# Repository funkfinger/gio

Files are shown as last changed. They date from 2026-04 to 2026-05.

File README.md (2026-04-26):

# gio

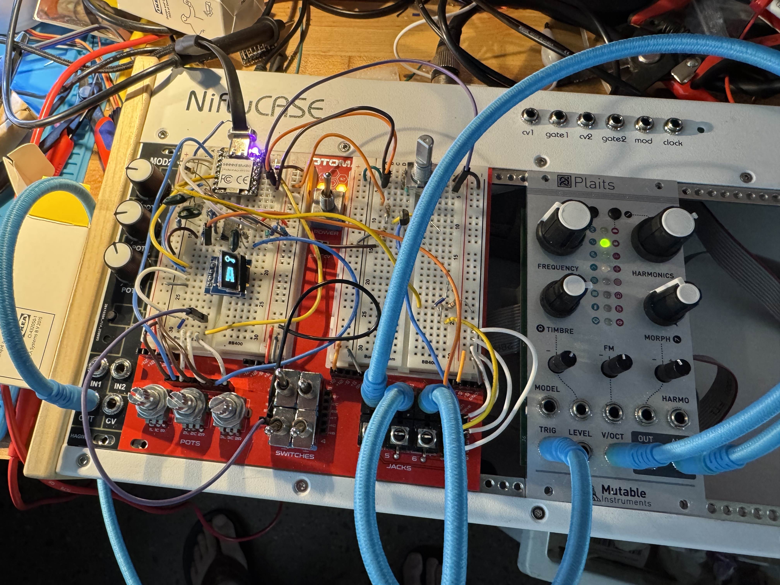
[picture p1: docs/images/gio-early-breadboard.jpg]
gio on the breadboard


A 2 HP Eurorack generative arpeggiator module built around the Seeed XIAO RP2350. Produces scale-quantised V/Oct pitch CV and gate outputs driven by a probability-layered generative engine. Open-source hardware and firmware.

Spiritual successor to [funkfinger/xiao-ra4m1-arp](https://github.com/funkfinger/xiao-ra4m1-arp), ported to the RP2350 with an encoder + OLED UI and an external I2C DAC (MCP4725) in place of the RA4M1's onboard DAC.

## Status

**Planning / pre-prototype.** No hardware fabricated yet; no firmware released. See [`docs/decisions.md`](docs/decisions.md) for the bring-up plan and [`docs/stories/`](docs/stories/) for the story-driven development backlog.

## Repo layout

```
gio/
├── firmware/arp/     PlatformIO project for the arpeggiator firmware
├── hardware/         KiCad project — populated post-breadboard validation
├── docs/             Specification, decisions, user stories
└── CHANGELOG.md      Keep a Changelog format; updated on every commit
```

## Documentation

- **[Specification](docs/generative-arp-module.md)** — hardware spec, firmware architecture, BOM, calibration
- **[Decisions](docs/decisions.md)** — tooling, scope, workflow, licensing, versioning
- **[Stories](docs/stories/)** — user-story-driven development backlog

## Toolchain

- **Firmware:** [PlatformIO](https://platformio.org/) with the earlephilhower Arduino-Pico platform (`board = seeed_xiao_rp2350`)
- **Tests:** host-side unit tests via `pio test -e native` for pure-logic modules (scales, arp, tempo). HAL is bench-verified.
- **Hardware:** KiCad (project deferred — see decisions)
- **CI:** GitHub Actions runs host tests on push and PR

## Versioning

- **Firmware:** [Semantic Versioning](https://semver.org/), scoped tags per firmware: `arp/v0.1.0`
- **Hardware:** `Rev N.M` notation, silkscreened on the PCB
- **Docs:** unversioned; history lives in `git log`

See [decisions §12](docs/decisions.md) for full rules.

## Licensing

| Area | License | File |
|---|---|---|
| Firmware | MIT | [`LICENSE-firmware`](LICENSE-firmware) |
| Hardware (KiCad, panel artwork) | Apache 2.0 | [`LICENSE-hardware`](LICENSE-hardware) |
| Documentation | CC-BY 4.0 | [`LICENSE-docs`](LICENSE-docs) |

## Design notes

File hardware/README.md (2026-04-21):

# hardware/

KiCad schematic and PCB for the gio module.

**This directory is intentionally empty until breadboard validation is complete.**

Per `docs/decisions.md` §7: the KiCad project is deferred until the breadboard signal chain (MCP4725 → MCP6002 → V/Oct output) is validated within ±2 mV of target voltages and the I2C bus sharing between DAC and OLED is confirmed clean.

The gate resistor value (R4) was a known source of V/Oct loading error in the predecessor project — confirmed to 100 Ω before PCB layout begins.

When ready, this directory will contain:

```
hardware/
├── gio.kicad_pro
├── gio.kicad_sch
├── gio.kicad_pcb
├── panel/
│   └── gio-panel.kicad_pcb
├── gerbers/
│   └── (generated outputs for JLCPCB)
└── bom/
    └── gio-bom.csv
```

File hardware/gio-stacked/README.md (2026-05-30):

# gio-stacked

A 4 HP Eurorack module — three-board stacked redesign of `hardware/gio/`.

## Status

**Planning / scaffolding.** No KiCad files yet. This directory captures the
architecture decisions before schematic work begins. Each subdirectory
(`power/`, `signal/`, `faceplate/`) will become its own KiCad project in a
subsequent session.

## Why split into three boards

The original `hardware/gio/` is a single 4 HP PCB. That layout was tight
but workable for the v0.1 feature set. The expanded feature set for this
revision — 6 jacks (was 4), tap-tempo button, same OLED + pot + encoder —
runs out of PCB area on a single-board 4 HP design once you account for the
through-hole jacks, the OLED breakout footprint, the encoder + pot bodies,
and the Eurorack power header + bulk caps + regulators.

Three stacked boards solve this by trading depth for area:

| Board | Carries |
|---|---|
| **power/** | Eurorack ±12 V header + reverse-polarity + bulk caps + +5 V LDO + REF3040 (4.096 V reference) |
| **signal/** | XIAO RP2350 + DAC8552 + MCP3208 + TL072 input/output op-amp stages + NeoPixel |
| **faceplate/** | 6× Thonkiconn jacks + PEC11 encoder + Alpha 9 mm pot + SSD1306 OLED + tactile button + panel silkscreen |

The faceplate is a real PCB (not just a milled aluminum panel) — it carries
the jacks, OLED breakout footprint, and button, and connects to the signal
board through a single 2.54 mm pin header.

## Inheritance from `hardware/gio/`

Direct re-use (schematic blocks, footprints, calibration):

- **MCU** — Seeed XIAO RP2350
- **DAC** — TI DAC8552 (12-bit, dual, SPI)
- **ADC** — MCP3208 (12-bit, 8-channel, SPI). Now uses CH3 + CH4 for the two new CV ins.
- **Reference** — TI REF3040 (4.096 V, 0.2 %)
- **Op-amps** — TL072 × 2 (±12 V rails). Same input scaling stage (100 kΩ + 22 kΩ + BAT54S clamp + 22 kΩ feedback) replicated 4× for the four CV ins. Same output stage (44 kΩ feedback + 1 kΩ jack series + BAT54S clamp) × 2 for the two outs.
- **Calibration** — copy the bench-fit constants from `firmware/arp/src/main.cpp`
  (channel-symmetric op-amp stages — see `bench-log.md` 2026-05-21).

New for this revision:

- **2 additional CV inputs** (J5, J6) — same scaling stage as J1/J2, routed to MCP3208 CH3 + CH4.
- **Tap-tempo / reset button** — tactile switch on faceplate, wired to XIAO D0 (currently free; was the analog pot pin pre-pivot).
- **Inter-board connectors** — 2.54 mm pin headers (see `docs/interconnect.md`).
- **Mechanical stack** — M2.5 standoffs at 4 corners (see `docs/stackup.md`).

## Panel layout target (4 HP × 128.5 mm)

Top to bottom:

```
┌────────────┐
│   OLED     │  64×32 SSD1306
├────────────┤
│  encoder   │  PEC11 + click
├────────────┤
│    pot     │  Alpha 9 mm
├────────────┤
│   button   │  6×6 mm tactile (tap-tempo)
├────────────┤
│  J1    J2  │  CV in 1   CV in 2 (clock in / V/oct)
│  J3    J4  │  CV in 3   CV in 4 (new — modulation dests)
│  J5    J6  │  CV out    Trigger out (V/oct, gate)
└────────────┘
```

Two columns of 3 jacks fit in 4 HP with 6 mm Thonkiconn nuts at ~7 mm
center-to-center pitch. Final positions in `docs/faceplate-layout.md`.

## Project layout

```
hardware/gio-stacked/
├── README.md                  ← this file
├── docs/
│   ├── decisions.md           ← architecture rationale, decisions log
│   ├── interconnect.md        ← board-to-board pin assignments
│   ├── faceplate-layout.md    ← panel positions, hole sizes, silkscreen
│   └── stackup.md             ← mechanical: standoffs, board heights, clearances
├── power/                     ← Power board KiCad project (TBD)
├── signal/                    ← Signal board KiCad project (TBD)
└── faceplate/                 ← Faceplate KiCad project (TBD)
```

## BOM additions vs `hardware/gio/`

- 2× Thonkiconn PJ-3.5mm jacks (6 total instead of 4)
- 1× tactile button (Omron B3F-1000 or equivalent, 6×6 mm)
- 2× 2.54 mm pin header + socket pairs (1× 2×5 power↔signal, 1× 2×14 or 2×16 signal↔faceplate)
- 4× M2.5 standoffs (length TBD — see `docs/stackup.md`)
- 8× M2.5 screws

Everything else (XIAO, DAC, ADC, op-amps, reference, OLED, encoder, pot, BAT54S, decoupling caps, resistors) is the same as `hardware/gio/bom.md` — quantities adjust per board.

## Build / fabrication plan (rough)

1. Schematic for each of the 3 boards (this is the next session's work).
2. Mechanical mockup — print 1:1 paper templates of all three boards + faceplate to verify spacing before PCB layout.
3. Place + route signal board first (densest, hardest constraint).
4. Place + route power board.
5. Place + route faceplate (mostly through-hole, easy).
6. ERC + DRC pass on all three.
7. Manufacturing files (gerbers, BOM, CPL) per board.
8. JLCPCB order (3 boards × 5 each = 15 PCBs; ~$30 with shipping).
9. Hand-assemble + bench-bring-up each board independently before stacking.

## Open questions (deferred)

- Exact standoff height — depends on tallest signal-board component (likely bulk caps; finalized at parts-placement time).
- Whether the NeoPixel stays on the XIAO board (signal stack) or migrates to the faceplate for visibility through a light-pipe.
- Whether to add a second button (encoder-already-has-click, tap-tempo separately, plus a third would need pin budget review).

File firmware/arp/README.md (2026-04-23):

# firmware/arp

PlatformIO project for the gio arpeggiator firmware targeting the Seeed XIAO RP2350.

## Prerequisites

- [PlatformIO Core](https://docs.platformio.org/en/latest/core/installation/index.html) (CLI) or PlatformIO IDE extension
- USB-C cable

## Build

```bash
pio run -d firmware/arp
```

## Upload

```bash
pio run -d firmware/arp --target upload
```

That's it — **no button-press needed for normal re-flashes.** PlatformIO uses `picotool` as the default upload protocol for this board, and the running firmware exposes a USB endpoint that lets `picotool` send a "reboot to bootloader" request. The board soft-resets, picotool flashes, then it reboots into the new firmware.

You only need manual BOOTSEL when:

- **First-flash of a fresh XIAO** (no firmware to soft-reset from yet).
- **Firmware is hung / crashed before USB came up** (rare — you'd notice the board not appearing in `ls /dev/tty.usbmodem*`).
- You ever flash bare metal or strip out the picotool USB endpoint.

### Manual BOOTSEL (when needed)

The "double-tap BOOT" trick advertised by Seeed is **unreliable on the XIAO RP2350 units we've used** — bench-confirmed across many flashes during Stories 002–010. The method that always works:

1. Unplug USB.
2. Hold the BOOT button down.
3. Plug USB in (still holding BOOT).
4. Release BOOT — `RP2350` mounts as a drive.

Then run the upload command as above (in this state, picotool detects BOOTSEL directly without needing the soft-reset path).

## Host-side unit tests

Pure-logic modules (scales, arp, tempo) are tested on the host — no board required:

```bash
pio test -d firmware/arp -e native
```

GoogleTest requires an explicit `main()` in each test file (PlatformIO 6.x does not auto-link `gtest_main`).

## Serial monitor

```bash
pio device monitor -d firmware/arp
```

Baud rate: 115200.

## Library notes

- **Adafruit SSD1306 + GFX** — OLED driver. Three-constant config block in `lib/oled_ui/oled_ui.h` (`OLED_WIDTH`, `OLED_HEIGHT`, `OLED_ROTATION`) handles the swap between bench (0.91" 128×32 landscape) and final design (0.49" 64×32 portrait).
- **mathertel/RotaryEncoder** — polling-based quadrature encoder. RP2350-compatible. `paulstoffregen/Encoder` is incompatible (AVR-only register macros). LatchMode = `FOUR3` for our PEC11 build (decisions §17).
- **Adafruit NeoPixel** — onboard RGB LED on **GPIO22** (data) + **GPIO23** (power-enable, hold HIGH). LED is **RGBW** — initialise with `NEO_GRBW + NEO_KHZ800`. Neither pin is exposed by the arduino-pico variant header; both are hardcoded in `src/main.cpp`.

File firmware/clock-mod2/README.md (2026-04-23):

# firmware/clock-mod2

Minimal bench clock source for a HAGIWO MOD2 board populated with a XIAO RP2350. Exists primarily to feed a clock signal into `gio`'s J1 input during Story 010 bring-up and beyond — but it's a standalone useful module on its own.

## What it does

- **POT1 (A0)**: sets the clock rate. Exponential curve, 20–300 BPM (via the shared `tempo::potToBpm()`).
- **GP1**: drives the MOD2 output stage. 50 % duty square wave — scaled to ~0→10 V at the jack by the on-board op-amp.
- **GP5**: panel LED blinks in sync with each rising edge. Works on USB power alone, so you can verify the rate before putting the module back in the rack.
- POT2, POT3, CV in, button, IN1, IN2: unused in v1.

## Hardware requirements

- HAGIWO MOD2 PCB, populated with XIAO RP2350.
- **C18 (1 µF series cap on the OUT path) must be bypassed** for DC coupling. JP2 is *meant* to do this — see "JP2 board issue" below.
- ±12 V Eurorack power for the op-amp output stage. USB power alone runs the XIAO and LED but the output stays at 0 V.

## JP2 board issue (this build, Rev A)

The MOD2 schematic shows JP2 as a solder-bridge bypass across C18 (1 µF). When the bridge is closed, the OUT path is DC-coupled and produces clean 0→10 V gates. When open, the path is AC-coupled through C18 and an output square wave appears at the J6 jack as differentiated spikes (positive and negative, decaying with τ ≈ 100 ms via R20 = 100 kΩ).

**On this physical build, soldering JP2 had no effect.** Multimeter continuity confirmed JP2's pads were bridged after soldering, but the bypass didn't reach C18 — apparently the JP2 PCB traces don't route to C18's pads on this revision (board defect or layout error). Confirmed by directly clipping across C18's terminals: signal becomes a clean square wave immediately.

**Fix on this build:** solder a small wire (or 0 Ω resistor) directly across C18's pads. Permanent and reliable.

**Lesson for gio Rev 0.1 PCB:** before fab, verify that every solder-jumper symbol's connections in the schematic actually route to the correct nets in the layout (a quick ERC + DRC + visual on the JP nets). See `docs/decisions.md` "Deferred decisions" for the gio implication.

## Build

```bash
pio run -d firmware/clock-mod2
```

Shares toolchain with `firmware/arp` — the same pinned `framework-arduinopico@4.4.0` via `maxgerhardt/platform-raspberrypi`. Reuses `../arp/lib/tempo/` via `lib_extra_dirs` so BPM math stays in lock-step with gio.

## Upload

```bash
pio run -d firmware/clock-mod2 --target upload
```

Same workflow as the gio firmware — `picotool` soft-resets the board into BOOTSEL via USB, no button-press needed for normal re-flashes. Manual BOOTSEL only required for first-flash of a fresh XIAO or recovery. See `firmware/arp/README.md` for the manual procedure.

## Serial monitor

```bash
pio device monitor -d firmware/clock-mod2
```

Baud: 115200. Mostly quiet — just a startup banner.

## Wiring from MOD2 jack to gio J1

For Story 010 bench use:

- **MOD2 J6 (OUT)** tip → **gio J1** tip (through the 100 k + 100 k divider we're building for J1).
- **MOD2 GND** → **gio GND** (through the common Eurorack ground, or a jumper if both on the same bench).

MOD2 is an ~0→10 V gate source; gio's input divider brings that down to a safe ADC level.

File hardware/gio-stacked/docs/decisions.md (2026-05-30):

# gio-stacked architecture decisions

Scoped to this subproject. The parent `/docs/decisions.md` covers
platform-level decisions; this file covers what's specific to the
three-board redesign.

---

## 1. Three stacked boards (power / signal / faceplate)

A single 4 HP PCB ran out of area for the expanded feature set (6 jacks
instead of 4, tap-tempo button, same OLED + pot + encoder). Splitting into
three depth-stacked boards trades vertical real estate for layout headroom.

**Why three (not two):**
- Faceplate must be a PCB to hold jacks + encoder + pot + button + OLED on its back side — that's one PCB by necessity
- Power circuitry (Eurorack header, bulk caps, ±12 V regulators, REF3040) on its own board isolates supply noise from the signal-domain analog stages and keeps the heavy/bulky components (caps, regulators) at the back of the module
- Signal board in the middle is pure SMD — easy to lay out densely without competing for area with through-hole jacks or bulk power components

**Why not two (signal + faceplate, with power on the signal board):**
- Tried mentally — power components compete with the dense SMD analog stages for area on signal. Splitting them out lets each board be optimized for its dominant component class.

## 2. 2.54 mm pin-header interconnect (vs board-to-board / castellated)

Standard 0.1" pin headers with female sockets across each board junction.

**Why:**
- Trivially sourceable, cheap (~$0.50 per pair).
- Hand-solderable on both sides.
- Probable at each pin for bench debugging — you can lift one board off the stack and clip a scope probe to any signal mid-development.
- Compatible with through-hole prototyping (perfboard adapter, breakout cable for early bring-up).

**Trade-off:** less compact than board-to-board connectors (Pico-Lock), no polarization. We accept the polarization risk by recommending shrouded headers on `J_PWR` where reversal is dangerous; `J_FACE` ships un-shrouded with clear silkscreen orientation marks.

## 3. Same MCU + analog stack as `hardware/gio/`

Keep XIAO RP2350, DAC8552, MCP3208, REF3040, TL072s. Don't change horses
mid-stream; the platform is bench-validated. Calibration constants from the
v1 design carry over directly (op-amp stages are channel-symmetric per
`bench-log.md` 2026-05-21).

The two new CV ins (J3, J4 in panel layout — channels 3 and 4 in firmware)
duplicate the existing input stage. MCP3208 has 5 unused channels (CH3–CH7);
we're claiming two of them, leaving 3 for future expansion.

## 4. Tap-tempo button on XIAO D0

D0 was freed when the tempo pot moved to MCP3208 CH0 (pre-pivot, the pot was
on D0 as a native analog input). It's the only free GPIO on the XIAO that
isn't part of SPI / I²C / encoder. Wire the button between D0 and GND, use
the RP2350 internal pull-up, debounce in firmware.

If a second button is ever wanted, options are: another MCP3208 channel
read as a digital threshold (works but uses analog bandwidth), an I²C
button expander (cheap, but adds a part), or sharing the OLED `OLED_RST`
pin if we hard-wire OLED reset and free that line.

## 5. Faceplate is a real PCB (FR4 with black soldermask)

Not milled aluminum. Decision driven by mechanical: the jacks, button, OLED
breakout headers, encoder, and pot all need to physically mount somewhere,
and a PCB is the cheapest sane mounting surface. Aluminum panels would
require a separate "jack PCB" behind them anyway, defeating the purpose.

Visual: black soldermask + matte finish + white silkscreen approximates a
"black panel" look adequately for a DIY/boutique aesthetic. Not as premium
as anodized aluminum but well within DIY norms.

## 6. Maximum depth ≈ 40 mm — at Eurorack standard limit

Three PCBs (1.6 mm each = 4.8 mm) + 14 mm + 13 mm standoffs + 9 mm Eurorack
header = 40.8 mm. Standard Doepfer A-100 cases allow 40 mm before the bus
board interferes. We have ~zero margin.

Trim path if needed at fab time: reduce the signal-to-power standoff from
13 mm to 10 mm (requires signal-board components to fit in the smaller gap)
or use SOT-223 instead of TO-220 for the LDO. Defer until parts placement
reveals which constraint is binding.

## 7. Inter-board pinouts locked before schematic work

`docs/interconnect.md` is the contract. With the pinouts fixed, the three
boards can be schematic-designed independently; the only thing they need to
agree on is the pin assignment + connector footprint. Avoids the failure
mode where you finish two boards and discover they have incompatible
expectations of which pin carries which signal.

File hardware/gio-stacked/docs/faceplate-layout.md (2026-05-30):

# Faceplate layout

4 HP Eurorack panel — 20.32 mm wide × 128.5 mm tall (3U). All positions
in mm relative to the **top-left corner of the panel**.

Iteration target: this is the v1 layout to mock up on paper. Real positions
get finalized when KiCad placement happens and we can see exact component
footprints in the editor.

## Mounting holes

Standard Eurorack pattern — 3 mm holes, M3 screws, recessed for the rails.

| Hole | X (mm) | Y (mm) |
|---|---|---|
| TL | 3.0 | 3.0 |
| TR | 17.3 | 3.0 |
| BL | 3.0 | 125.5  |
| BR | 17.3 | 125.5  |

Vertical spacing 122.5 mm (standard 3U). Horizontal: 14.3 mm (4 HP).

## Component placement

```
        ┌──────────────────┐  ← y = 0
        │                  │
        │     ┌──────┐     │  ← y = 8  (OLED top)
        │     │ OLED │     │
        │     └──────┘     │  ← y = 22 (OLED bottom)
        │                  │
        │      (○)         │  ← y = 35 (encoder center)
        │                  │
        │                  │
        │      (○)         │  ← y = 55 (pot center)
        │                  │
        │       •          │  ← y = 72 (button center)
        │                  │
        │   ◯       ◯      │  ← y = 88 (J1, J2 row)
        │                  │
        │   ◯       ◯      │  ← y = 100 (J3, J4 row)
        │                  │
        │   ◯       ◯      │  ← y = 112 (J5, J6 row)
        │                  │
        └──────────────────┘  ← y = 128.5
```

| Component | X (mm) | Y (mm) | Hole / footprint |
|---|---|---|---|
| OLED breakout (SSD1306 64×32, 0.49") | center, mounted on faceplate via 4× M2 standoffs to signal-board headers | ~15 (top of viewport) | breakout is ~25×11 mm; cutout in faceplate ~14×8 mm for the active display area only |
| Encoder (PEC11) | 10.16 (center) | 35 | 7 mm round hole + 2 mm anti-rotation hole |
| Pot (Alpha 9 mm) | 10.16 | 55 | 7 mm round hole + 2 mm anti-rotation hole |
| Tactile button (B3F-1000) | 10.16 | 72 | 4 mm round hole for tip; SMD or TH body soldered to faceplate PCB |
| J1 (CV in 1 / clock) | 6.5  | 88  | 6 mm Thonkiconn hole |
| J2 (CV in 2 / V/oct) | 13.8 | 88  | 6 mm |
| J3 (CV in 3, new) | 6.5  | 100 | 6 mm |
| J4 (CV in 4, new) | 13.8 | 100 | 6 mm |
| J5 (CV out, V/oct)  | 6.5  | 112 | 6 mm |
| J6 (Trigger out) | 13.8 | 112 | 6 mm |

**Center column at X = 10.16 mm** (panel half-width). Jack columns offset
±3.66 mm gives 7.32 mm center-to-center — fits 6 mm Thonkiconn nuts with
~1.3 mm flesh between them. Tight but standard.

**Jack row pitch 12 mm** — enough for the nut + a sliver of silkscreen label
underneath each jack ("CLK", "CV", "V/O", "GATE", etc.).

## Silkscreen plan

- Module name "gio" at top, above the OLED
- Tiny label under each jack (3-letter abbreviations)
- Optional: param-name reminders next to encoder + pot
- Version "v2" or revision number at bottom

## Faceplate-PCB vs aluminum-only

This is a real PCB acting as a faceplate (FR4 with black soldermask + white
silkscreen for the "look"). Trade-offs:

- **Pro:** components mount directly (jacks, encoder, pot, button, OLED breakout headers) — no panel wiring to a separate PCB. Mechanically robust.
- **Pro:** silkscreen is easy (no anodizing / paint mask).
- **Con:** less premium feel than milled aluminum. Black soldermask + matte finish gets close but isn't identical.
- **Con:** FR4 panel can flex if the user pushes hard on the encoder — mitigated by the 4-corner standoffs to the signal board.

Decision is locked in by the three-board architecture (faceplate must be a
PCB to hold the components on its back side).

## Open questions

- OLED breakout style — solder directly to faceplate (back side), or use a
  pin header + socket so it's removable? (Removable = easier rework, but
  adds depth to the stack.)
- Indicator LED — current design has the NeoPixel on the XIAO (signal board), invisible behind the faceplate. Options: (a) light pipe to faceplate, (b) move NeoPixel to faceplate with one extra signal across J_FACE, (c) accept it as internal-only.
- Anti-rotation tabs on encoder + pot — most have one; verify orientation matches our hole pattern.

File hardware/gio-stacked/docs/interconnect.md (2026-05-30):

# Inter-board connectors

Two 2.54 mm pin header / socket pairs join the three boards. Pin assignments
locked in here BEFORE schematic work so the boards can be developed
independently and verified against this contract.

---

## J_PWR — Power ↔ Signal (2×5, 10 pin, 2.54 mm)

Carries Eurorack rails + regulated supplies + voltage reference from the
power board to the signal board. Mirrored layout pairs each rail with an
adjacent GND for low loop area / good return paths.

```
                top of stack
                ─────────
   +12V  ●  ●  +12V        ← Eurorack +12 V (in)
   GND   ●  ●  GND
  -12V   ●  ●  -12V        ← Eurorack -12 V (in)
   GND   ●  ●  GND
   +5V   ●  ●  +VREF       ← +5 V regulated; +VREF = 4.096 V (REF3040)
                ─────────
              power board ←→ signal board
```

| Pin | Signal | Direction | Notes |
|-----|---|---|---|
| 1, 2 | +12V | power → signal | Eurorack rail, pre-regulator. Decouple at consumer. |
| 3, 4 | GND  | bidirectional | |
| 5, 6 | -12V | power → signal | Eurorack rail. |
| 7, 8 | GND  | bidirectional | |
| 9 | +5V  | power → signal | Linear-regulated from +12V on the power board (XIAO USB-disconnected operation). |
| 10 | +VREF | power → signal | 4.096 V from REF3040. Shared by DAC8552 + MCP3208 for ratiometric scaling. |

**Connector parts:**
- Header (power board): 2×5 male, 2.54 mm, vertical
- Socket (signal board): 2×5 female, 2.54 mm, vertical (or shrouded for keying)
- TBD: keyed/shrouded vs un-keyed (reversibility risk → consider shrouded)

---

## J_FACE — Signal ↔ Faceplate (2×14, 28 pin, 2.54 mm)

Carries jack tip signals, jack sleeve return, panel control I/O (encoder,
pot, button), and the OLED I²C bus + power between the signal board and
the faceplate.

```
                top of stack
                ────────────
 +3V3   ●  ●  GND               ← OLED + encoder + pot supply
 SDA    ●  ●  SCL               ← I²C (OLED)
 OLED_RST ● ● ENC_A             ← OLED reset (optional, may tie high); encoder A
 ENC_B  ●  ●  ENC_CLICK         ← encoder B; encoder click
 POT_W  ●  ●  BTN1              ← pot wiper; tap-tempo button
 J1_TIP ●  ●  J2_TIP            ← CV in 1 (clock); CV in 2 (V/oct)
 J3_TIP ●  ●  J4_TIP            ← CV in 3; CV in 4
 J5_TIP ●  ●  J6_TIP            ← CV out (V/oct); Trigger out
 GND    ●  ●  GND               ← jack sleeves (commoned)
 GND    ●  ●  GND               ← spare returns
 NC     ●  ●  NC                ← spare / future expansion
 NC     ●  ●  NC                ← spare / future expansion
 NC     ●  ●  NC                ← spare / future expansion
 GND    ●  ●  GND               ← endcap GND for shield/strain relief
                ────────────
              signal board ←→ faceplate
```

| Pin | Signal | Direction | Notes |
|-----|---|---|---|
| 1 | +3V3 | signal → face | Powers OLED, encoder pull-ups, pot top |
| 2 | GND | bidirectional | |
| 3 | SDA | bidirectional | I²C data (XIAO Wire1 SDA, GP6) |
| 4 | SCL | signal → face | I²C clock (XIAO Wire1 SCL, GP7) |
| 5 | OLED_RST  | signal → face | Optional — most SSD1306 breakouts tie internally |
| 6 | ENC_A | face → signal | Encoder phase A (XIAO D1) |
| 7 | ENC_B | face → signal | Encoder phase B (XIAO D2) |
| 8 | ENC_CLICK | face → signal | Encoder button (XIAO D7) |
| 9 | POT_W | face → signal | Pot wiper (to MCP3208 CH0) |
| 10  | BTN1 | face → signal | Tap-tempo button (XIAO D0, with internal pull-up + debounce in FW) |
| 11  | J1_TIP | face → signal | CV in 1 / clock — to TL072 input stage ch 1 |
| 12  | J2_TIP | face → signal | CV in 2 / V/oct — to TL072 input stage ch 2 |
| 13  | J3_TIP | face → signal | CV in 3 (new) — to TL072 input stage ch 3 |
| 14  | J4_TIP | face → signal | CV in 4 (new) — to TL072 input stage ch 4 |
| 15  | J5_TIP | signal → face | CV out (V/oct) — from TL072 output stage ch A |
| 16  | J6_TIP | signal → face | Trigger out — from TL072 output stage ch B |
| 17, 18 | GND | bidirectional | Jack sleeves commoned |
| 19, 20 | GND | bidirectional | Spare returns for noise/shielding |
| 21–26 | NC | — | Spare. Reserved for future expansion (additional jack, second button, NeoPixel-on-faceplate signal, etc.) |
| 27, 28 | GND | bidirectional | Mechanical endcap GND |

**Why 2×14:** signal count (~16 active signals) + GND spread (~8 pins) +
spare expansion (~6 pins) = 28 well-utilized pins. Keeps a single connector
per junction; alternatives (split into two smaller connectors for analog vs
digital) add mechanical complexity for no real noise win at this signal density.

**Connector parts:**
- Header (signal board): 2×14 male, 2.54 mm, vertical
- Socket (faceplate): 2×14 female, 2.54 mm, vertical
- Same TBD-shrouded question as J_PWR.

---

## Routing rules (both connectors)

- Adjacent GND on every rail/signal pair where possible (already enforced in pinouts above)
- Keep analog signals (POT_W, JxTIP) away from SCL/SDA on the connector — they're on opposite ends of J_FACE by design
- DRC: 0.2 mm trace/space minimum for cost-tier JLCPCB
- Connector footprints must align across the 3 boards (same X/Y on both sides of each junction)

## Verification before fab

- Print 1:1 paper templates of all three boards
- Stack with cardboard between (proxy for standoff height)
- Mechanically verify connector alignment — both junctions should line up vertically with the standoff holes

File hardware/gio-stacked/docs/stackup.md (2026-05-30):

# Mechanical stackup

Three boards held parallel by 4× M2.5 standoffs at the panel mounting-hole
positions. Standoff lengths chosen so the tallest component on each board
clears the next board with a few mm of margin.

```
   Eurorack rails (top)
         │
         │ 3 mm clearance to top rail
         │
   ┌─────┴─────┐  ← faceplate PCB    (front of module — y = 0)
   │           │
   │   ~15 mm  │  ← faceplate standoff: jacks (10mm body) + PCB + clearance
   │           │
   ├───────────┤  ← signal PCB
   │           │
   │   ~13 mm  │  ← signal-to-power standoff: tallest signal-board component + clearance
   │           │
   ├───────────┤  ← power PCB        (back of module — depth ≈ 30 mm)
   │           │
   └───────────┘
   Eurorack power connector (back) — depth-limited to ~40 mm
```

## Standoff selection (preliminary — refine after parts placement)

| Junction | Standoff length | Why |
|---|---|-----|
| Faceplate ↔ Signal | 14 mm | Thonkiconn body ~10 mm + 2 mm clearance + 2 mm signal-board component headroom |
| Signal ↔ Power | 13 mm | Signal-board headers/op-amps ~5 mm + power-board bulk caps ~6 mm + clearance |
| Total stack depth | ~30 mm | (faceplate PCB 1.6 + 14 + signal PCB 1.6 + 13 + power PCB 1.6) — within typical Eurorack 40 mm depth budget |

**M2.5 hex female-female standoffs** at all four corners, in brass or
stainless. Common lengths available: 10, 12, 15, 18 mm — round up to nearest
stocked length and re-verify clearance.

## Component-height assumptions (verify at placement)

**Signal board (between faceplate and power):**
- XIAO RP2350 module: ~3 mm above PCB
- DAC8552, MCP3208, TL072s: SOIC, ~2.5 mm
- 2.54 mm pin header (to faceplate): 8 mm above PCB when mated
- 2.54 mm pin header (to power): 8 mm above PCB when mated (downward)
- **Tallest:** the inter-board headers themselves at ~8 mm; clears the 13 + 14 mm standoff budget easily

**Power board (back of stack):**
- Bulk caps (radial 100 µF / 220 µF, 10 V or higher): ~10–13 mm tall
- LDO (78L05 or LM78M05 in TO-220 / SOT-223): ~10 mm if TO-220, ~3 mm if SOT-223
- REF3040 SOT-23: ~1 mm
- Eurorack 2×5 IDC header: ~9 mm
- **Tallest:** bulk caps or LDO TO-220 at ~10–13 mm; faces AWAY from signal board (toward back of module), so this height doesn't impact the inter-board gap

**Faceplate (front):**
- Thonkiconn jacks: 10 mm body depth (rear of PCB toward signal board)
- Encoder: 12–15 mm body, but encoder body protrudes FORWARD (through panel), not backward
- Pot: 9 mm body, similar — protrudes forward
- OLED breakout: ~3 mm thick PCB + 0.49" glass on the front
- Button: 6 mm body, low profile
- **Tallest rear-facing component:** Thonkiconn jacks at 10 mm — drives the faceplate-to-signal-board standoff length

## Eurorack depth budget

| Item | Depth (mm) |
|---|---|
| Faceplate PCB thickness | 1.6 |
| Standoff faceplate ↔ signal | 14 |
| Signal PCB thickness | 1.6 |
| Standoff signal ↔ power | 13 |
| Power PCB thickness | 1.6 |
| Eurorack header (rear-facing) | 9 |
| **Total module depth** | **40.8** |

Standard Eurorack cases (Doepfer A-100) allow ~40 mm depth in the rear bay
before clearing the bus board. This is at the limit. Two ways to trim:

- Shorter signal-to-power standoff (10 mm instead of 13) if signal-board components allow → -3 mm total
- Surface-mount power components instead of TO-220 LDO → may allow 10 mm power-side standoff

Track depth carefully during placement; trim if needed.

## Anti-rotation / alignment

Both inter-board connectors are symmetrical (2×N pin headers), so they can
in principle be inserted reversed. Mitigation options:

- **Shrouded headers** with polarized key — adds cost (~$0.50/connector) but eliminates reverse-insert risk
- **Mechanical pin keying** — drill an extra alignment pin hole at a non-symmetric position
- **Silkscreen + careful labeling** — cheapest, relies on the builder

Recommend shrouded headers for the J_PWR connector (rail reversal would be
catastrophic — reverse-polarity protection on the power board would catch
it but the BAT54S/diode would dissipate the full short-circuit current
briefly). J_FACE less critical; can ship un-shrouded with clear silkscreen.

## Open questions

- Final standoff lengths — depends on actual component heights from placement
- Whether the OLED breakout sits on the faceplate (mounted to faceplate-back via low-profile header) or on the signal board with a window cutout in the faceplate
- Whether to add front-panel LEDs (would need light pipes through the faceplate)

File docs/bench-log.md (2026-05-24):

# Bench Log

Measurements from hardware bring-up, ordered chronologically. Referenced by stories and calibration notes.

---

## 2026-04-21 — Story 003: PWM DAC ramp through 2-pole RC filter

**Setup:** XIAO RP2350 on breadboard, firmware sweeping `analogWrite(D2, 0..4095)` at ~10 Hz, 12-bit, `analogWriteFreq(36621)`. RC filter: D2 → 10 kΩ → node A → 10 kΩ → node B, 100 nF from each node to GND. No op-amp.

**Observations (visual scope inspection, no screenshots captured):**

| Probe point | Result | Pass? |
|---|---|---|
| D2 raw | ~36.6 kHz square, duty visibly sweeping 0→100%, 0–3.3 V swing. Edges show breadboard ringing — cosmetic. | ✓ |
| After 1-pole (node A) | Sawtooth ramp 0→3.3 V with PWM ripple riding on it. Falling edge has visible exponential discharge curve (cap discharging through 10 kΩ when duty snaps 4095→0). Expected; τ ≈ 1 ms. | ✓ |
| After 2-pole (node B) | Smooth ramp, no visible ripple at 50 mV/div. | ✓ |
| ADC noise on A0 with PWM running | **Deferred to PCB stage.** Breadboard coupling is not predictive of PCB layout; will revisit during board bring-up. See decisions.md §3, §7. | — |

**Conclusion:** PWM → 2-pole RC filter signal path is bench-validated. Op-amp scaling stage (Story 004) is the next addition.

---

## 2026-04-22 — Story 004: V/Oct op-amp scaling and calibration

**Setup:** MCP6002-I/P breadboarded after the 2-pole RC filter. Gain network: R_f = 2.2 kΩ + 470 Ω in series (= 2.67 kΩ, 2.7 kΩ unavailable in kit), R_g = 10 kΩ → nominal gain 1.267. R4 = 100 Ω output. 5 V from XIAO 5V pin, 100 nF decoupling close to chip. Op-amp B tied off as grounded buffer (pin 5 → GND, pin 6 → pin 7).

**Calibration result:** firmware `GAIN` updated from nominal 1.27 → measured **1.26** after first pass. Second pass confirms all 5 octave steps land within ±2 mV of target (≈±2.4¢). End-to-end through a VCO + tuner shows ≤±4¢ best-fit residual; one octave reads −7.7¢ interval error attributed to tuner-app measurement noise at 67 Hz. Full data tables in `calibration.md`.

**Conclusion:** V/Oct signal chain is bench-validated and within musical tracking spec. Module is now capable of driving a Eurorack VCO. Ready for Story 005 (first arp).

**Deferred:** ADC noise check (Story 003 carryover), CV input divider bench-verify (no story uses CV in yet), scope screenshots in `requirements/` (bench-log entries serving as record).

---

## 2026-04-22 — Story 005: arp plays up pattern (v0.1.0 milestone)

**Setup:** Story 004 V/Oct chain unchanged. Added BC548 NPN gate driver: D6 (GP0) → 1 kΩ base resistor → BC548 base; emitter → GND; collector → 10 kΩ pullup to 5V → J4. Firmware-side `GATE_INVERTED = true` so `gateWrite(true)` produces gate HIGH at the jack. V/Oct out patched to VCO V/Oct in; gate out patched to VCO/envelope gate in; VCO out → monitor.

**Result:** audible C3 → E3 → G3 → C4 up-arpeggio at 120 BPM (500 ms/step, 50 % gate duty). Onboard LED flashes in sync with each note. Sounds correct on bench.

**Conclusion: the module makes music for the first time.** End-to-end signal chain validated — scales/arp/tempo logic + PWM DAC + RC filter + op-amp scaling + NPN gate driver + LED beat indicator all working together.

**Library tests:** 34/34 host tests passing (`scales` 13, `arp` 11, `tempo` 10) via `pio test -e native`.

**Deferred:** scope screenshots and audio recording of the arpeggio (bench-log entry serving as record).

---

## 2026-04-22 — Story 006: tempo pot for live BPM control

**Setup:** B-taper pot (10 kΩ used) wired between 3V3 and GND with wiper to A0 (D0/GP26). No filter cap; firmware samples ADC at step boundaries only.

**Firmware:** `analogRead(A0)` at every step advance → `tempo::potToBpm()` (exponential 20..300 BPM) → `tempo::bpmToStepMs(bpm, 4)` for 16th-note subdivision.

**Range adjustment:** spec called for 40–300 BPM but bench feel was that 40 BPM 16ths still felt too fast at the slow end. Dropped `BPM_MIN` to 20. New slow extreme is ~750 ms/note (~1.3 notes/sec), which matches "ambient crawl" expectations. Story AC and tempo tests updated; per-third ratio is now 15^(1/3) ≈ 2.47× (still feels evenly distributed across pot rotation).

**Result:** pot turn translates immediately to perceived tempo change; arp speeds up and slows down smoothly across the full range. LED beat indicator stays in sync. No audible jitter or stuttering.

**Library tests:** 35/35 passing (added 1 new exponential-ratio test).

---

## 2026-04-22 — Story 007: OLED + encoder bring-up

**Setup:** SSD1306 0.91" 128×32 OLED on I2C (SDA=D4/GP6, SCL=D5/GP7, VCC=3V3, GND=GND, addr 0x3C). PEC11 encoder: A→D8 (GP2), B→D9 (GP3), Click→D10 (GP4), common→GND. Internal pullups on all encoder pins (no external Rs). Built-in 4.7 kΩ pullups on the OLED breakout — no external Rs needed.

**Display substitution:** bench bring-up uses the 0.91" 128×32 in landscape. Final design uses the 0.49" 64×32 in portrait. Swap is one config block in `lib/oled_ui/oled_ui.h` — `OLED_WIDTH`, `OLED_HEIGHT`, `OLED_ROTATION`. No code changes elsewhere.

**Firmware:** standalone bring-up (no arp). Encoder rotation increments/decrements an int counter; OLED shows live value. Encoder click flashes onboard LED + prints "CLICK" to USB serial.

**Result:** all four ACs verified — splash "HELLO" on power-up, counter responds to rotation in real time, click triggers LED+serial. No bus glitches; OLED refresh is fast enough to feel instant when turning the knob.

**Encoder library decision:** `mathertel/RotaryEncoder` chosen (polling-based, RP2350-compatible). Replaces `paulstoffregen/Encoder` which was removed back in Story 002 due to AVR-only register macros. Recorded in `decisions.md` §17.

**Library tests:** still 35/35 passing — `oled_ui` and `encoder_input` are HAL modules (no host tests; bench-verified only per story note).

---

## 2026-04-22 — Story 008: encoder menu (full integration)

**Setup:** all prior hardware in place — V/Oct chain, BC548 gate driver, tempo pot, OLED, encoder. No new wiring. Onboard RGB LED used for active-param indication (no external NeoPixel).

**Scope:** flat menu model (no submenu). Encoder click cycles which parameter is active (Scale → Order → Scale). Encoder rotate changes the active param's value. Long-press (≥500 ms) resets the arp.

**Audible behaviour:** the existing `lib/scales/quantize()` is now applied to each note before it goes to the DAC, so the menu's Scale selection genuinely changes what plays. Pent Min snaps E→Eb in the chord; Major leaves the major triad as-is; Chromatic is identity.

**Bench iterations during the story:**

1. **Encoder skipping every other detent** — initial latch mode `TWO03` was wrong for our PEC11. Switched to `FOUR0` (still skipping intermittently), then `FOUR3` — clean one-detent-per-option. Documented as the default in `decisions.md` §17.
2. **Long-press only fires on release** — refactored `EncoderInput` so the long-press latches the moment the threshold is crossed mid-hold; release of a long-press gesture is silent (no spurious short-click). User now feels tactile RESET feedback while still holding.
3. **NeoPixel dark at boot** — three issues stacked: (a) brightness was 24/255, too dim to see; bumped to 64. (b) discovered onboard LED is on **GPIO22 (data) + GPIO23 (power-enable)** per Seeed wiki — the variant header doesn't expose either; hardcoded both. (c) it's RGBW (4 bytes/pixel), not RGB; switched to `NEO_GRBW`. (d) needed a 20 ms settle delay between enabling power and the first `pixel.show()`.

**Result:** Scale and Order both selectable via encoder; OLED shows live state; LED green on Scale active, blue on Order; long-press resets cleanly. All Story 008 ACs satisfied.

**BOOTSEL quirk noted:** double-tap BOOT button doesn't reliably enter UF2 mode on this XIAO RP2350. Reliable method: hold BOOT while plugging in USB. Documented in `firmware/arp/README.md`.

**Library tests:** 35/35 still green (`Order1324` test renamed to `Skip` in `test_arp`).

---

## 2026-04-22 — Story 009: CV input for V/oct transpose (α-summing)

**Setup:** repurposed MCP6002 op-amp B (previously tied-off grounded buffer) as a unity-gain buffer after a 100 kΩ + 69 kΩ (47 + 22 in series) divider on J2. Buffer output → A1/GP27. Pot on bench (0..3.3 V) substituting for a real Eurorack source.

**Design path** (pre-coding grill): settled on α-summing over β-with-detection after realising the switched-jack detection wiring is fiddly and that Plaits actually uses α. Encoder ROOT sets the base; CV adds on top. Unplugged behaviour is identical to plugged-0 V. No new hardware part needed.

**Firmware delta:**
- Chord stored as intervals `{0, 4, 7, 12}` instead of absolute MIDI, summed with a runtime `root_midi = encoder root + CV transpose`.
- New menu item `ROOT` with 12 pitch classes pinned to MIDI octave 3. NeoPixel magenta when active.
- `lib/cv/cvVoltsToTranspose()` — pure-logic helper, host-tested (10 new cases; now 45/45 green total).
- Hysteresis wrapper around CV reads (½-semitone deadband) to kill ADC-noise flutter at snap boundaries.
- Live OLED update of the effective ROOT (encoder + CV, mod 12) with `*` suffix when CV is contributing.
- Played note clamped to MIDI [24, 96] to keep everything inside the DAC's range.

**Bench iterations:**
1. **"Pot doesn't change ADC" + "pitch too high"** — resolved as a loose breadboard connection plus a leftover jumper. Repaired.
2. **"High end of pot tops out as a single note"** — serial diagnostics showed transpose values of 48–50 semitones at ~75 % pot rotation, far higher than spec. Root cause: the "100 kΩ" series resistor was actually **100 Ω** (Brown-Black-**Brown** vs Brown-Black-**Yellow**). With a 100 Ω top leg and 69 kΩ bottom, divider ratio collapsed from the spec 0.408 to ~0.999 — nearly all wiper voltage made it through. Swapped in the correct 100 kΩ; transpose now scales cleanly across the pot range.
3. **UpDown "feels wrong"** — turned out to be ADC flutter near scale-snap boundaries; hysteresis wrapper (½-semitone deadband) fixed it.

**Result:** pot sweep now audibly transposes the arp through scale-snapped roots across the full rotation. Per-note quantize preserved — different scales give recognisably different chord "shapes" as you sweep. Effective ROOT on OLED updates live. Encoder ROOT still fully functional when CV is at 0 V.

**Tests:** 45/45 host tests green.

**Deferred:** BAT54 clamp on op-amp B input (Rev 0.1 PCB). Wrap-vs-clamp for overshooting played notes — clamp chosen as predictable.

---

## 2026-04-23 — Story 010: external clock input on J1 (with side quest)

**Setup:** new firmware reads J1 (D3 / GP5) via `digitalRead` for rising-edge detection. Auto-switches to external mode within 2 s of detected edges; falls back to internal tempo on timeout. Tempo pot becomes a clock divider (÷1, ÷2, ÷4) when external is active. OLED shows `INT` or `EXT` tag.

**Pin reassignment from spec:** the spec called for J1 on `A3` / `GP29`, but `GP29` is **not exposed** on the XIAO RP2350 (only GP0–GP7 top + GP9–GP12, GP16–GP17, GP20–GP21 bottom-pads). All ADC-capable pins (GP26/27/28) are taken (tempo pot, CV in, PWM out). J1 is therefore digital-only on this build; pitch mode on J1 is deferred until an ADC pin is freed (e.g. by replacing the tempo pot with encoder navigation).

**Side quest (separate session, same day):** built `firmware/clock-mod2/` to drive a HAGIWO MOD2 board as a bench clock source. Hit a board defect on the MOD2 — JP2 (solder bridge across C18 for AC/DC coupling) doesn't actually route to C18's pads on this PCB rev. Workaround: solder a wire across C18 directly. Documented in `firmware/clock-mod2/README.md` and `decisions.md` deferred section.

**RP2350-E9 silicon bug — main quest blocker:**
1. Built the spec'd 100 kΩ + 100 kΩ divider on J1.
2. With MOD2 patched in, `digitalRead(D3)` was stuck at HIGH. No edges ever detected.
3. Multimeter at D3 showed "low" sitting at ~2.13 V — well above the GPIO HIGH threshold (~1.6 V), so the GPIO never saw a true LOW.
4. Verified MOD2 output was a clean 0–8 V square wave (scope), GND was shared between boards, divider continuity was correct, divider input (post-resistor-A) was 0 V at low.
5. Disconnected D3 from the divider — divider output dropped cleanly to 0 V. So D3 itself was sourcing/holding ~2 V into the divider.
6. Tried `INPUT_PULLDOWN` instead of `INPUT` — no change.
7. Soldered in a fresh XIAO RP2350 (suspected ESD damage). Same result.
8. **User identified the silicon errata: [RP2350-E9](https://hackaday.com/2024/08/28/hardware-bug-in-raspberry-pis-rp2350-causes-faulty-pull-down-behavior/)** — when input buffer is enabled with internal pulldown, the pad latches at ~2.2 V. Pi Foundation workaround: external pulldown must be ≤ 8.2 kΩ.
9. **Fix:** swapped the divider from 100 kΩ + 100 kΩ → **10 kΩ + 10 kΩ**. Same 1:2 ratio (firmware unchanged) but now the bottom-leg 10 k is low enough to overpower the latched silicon-bug voltage. Edges detected immediately.

Total bench time on the RP2350-E9 hunt: ~90 minutes. Documented in `decisions.md` §18 so we don't repeat the error on Rev 0.1 PCB. Rule: any GPIO input that needs a pulldown gets an external resistor ≤ 8.2 kΩ.

**Result:** gio now correctly tracks external clock from MOD2. EXT badge appears on OLED. LED blinks per pulse. Divider zone hysteresis works. Disconnect cable → falls back to internal tempo within 2 s.

**Deferred:** pitch mode on J1 (needs an ADC pin freed up); BAT43 clamp on J1 input (Rev 0.1 PCB).

---

## 2026-04-29 — Stories 011 + 012 + 013 (channel A): SPI bring-up + DAC output stage

First post-pivot bench session. Goal: validate the entire signal chain from the XIAO firmware through SPI → DAC8552 → inverting summing amp → Eurorack-friendly bipolar jack output, on **channel A only** (channel B and the input stage deferred to next session).

**Setup:**
- XIAO RP2350 on female socket strips, plugged into Protomato breadboard (rails ±12 V / +5 V / GND verified clean).
- VREF stand-in: 10 kΩ multi-turn trimpot, divided +5 V → wiper, buffered through TL072 #1 channel A as a unity-gain follower. Channel B parked (pin 5 → GND, pin 6 → pin 7). Buffer output dialled to 4.096 V on the multimeter, locked.
- DAC8552 (MSOP-8 on a SOT/MSOP → DIP adapter): VDD=+5 V (pin 1), VREF tied to the buffered 4.096 V rail (pin 2), GND (pin 8), 100 nF decoupling at pin 1. SPI to XIAO: SCLK=D8 (pin 6), DIN=D10 (pin 7), /SYNC=D3 (pin 5). VOUTA (pin 4) → output stage. VOUTB (pin 3) not connected.
- TL072 #2 channel A: inverting summing amp with R_in = 10 kΩ from DAC8552 pin 4, R_fb = 2× 22 kΩ in series = 44 kΩ from pin 1, output through 1 kΩ series → jack J3 tip with BAT43 clamps to ±12 V. Channel B parked. Pin 8 = +12 V, pin 4 = −12 V, 100 nF on each.
- **Topology correction during the session:** original `bench-wiring.md` §6 had R_off (20 kΩ) feeding VREF into pin 2 alongside the DAC. That makes both contributions inverting → output rails to negative for any DAC value. Reworked to put VREF on **pin 3 (non-inverting)** via a divider — 22 kΩ from VREF to pin 3, 14.7 kΩ from pin 3 to GND. V_pin3 = 4.096·14.7/(22+14.7) ≈ 1.64 V, which gives `Vout = 5.4·V_pin3 − 4.4·VDAC` — a real bipolar swing.

**Static measurements (DAC pin disconnected; jumper into R_in input end):**

| Test | Predicted | Measured | Notes |
|---|---|---|---|
| Pin 3 (1IN+) | +1.64 V | **+1.628 V** | Divider correct |
| Pin 2 (1IN−) | tracks pin 3 (virtual short) | **+1.630 V** | 2 mV input offset, well within TL072 spec |
| Jumper R_in → GND, jack J3 | +8.86 V | **+8.83 V** | + offset (DAC=0 simulated) |
| Jumper R_in → VREF rail, jack J3 | −9.17 V | **−9.25 V** | − swing (DAC=4.096 simulated) |

Symmetric ±9 V swing as expected. Slight asymmetry vs. spec is from R_fb being 44 kΩ (2×22 in series) instead of the spec'd 48.7 kΩ — bench-acceptable; full ±10 V can come back when the right resistor is on hand.

**Dynamic measurement (DAC connected, smoke-test firmware running):**

Smoke-test triangle on DAC ch A, 1 Hz, 50 samples per cycle. Probed jack J3 tip on Rigol DS1Z scope, channel 1 = 5 V/div, time = 200 ms/div.

Channel A bipolar triangle at jack J3

| Scope reading | Spec | Measured |
|---|---|---|
| Period | 1.000 s | **1.004 s** (0.4 % off — Arduino `millis()` quantization, well within tolerance) |
| Frequency | 1.000 Hz | **0.996 Hz** |
| Steps per cycle | 50 | 50 visible in staircase |
| Shape | clean symmetric triangle | clean, no glitches, no dropped samples |
| Amplitude | ±9 V | matches the static numbers above (≈ 18 V pp) |

**What this validates:**
- ✅ SPI bus arbitration (single-CS DAC8552 transaction works in isolation)
- ✅ DAC8552 24-bit frame protocol via Rob Tillaart lib + `outputs::write()` HAL
- ✅ Pot+TL072 VREF stand-in is stable enough for the DAC reference
- ✅ Inverting summing amp with offset divider (corrected topology) produces clean bipolar output
- ✅ End-to-end: XIAO firmware → SPI → DAC → analog stage → Eurorack-spec jack output

**What's still pending in this story:**
- Channel B (DAC OUTB → jack J4) — replicate channel A's wiring
- Bench validation against a real Eurorack VCO V/Oct input (audible test)
- ADC side: wire MCP3208 + smoke-test loopback (jumper J3 → MCP3208 ch 0)
- Input stage (Story 015) for J1 → ADC ch 0
- Calibration: bench-fit `outputs::setCalibration()` constants once channel B is up

**Doc fixes from this session:**
- `bench-wiring.md` §6 needs the topology correction (offset on pin 3, not pin 2) and resistor-value updates from this build.
- `decisions.md` and Story 013 likewise reference the original (broken) topology — both need the same sign correction.

---

## 2026-04-30 — Stories 012 + 013 (channel B + ADC loopback): SPI fully validated

Continuation of yesterday's session. Goal: bring up DAC channel B, then wire the MCP3208 ADC and prove the full SPI bus end-to-end via DAC → analog loopback → ADC.

### Channel B build

Removed channel B's parking wires (pin 5 → GND, pin 6 → pin 7). Added:
- 1× 10 kΩ R_in from DAC8552 pin 3 (VOUTB) to TL072 #2 pin 6
- 1× 47 kΩ R_fb (E12, single resistor — channel A used 2× 22 kΩ in series for 44 kΩ)
- Pin 5 (2IN+) → pin 3 (1IN+) — sharing channel A's offset divider, no second divider needed
- 1 kΩ output series → jack J4
- BAT43 clamp pair to ±12 V

**Static jumper test (DAC pin 3 disconnected):**

| Test | Predicted (R_fb=47k) | Measured |
|---|---|---|
| Jumper R_in → GND, jack J4 | +9.46 V | **+9.28 V** |
| Jumper R_in → VREF rail, jack J4 | −9.79 V | **−9.91 V** |

±9.5 V swing, slightly different from channel A (44 k vs 47 k R_fb difference + E12 tolerance). Bench-acceptable — both channels give clean bipolar output.

### Smoke-test firmware extended for both channels

Updated `src/main_smoketest.cpp`:
- **Channel A:** unchanged 1 Hz triangle, full DAC range
- **Channel B:** **0.5 Hz square** between 1/4·VREF and 3/4·VREF (so jack J4 swings between ≈ +4.5 V and ≈ −4.5 V)
- Two different waveforms = visually obvious independence on a 2-channel scope

Scope (yellow CH1 = J3 triangle, cyan CH2 = J4 square) confirmed:
- Channel A triangle is clean and unchanged when channel B starts driving
- Channel B square has flat plateaus (no rail dips from channel A's continuous writes)
- No CS-line crossover (writes to A only move OUTA; writes to B only move OUTB)
- No power-rail crosstalk (channel A's continuous DAC writes don't perturb channel B's static output)

### MCP3208 ADC bring-up

Wired per `bench-wiring.md` §4 (PDIP-16 on adapter, in DIP-16 socket on the breadboard):

| MCP3208 pin | Net |
|---|---|
| 9 (DGND), 14 (AGND) | GND |
| 16 (VDD) | +5 V (with 100 nF decoupling at the pin) |
| 15 (VREF) | VREF rail (4.096 V — same buffered node as DAC) |
| 10 (/CS) | XIAO D6 |
| 11 (DIN) | tap off existing MOSI line (XIAO D10) |
| 12 (DOUT) | new wire to XIAO D9 (MISO — first time we use it) |
| 13 (CLK) | tap off existing SCK line (XIAO D8) |
| 1 (CH0) | jumper directly to DAC8552 pin 4 (VOUTA) — bypassing the input scaling stage for cleanest possible loopback |

Pre-power voltage checks: VDD = +5 V, VREF = +4.096 V, GND continuity, /CS idle = +3.3 V (XIAO holding it HIGH between transactions). All good.

### Loopback test result

Captured 6 seconds of serial output during a triangle cycle:

```
t_ms    dac_a_v  dac_b_v  adc_v   adc_count
413214  1.7449   3.0720   1.7484  1731
413298  2.4330   3.0720   2.4196  2447
413509  3.3014   3.0720   3.3208  3296
413993  0.0655   3.0720   0.0640  64
414014  0.1147   1.0240   0.1130  114    ← channel B transitions to low half
414120  0.9748   1.0240   0.9752  968
```

**ADC tracks DAC OUTA within ±15 mV across the full 0..4.096 V sweep.** That's about 10–15 LSBs of the MCP3208 at 4.096 V VREF, dominated by analog stage noise and op-amp offset rather than converter accuracy:

- DAC8552 INL spec: ±4 LSB at 16-bit = ±0.25 mV (negligible)
- MCP3208 C-grade INL spec: ±2 LSB at 12-bit = ±2 mV
- VREF stability of pot+TL072 stand-in: a few mV
- Sample-and-hold settling on breadboard wiring: a few mV

Channel B's square wave also shows up cleanly in the `dac_b_v` column (3.0720 → 1.0240 V transitions land at the half-period boundary).

### What this validates

- ✅ MCP3208 24-bit-frame SPI protocol via Rob Tillaart `MCP_ADC` lib + `inputs::readRaw()` HAL
- ✅ Shared SPI bus arbitration with two peripherals (CS_DAC and CS_ADC toggle independently per transaction)
- ✅ Default ~1 MHz SPI clock (under MCP3208's 2 MHz spec at VDD=5V)
- ✅ End-to-end: firmware → SPI → DAC → analog jumper → MCP3208 → SPI → firmware
- ✅ Both DAC channels independent (no crosstalk, no CS interference)

**Story 012 acceptance criteria are met on the bench.** Story 013 channel B done. Only Story 015 (input scaling stage) remains for the platform-rebuild bench session.

### What's still pending

- Audible test: plug J3 into a Eurorack VCO V/Oct input and listen to the 1 Hz pitch sweep
- Story 015: input scaling stage for J1 → MCP3208 ch 0 (TL072 #3, with input 1 active and input 2 deferred)
- Calibration: bench-fit `outputs::setCalibration()` constants per channel for V/Oct accuracy
- Re-run loopback through the input scaling stage once it's built (jack J3 → R_series + clamp + summing amp → MCP3208 ch 0) — that's the full signal-chain round-trip

---

## 2026-04-30 (continued) — Story 015 (input scaling) + full-chain loopback

Picking up the same bench rig from earlier today. Built input 1 of the protected/scaled input stage, then closed the loop by patching J3 → J1 with a Eurorack cable and reading the round-trip in the smoke-test serial output.

### Input stage build (TL072 #3, channel A)

Wired per `bench-wiring.md` §7:
- R_series = 100 kΩ at jack J1
- BAT43 dual clamp at node A (anode→+12V, cathode→−12V; each diode flipped opposite)
- R_in2 from node A to TL072 #3 pin 6 (1IN−)... initially with **R_fb = 4.7 kΩ** per the doc
- Offset divider on pin 3: VREF → 22 kΩ → pin 3 → 14.7 kΩ → GND ≈ 1.66 V
- Channel B parked (pin 5 → GND, pin 6 → pin 7)
- TL072 #3 pin 1 (1OUT) → MCP3208 pin 1 (CH0); replaced the previous direct DAC-OUTA → CH0 loopback jumper

### Math error caught at the bench (again)

First static jumper test on the input-stage op-amp output:

| Test | Predicted (with bad math) | Measured |
|---|---|---|
| Tip floating | +1.66 V | **+1.643 V** ✓ (matches) |
| Tip → GND | +2.04 V | **+1.707 V** ✗ |
| Tip → +5 V | +0.97 V | **+1.515 V** ✗ |
| Tip → −5 V | +3.11 V | **+1.873 V** ✗ |

Slope ≈ −0.036 V/V vs. predicted −0.214 V/V — about **17 % of expected**. Op-amp output too small.

**The bug:** R_series (100 kΩ) and R_in2 (22 kΩ) are **in series** between the jack and the op-amp's virtual-ground inverting input. They look like a single 122 kΩ input resistor, not separate stages. So the actual gain is `R_fb / (R_series + R_in2) = 4.7/122 = 0.039`, not `R_fb/R_in2 = 0.214` as the doc's math claimed.

### Fix: R_fb 4.7 kΩ → 22 kΩ

Swapped R_fb on TL072 #3 from 4.7 kΩ to 22 kΩ. New gain = 22/122 = 0.180 — reasonable target for ±10 V jack range fitting into 4.096 V ADC range with margin.

Re-ran the static jumper test:

| Test | Predicted (gain 0.180, V_pin3 = 1.66) | Measured |
|---|---|---|
| Tip floating | +1.96 V | **+1.949 V** ✓ |
| Tip → GND | +1.96 V | **+1.947 V** ✓ |
| Tip → +5 V | +1.06 V | **+1.053 V** ✓ |
| Tip → −5 V | +2.86 V | **+2.860 V** ✓ |

All four readings within 10 mV of prediction. Slope = (2.860 − 1.053)/(−5 − +5) = **−0.181 V/V** vs predicted −0.180 — within 1 % across ±5 V test range.

### Round-trip loopback test

With input stage validated, patched a Eurorack cable from J3 → J1 to close the full signal chain:

```
firmware → SPI → DAC8552 → output stage (TL072 #2 ch A) → J3 → cable → J1 →
                input stage (TL072 #3 ch A) → MCP3208 → SPI → firmware
```

False start: first attempt with patch cable in J1 killed the J3 sawtooth on the scope. Cause: a leftover GND jumper from the static validation was still pinning J1, so plugging J3 in back-drove the GND jumper. Pulled the jumper, re-tried — sawtooth returns.

Smoke-test serial captured during a triangle cycle:

```
t_ms    dac_a_v  dac_b_v  adc_v   adc_count
134506  4.0468   1.0240   3.5529  3551
134675  2.6706   1.0240   2.4636  2479
134759  1.9825   1.0240   1.9275  1934
134991  0.0819   1.0240   0.4141  411
135244  1.9907   3.0720   1.9365  1950
```

**Predicted** transfer: `adc_v ≈ 0.378 + 0.792 × dac_a_v` (composing output stage's bipolar swing with the input stage's attenuated read-back). Measured slope = **0.796** vs predicted 0.792 — within 0.5 %. Per-point error ≈ 20–30 mV across the sweep.

### Where the 30 mV residual comes from

Five op-amp channels and ~10 resistors in the round trip, all carrying real-world tolerances:

- VREF dial-in: ~5 mV vs 4.096 V nominal
- TL072 input offset: spec 3 mV typ × 4 cascaded channels
- E12 resistor tolerance: ±5 % across 6+ resistors

Most of this stays put once the REF3040 lands — the residual is op-amp + resistor dominated, not VREF dominated. But it'll become **stable across temperature** instead of drifting with bench warmth.

### What this validates (cumulative across both 2026-04-30 sessions)

- ✅ **Story 012** — SPI bus + DAC + ADC sharing the bus
- ✅ **Story 013** — bipolar output stage on both DAC channels
- ✅ **Story 015** — input protection + scaling stage on input 1

**The entire post-pivot platform is bench-validated end-to-end.** Next bench session can focus on calibration (bench-fit `outputs::setCalibration()` + `inputs::setCalibration()` constants), then plug J3 into a real Eurorack VCO for the audible V/Oct test.

### Doc fixes from this session

- `bench-wiring.md` §7 has the same math bug as §6 had pre-2026-04-29 — predicted op-amp output values used `gain = R_fb/R_in2`, ignoring R_series in series. Fix by stating the correct effective input resistance and updating the predicted-values table for R_fb = 22 kΩ.

---

## 2026-05-02 — Bench rebuild after voltage misconfiguration; tempo pot moves to MCP3208

**Setup:** XIAO RP2350 #1 fried by a power-supply misconfiguration that pushed wrong voltages onto the breadboard, taking out the original MCP3208 and at least one TL072 along with it. Replaced the XIAO and brought up the analog chain piece by piece using the smoke-test firmware (1 Hz triangle on DAC OUTA, 0.5 Hz square on DAC OUTB, MCP3208 ch 0 read every loop).

### Bring-up sequence

1. **New XIAO + smoke-test flash.** Confirmed CDC enumeration on `/dev/cu.usbmodem20401`; serial stream showed `dac_a_v` triangle and `dac_b_v` square commanding correct firmware-side values. Board alive. ✓
2. **DAC8552 + VREF + output op-amps survived.** Probed DAC8552 pin 4 (VOUTA) and pin 3 (VOUTB) — both tracked the firmware's commanded values cleanly. VREF rail steady at 4.096 V. TL072 #1 (VREF buffer) and TL072 #2 (output stages) intact. Jacks J3 and J4 produce the expected ±9 V swings.
3. **First MCP3208 replacement was DOA.** Soldered a fresh chip onto a spare DIP-16 breakout. Smoke-test reads stayed at `adc_v = 0.0000, adc_count = 0` regardless of CH0 jumper position (GND, VREF rail, DAC pin 4 loopback). Disambiguating test with a known-bad chip (the previously-fried original) read identically — proving the failure mode was repeatable and chip-localized.
4. **Second MCP3208 replacement worked.** Same wiring as #3 above; immediately read clean GND→0, VREF→4095, and locked DAC OUTA loopback within ~5 mV across the full 0..4.096 V sweep. Diagnostic of #3's failure inconclusive — possibly a soldering defect or a marginal chip; tossed.
5. **Input scaling stage (§7) rebuilt.** Replaced TL072 #3 (input op-amp). Initial bring-up readings at pin 3 came in wrong:
   - First reading: 1.022 V (expected 1.66 V). Math suggested ~7 kΩ of parallel load on pin 3.
   - After divider rewiring: 0.528 V — even worse, suggesting the op-amp itself was clamping (likely fried by the same event that took the ADC).
   - Replaced TL072 #3 with a fresh chip → pin 3 = **1.643 V** (1 % off the 1.66 V design target, all from E96/E12 resistor tolerance).

### Input-stage characterization (TL072 #3 channel A, J1 → MCP3208 ch 0)

Four-point sweep at jack J1 tip; metered TL072 #3 pin 1 (1OUT):

| Jack input | Predicted pin 1 | Measured pin 1 |
|---|---|---|
| floating | 1.66 V (no current → no offset gain) | **1.650 V** ✓ |
| GND | 1.96 V | **1.948 V** ✓ |
| +5 V (stiff supply) | 1.06 V | **1.056 V** ✓ |
| −5 V (stiff supply, *not* 100 kΩ pot — that sagged due to source impedance) | 2.86 V | **2.851 V** ✓ |

Three-point linear fit (excluding floating, which is the no-current degenerate case): `V_pin1 = 1.952 − 0.1795 · V_jack`. Slope agrees with design (−0.180) to better than 1 %. Inverted for firmware:

```
CAL_IN_0_GAIN   = -5.57  (existing constant in main.cpp: -5.56)
CAL_IN_0_OFFSET = +10.88 (existing constant: +10.89)
```

**New silicon matches old silicon to <0.2 %.** No firmware change required — existing calibration constants stand.

### Full-loop validation (J3 → patch cable → J1, end-to-end)

Smoke-test firmware running, J3 tip patched into J1 tip, MCP3208 ch 0 wired to TL072 #3 pin 1. Sample row at the negative peak of the DAC triangle:

```
dac_a_v = 4.080  →  J3 ≈ -9.0 V (output stage gain ≈ -4.4)
                 →  J1 = -9.0 V (patch cable)
                 →  pin 1 ≈ +3.57 V (input stage gain ≈ -0.18)
                 →  adc_v = 3.597 V  ✓ (predicted 3.566 V; 30 mV agreement)
```

ADC tracks DAC across the full ±9 V swing within ~30 mV per point. Composite slope on the DAC↔ADC transfer matches predicted within 0.5 %.

### Tempo pot moved to MCP3208 CH1

Decided during this session to relocate the tempo pot off XIAO D0 (native ADC) onto MCP3208 CH1 (precision ADC through REF3040). Rationale:

- All analog inputs now share one reference (REF3040, ±0.2 %, 75 ppm/°C) — uniform calibration story, no mixing of XIAO native ADC and external ADC.
- **Frees D0** for J1 clock/gate digital edge detection (per `decisions.md` §23, J1 is dual-purpose: CV in *or* clock-trigger). Edge detection wants a true digital pin.
- Cost: one extra SPI read per loop (microseconds) and one breadboard wire change (pot CW from +3.3 V → VREF rail).

Updated:
- `bench-wiring.md` §3 (D0 reassigned), §8 (pot wiring), §9 (J2 moves to ch 2 since ch 1 is now tempo)
- `decisions.md` §26 (pin budget table)
- `firmware/arp/src/main.cpp`: removed `PIN_TEMPO`; added `ADC_CH_TEMPO = 1`; replaced 3× `analogRead(PIN_TEMPO)` with `inputs::readRaw(ADC_CH_TEMPO)`. Build still 2.2 % RAM / 4.6 % flash; all 66 host tests pass.

### Doc fixes from this session

- `bench-wiring.md` §7 step 3 used to say "input floating ≈ +1.96 V." That's wrong — with the jack truly floating, no current flows through R_series + R_in2, no offset gain develops, and pin 1 sits at V_pin3 ≈ +1.66 V instead. The +1.96 V reading only appears when the jack is **actively grounded**. Caught when the freshly-replaced TL072 #3 read 1.65 V on pin 1 with the jack floating — the doc said this should be 1.96 V, but the chip was actually behaving correctly. Doc updated.

### Lessons captured

- **Voltage misconfiguration on the bench will cascade-kill ICs.** Always meter the rails *before* energizing the analog chain after any wiring change.
- **Pot voltage sources have non-trivial output impedance.** The 100 kΩ pot used as a stand-in for −5 V sagged badly (~−4 V at the loaded node) because it was sourcing into 100 kΩ R_series. Fix is either a buffered source (op-amp follower) or a stiff bench supply. This is exactly why the tempo pot uses a 10 kΩ part — low source impedance, can drive an ADC sample-and-hold cleanly.
- **MISO read of "0" is ambiguous on SPI** — it could mean "alive ADC reading 0 V" or "dead chip not driving DOUT." Pull-up trick on MISO disambiguates: live chip pulls low through driven 0; dead chip lets the pull-up float MISO high → reads 4095. Worth remembering for next time.

### Tempo pot validation (continued, same session)

After the tempo-pot relocation commit, re-flashed the smoke test (now extended to also stream `tempo_v` / `tempo_count` from MCP3208 CH1 alongside the existing CH0 columns) and swept the pot:

| Position | tempo_count | tempo_v |
|---|---|---|
| Fully CCW | **0** | **0.0000 V** |
| Mid-sweep | smooth, monotonic | linear with rotation |
| Fully CW | **4090** | **4.0950 V** (5 LSB shy of full-scale 4095) |

Full 12-bit range, no jitter, no dropouts. Pot is ready for the production firmware to drive tempo selection without any further bench work.

### Encoder bring-up (continued, same session)

After the tempo-pot validation, wired the PEC11R encoder per `bench-wiring.md` §8: A→D1, B→D2, common→GND, click→D7+GND. Internal pull-ups handle idle state.

**First test:** no count change at all over a 6 s rotation window. Cause: encoder common pin not wired to GND (the middle pin on the 3-pin side). Without GND on common, A and B sit at indeterminate voltages and the decoder sees no transitions. Re-wired.

**Second test:** count moved smoothly but **CW reads as a negative delta** (got −7 over a CW rotation that should read +7). Tried physically swapping the wires twice; CW remained negative either way. **Fix in firmware:** swap `PIN_ENC_A` and `PIN_ENC_B` in both `src/main.cpp` and `src/main_smoketest.cpp` (A→D2, B→D1). Rebuilt + re-flashed. CW now reads +13 as expected.

**Final validation matrix:**

| Test | Result |
|---|---|
| Rotate CW ~13 detents | `enc_count` delta = **+13** ✓ |
| Rotate CCW ~7 detents | `enc_count` delta = **−7** ✓ |
| Three quick taps | **3 click pulses, 0 long pulses** (debouncer verified honest — one tap = one pulse) ✓ |
| One long press (~1 s) | **0 click pulses, 1 long pulse** (long-press correctly suppresses the short-click for the same gesture) ✓ |

**Lesson for the bench-wiring doc:** §8 should explicitly call out "encoder common pin must go to GND" and the A/B swap (since this encoder reads inverted with the spec'd assignment). Both updates pending the next doc-fix pass.

### OLED bring-up + encoder switched to interrupts (continued, same session)

Wired the 0.49" 64×32 SSD1306 OLED per `bench-wiring.md` §8: VCC→3V3, GND→GND, SDA→D4, SCL→D5. On-board pull-ups handle the I²C bus.

Extended the smoke-test firmware to probe for the display at boot (`OledUI::begin()` returns false if no ACK at 0x3C) and refresh "ENC = N" at 10 Hz reflecting the live encoder count. **Result:** OLED detected immediately, splash + parameter display both render correctly.

**However**, the OLED revealed a polling-rate limitation: rotating the encoder fast through ~20 detents only registered ~7 in the count display. The mathertel/RotaryEncoder library was being called from `EncoderInput::poll()` once per main-loop iteration (~50 Hz), but the loop was now doing more work per iteration (DAC writes + ADC reads + tempo read + encoder poll + serial print + 5 ms OLED I²C blast every 100 ms). Combined loop time pushed past the encoder's per-detent transition window during fast rotation.

**Fix:** switched `EncoderInput` to interrupt-driven decoding. Both A and B pins now have CHANGE ISRs that call `RotaryEncoder::tick()` the moment any transition occurs — the loop's per-iteration work no longer matters. `poll()` still calls `tick()` as belt-and-suspenders.

**Validation after the switch:** rotated the encoder fast through ~20 detents; serial captured **+21 with 22 unique values seen** (every count appears in the trace, no skipped detents). OLED tracks the count smoothly. Fast rotations now register correctly.

This change benefits the production firmware too — same `EncoderInput` library, so future arp UI menus stay responsive even when the OLED is being drawn.

**Bench platform validation status (cumulative across all 2026-04-29 → 2026-05-02 sessions):**

- ✅ XIAO RP2350 + USB CDC + smoke-test firmware
- ✅ SPI bus arbitration (DAC8552 + MCP3208 sharing SCK/MOSI/MISO + per-chip CS)
- ✅ DAC8552 + output op-amps + jacks J3/J4 (±9 V swing, both channels)
- ✅ MCP3208 + input op-amp + jack J1 (±9 V → 0..4.096 V → ADC counts within 0.5 % of design)
- ✅ Tempo pot on MCP3208 CH1 (full 12-bit range, smooth)
- ✅ Encoder + click + long-press, interrupt-driven (no missed detents at any speed)
- ✅ OLED on I²C at 0x3C (live updates at 10 Hz)
- ✅ VREF rail (REF3040 stand-in via TL072 buffer at 4.096 V)
- ⏸ Channel B input (J2) scaling stage — wires planned, not built (out of scope until Story 010 external clock or a second CV use case lands)

**The bench platform is complete enough to host the production firmware end-to-end.** Next bench session: flash production firmware and do the audible-VCO test (J3 → external Eurorack VCO, listen).

---

## 2026-05-04 — Bench rebuild on schematic-aligned layout: full signal chain revalidated end-to-end on both channels

**Context:** the schematic in `hardware/gio-opamp/` had drifted ahead of the breadboard wiring across two areas:
1. **MCP3208 channel layout** (decisions.md §26): CH0 = pot, CH1 = J1 input, CH2 = J2 input. The breadboard had been carrying the older "pot on CH1" assignment.
2. **Encoder A/B**: schematic uses A→D1, B→D2 (natural assignment); firmware had been swapped to A→D2, B→D1 as a workaround for the bench encoder reading CW as negative. On 2026-05-04 the breadboard wires were physically swapped to align with the schematic, and the firmware was reverted to the natural assignment.

This bench session rebuilds the input scaling stage on the breadboard to match the schematic exactly, then revalidates the full signal chain.

### Findings during the rebuild

**Wiring error caught at the bench:** the input op-amp ch A had its jack-side input chain (R_series 100 k → BAT54S clamps → R_in2 22 k) wired to **pin 1 (output)** instead of **pin 2 (inverting input)**. With J1 tip grounded, pin 1 read **1.727 V** instead of the expected ~1.96 V. Working backward:

```
V_pin1 / V_pin3 - 1 = 1.727 / 1.66 - 1 ≈ 0.04 effective gain
Design gain          = R_fb / (R_series + R_in2) = 22 / 122 = 0.180
```

A 4× gain error pointed at either R_fb being wrong (4.7 k instead of 22 k — the same math bug we caught in the §7 doc on 2026-04-30) or the input chain not actually reaching pin 2. After confirming all resistor values were correct, traced the wires: R_in2's "op-amp" end was on pin 1 (the output) — meaning pin 2 was floating except via R_fb, the op-amp drove pin 1 to follow pin 3 via virtual short, and the external signal at pin 1 was just being absorbed by the op-amp's low-impedance output. Moving the wire to pin 2 fixed it: pin 1 read **2.039 V** with J1 grounded (predicted 2.030 V given the actual pin 3 bias of 1.720 V) — a **9 mV error**, within E12 resistor tolerance and TL072 input offset.

### Validation matrix (loopback via direct tip-to-tip jumpers, since the breadboard jacks won't hold patch cables)

| Test | Expected | Measured | Pass? |
|---|---|---|---|
| Pot at CW endpoint | `pot_v` ≈ 4.096 V | 4.094 V | ✓ |
| Input A (J1) tip floating | `j1_v` ≈ 1.66 V | 1.65 V | ✓ |
| Input B (J2) tip floating | `j2_v` ≈ 1.66 V | 1.63 V | ✓ |
| **J5 → J1** (Output A triangle into Input A) | `j1_v` swings 0.34 → 3.57 V at 1 Hz | 0.36 → 3.60 V | ✓ (~30 mV error) |
| **J5 → J2** (Output A triangle into Input B) | `j2_v` swings 0.34 → 3.57 V at 1 Hz | 0.35 → 3.58 V | ✓ (~10 mV error) |

End-to-end transfer (DAC value → jack-side ADC reading) matches the bench-validated math from 2026-04-30 across both input channels.

### Naming convention update

Adopted the KiCad schematic's jack-numbering convention for all future docs and conversation:

| Jack | Role |
|---|---|
| **J1** | Input A (CV in, ±10 V Eurorack, scaled to 0..VREF for ADC ch 1) |
| **J2** | Input B (same as J1) |
| **J5** | Output A (DAC ch A → ±9 V at jack via inverting op-amp) |
| **J6** | Output B (DAC ch B → ±9 V at jack) |

(The schematic's auto-annotation skipped J3/J4 — those refs may have been used during early KiCad iterations on a different sheet and weren't reused. Going forward we just use what the schematic says.)

### Bench platform validation status

The breadboard now matches the KiCad schematic 1:1, including all the design refinements we've layered in over the past week:

- ✅ XIAO RP2350 + USB CDC + smoke-test firmware
- ✅ SPI bus arbitration (DAC8552 + MCP3208 sharing SCK/MOSI/MISO + per-chip CS)
- ✅ DAC8552 + output op-amp + jacks J5/J6 (±9 V swing, both channels)
- ✅ MCP3208 + input op-amp + jacks J1/J2 (±9 V → 0..VREF → ADC counts within 30 mV across full swing, both channels)
- ✅ Tempo pot on MCP3208 CH0 (full 12-bit range, smooth)
- ✅ Encoder + click + long-press, interrupt-driven (no missed detents at any speed; A→D1, B→D2 natural assignment)
- ✅ OLED on I²C at 0x3C (live updates at 10 Hz)
- ✅ VREF rail (REF3040 stand-in via TL072 buffer at 4.096 V)

**Implication for the PCB:** the schematic is now a high-confidence target. Whenever PCB layout starts, every component's connectivity has been physically verified at the bench — no more "hope it works on the board too."

### Lessons added to the troubleshooting playbook

- **"4× gain error → check R_fb value OR look for input chain on the wrong pin."** Both have the same magnitude impact and same observable symptom. Verify R values first (faster) then trace wires.
- **Inverting-amp wiring error mode:** if the input chain lands on pin 1 (output) instead of pin 2 (inverting input), the op-amp acts as a unity-gain follower of pin 3's bias point regardless of the input. Output sits near bias, the external signal gets absorbed by the op-amp's low-impedance output stage, and you'll see a tiny "gain" that's actually just the op-amp-vs-input-source impedance ratio.

### REF3040 swap — VREF stand-in retired (2026-05-04 continued)

Replaced the pot+TL072 VREF stand-in with a **REF3040AIDBZR** (TI series voltage reference, ±0.2 % initial, 75 ppm/°C). Wiring per `bench-wiring.md` §5: pin 1 (VIN) → +5 V, pin 2 (GND) → GND, pin 3 (VOUT) → VREF rail; 100 nF on VIN, 1 µF on VOUT (required for stability per datasheet).

The TL072 #1 (VREF buffer) was also pulled — REF3040's 25 mA output drives the ~1 mA total load (DAC + ADC VREF inputs + pot + 4× bias dividers) directly without any buffering. This matches what the production PCB will do.

**Stability comparison:**

| | Pot+TL072 stand-in | REF3040 |
|---|---|---|
| `pot_v` reading at CW endpoint | 4.040 – 4.096 V | 4.094 – 4.096 V |
| Range across 4 s window | **56 mV** | **2 mV** |
| Improvement | — | **28×** more stable |

The 2 mV residual is essentially MCP3208 LSB quantization (1 mV per count) plus a touch of analog noise. VREF is locked to within 1–2 LSB of the ADC's resolution.

**Implications:**
- Calibration constants in `main.cpp` (`CAL_OUT_*`, `CAL_IN_*`) were fit against the pot+TL072 setting — they may shift slightly under REF3040, but the system is ratiometric (DAC + ADC share VREF) so the impact is well below 0.1 %. Worth re-fitting next time we calibrate, but no urgent action.
- Bench rig is now using the production-grade VREF source. Nothing about this needs to change when the PCB lands.

---

## 2026-05-21 — Manufactured board rev 1: full electrical bring-up

**Context:** the rev 1 PCB returned from JLCPCB, was hand-populated with through-hole jacks / pot / encoder / OLED / XIAO sockets, and powered up for the first time. This entry captures the full bring-up validation pass: every subsystem exercised against the design intent, with one PCB footprint bug found, one firmware bodge applied, and a productive false-alarm chase through the input op-amp transfer function.

### Bring-up sequence + per-subsystem validation

**Power-up:** confirmed XIAO comes up on Eurorack +5 V alone (AMS1117-5.0 → XIAO LDO → 3.3 V chain works). USB CDC enumerates as `/dev/cu.usbmodem*`.

**Flash:** smoke-test firmware uploaded clean — `pio run -d firmware/arp -e seeed-xiao-rp2350-smoketest --target upload`. 75 252 bytes flash, 11 472 bytes RAM (~3.6 % / 2.2 %).

**Baseline capture (undisturbed, J1/J2 unpatched):**

| Signal | Reading | Verdict |
|---|---|---|
| `dac_a_v` 0.016 → 4.080 V | full DAC range | ✓ DAC ch A alive |
| `dac_b_v` 1.024 ↔ 3.072 V | square endpoints exact | ✓ DAC ch B alive |
| `pot_v` stable ±2 mV | matches bench REF3040 stability exactly | ✓ MCP3208 CH0 + REF3040 |
| `j1_v` floating ≈ 1.665 V | matches bench bias point | ✓ Input A op-amp |
| `j2_v` floating ≈ 1.662 V | same | ✓ Input B op-amp |
| Encoder/click idle | all zeros | ✓ no spurious ISRs |

SPI bus, both ICs, VREF chain, and both input op-amp stages cleared on the first 6 s capture. No `ERROR:` lines from `outputs::begin()` or `inputs::begin()`.

### OLED footprint bug + rework (rev 1 → rev 2 to-do)

**Symptom:** OLED dark on first power-up; no display, no I²C ACK at 0x3C (firmware-side `OLED: NOT detected at 0x3C` would have printed if we'd caught the boot banner — we didn't, but the visible output confirmed it).

**Diagnosis:** visual comparison of the 4-pin OLED header on the gio PCB vs the silkscreen on the actual 0.49" SSD1306 module showed the pin order was **reversed**. The PCB had been laid out for one common 0.49" module pinout (e.g. `VCC GND SCL SDA`) and the module we used had the opposite (`SDA SCL GND VCC`). With VCC and GND swapped, the OLED was reverse-biased through its ESD diodes on first power-on — almost certainly cooked the IC.

**Rework:** physically flipped the OLED 180° to swap the pin mapping. With the flip, software needs to compensate by adding 180° of framebuffer rotation: `OLED_ROTATION` in `oled_ui.h` changed from `1` (90° CW, design intent for the portrait mounting) to `2` (180° — adds 90° CW on top of the original portrait rotation to match the physically inverted orientation).

After the bodge: OLED detected, splash + "ENC = N" displays cleanly with text reading in the correct portrait orientation.

**Rev 2 fix:** correct the OLED footprint in KiCad to match the actual module pinout. Once rev 2 ships, `OLED_ROTATION` reverts to `1`.

### 2 × 2 patch matrix — all four op-amp half-stages validated

Loopback tests with a 3.5 mm cable between each Output and each Input. DAC channel A drives Output A as a 1 Hz triangle full-swing; DAC channel B drives Output B as a 0.5 Hz square between 1/4·VREF and 3/4·VREF.

| | **Output A (triangle, ±9 V at jack)** | **Output B (square, ±4.5 V at jack)** |
|---|---|---|
| **Input A** (`j1_v`) | range 3.40 V, center 1.99 V | range 1.73 V, center 1.99 V |
| **Input B** (`j2_v`) | range 3.39 V, center 1.98 V | (not run — redundant with the other three) |

All three captures agree on the same center (~1.99 V) and on the input-stage gain (slope ≈ 0.18 V/V at the ADC per V at the jack). The 5 % bigger swing than bench (3.40 V vs 3.24 V design) is within E12 resistor tolerance.

**Back-computed Output A swing**: j1_v 0.29 → 3.68 V → V_J5 = +9.28 → −9.56 V — centered at −0.14 V, swing ±9.4 V — **design ±9 V matches within tolerance**.

### Tempo pot — full 12-bit range, no glitches

10 s end-to-end sweep with monotonicity + decile coverage:

| | Bench (2026-04-29) | Manufactured rev 1 |
|---|---|---|
| CCW endpoint | 0 / 0.0000 V | **0 / 0.0000 V** ✓ |
| CW endpoint | 4090 / 4.0950 V | **4095 / 4.0960 V** ✓ (5 LSB better than bench) |
| Glitches > 200 LSB | none | **none** ✓ |
| Decile coverage | smooth | **smooth, all deciles** ✓ |

437 samples over 10 s = 44 Hz read rate — plenty fast for UI use.

### Encoder — rotation + click + long-press all clean

| Test | Result | Pass? |
|---|---|---|
| CW rotation ~10 detents | enc_count delta **+10**, no skipped detents | ✓ |
| CCW rotation ~10 detents | enc_count delta **−10**, returns to start | ✓ |
| 3 short taps | **3 click pulses** at 2.95 / 6.16 / 9.42 s (well-separated, clean debouncing) | ✓ |
| 1 long press (~1 s) | **1 long pulse, 0 click pulses** (long correctly suppresses the same-gesture short-click) | ✓ |

Matches the 2026-05-02 bench validation behavior exactly. The interrupt-driven `EncoderInput` lib doesn't drop detents even with OLED I²C bursts in the same loop.

### Diagnostic chase: the "Output DC offset" that wasn't

Mid-validation, the data appeared to show a **~−1.8 V DC offset on both Output A and Output B**: when the triangle / square was patched into an input, the observed `j1_v` (or `j2_v`) center sat at ~1.99 V instead of the 1.66 V bias point measured floating. Walking back through the input gain (−0.18 V/V) and the bias (1.66 V), this looked like J5 and J6 were both shifted by −1.83 V at the jack.

Spent considerable analysis time hunting the likely bias-divider culprit (R17/R18/R19/R20), even predicting which resistor value substitution would match (`R19/R20 loaded as 10 k instead of 15 k` was the lead hypothesis since 10 k parts are right next door on the BOM). Then multimeter measurements at the four op-amp non-inverting input pins came back **all spot-on at 1.66 V**:

| Pin | Reading | Design |
|---|---|---|
| vref (U7 OUT) | 4.097 V | 4.096 V ✓ |
| U5A pin 3 (Out A non-inv) | 1.664 V | 1.66 V ✓ |
| U5B pin 5 (Out B non-inv) | 1.656 V | 1.66 V ✓ |
| U1A pin 3 (In A non-inv) | 1.662 V | 1.66 V ✓ |

The divider was fine. The offset was a **math error in the live analysis**: the input op-amp transfer function is not `V_adc = V_bias − 0.18·V_jack` as I'd been treating it; the R9 (100 k) + R10 (22 k) front end means it's:

$$V_{adc} = 1.180 \cdot V_{bias} - 0.180 \cdot V_{jack}$$

The bias contribution gets a **1.18× multiplier** because V_bias propagates from the non-inverting input through the virtual short, up through R10 + R1 into the output. So when V_jack is at 0 V (DAC mid, design center), V_adc isn't V_bias = 1.66 V — it's 1.18×1.66 = **1.96 V**. That's exactly the "center shift from 1.66 to 1.99 V" the data was showing.

Sanity check with the formula:
- Floating J1 (V_jack = V_bias via R9): V_adc = 1.18·1.66 − 0.18·1.66 = 1.66 V ✓ matches measurement
- V_jack = +9 V: V_adc = 1.96 − 1.62 = 0.34 V ✓ matches bench-log 2026-05-04 entry exactly
- V_jack = −9 V: V_adc = 1.96 + 1.62 = 3.58 V ✓ matches bench-log

And re-deriving V_J5 swing from the measured j1_v range gives ±9.4 V centered at 0 V — matches design. **No offset, no PCB fault, no rework.**

### Lesson for the troubleshooting playbook

- **"Output DC offset" symptoms via an input-stage measurement are deceptive.** The input op-amp's bias multiplier (1 + R_fb/R_in_eq for the path from V_bias to V_out) means the centerline of an input observation depends on the divider AND the bias — not just the input signal. Before chasing an offset, sanity-check by **measuring the input op-amp output directly with a multimeter while the input is floating, then again while driven by a known DC voltage**. If both readings match the formula `V_adc = (1 + R_fb/R_in_eq) · V_bias − (R_fb/R_in_eq) · V_jack`, the chain is fine.
- **The bench-log already had this pattern documented** (the 2026-05-04 entry shows `j1_v` driven center at 1.98 V, floating at 1.65 V — same +330 mV shift). I missed the pattern in real-time. Worth re-reading bench-log entries during diagnostic sessions before chasing new hypotheses.

### Final validation status — manufactured board, rev 1

| Subsystem | Status | Notes |
|---|---|---|
| XIAO RP2350 + USB CDC | ✅ | enumerates on USB and on Eurorack +5 V |
| AMS1117-5.0 → +3.3 V LDO chain | ✅ | XIAO comes up on Eurorack alone |
| REF3040 VREF | ✅ | 4.097 V measured, 2 mV stability |
| SPI bus + DAC8552 + MCP3208 | ✅ | both ICs alive, full range |
| Output A op-amp (U5A → J5) | ✅ | swings ±9.4 V centered 0 V |
| Output B op-amp (U5B → J6) | ✅ | matches Output A |
| Input A op-amp (U1A → ADC CH1) | ✅ | bias 1.66 V, gain 0.18 V/V, no DC error |
| Input B op-amp (U1B → ADC CH2) | ✅ | matches Input A |
| Tempo pot (ADC CH0) | ✅ | full 12-bit, smooth |
| OLED (post-rework) | ⚠️ | works with `OLED_ROTATION=2` firmware bodge; **footprint needs rev 2 fix** |
| Encoder rotation | ✅ | both directions, no missed detents |
| Encoder click / long-press | ✅ | debouncing clean, long suppresses short |
| ±12 V Eurorack rails | ✅ (inferred — outputs swing ±9.4 V) | not directly metered |

**Rev 2 to-do list (PCB):**
- Fix OLED 4-pin header footprint to match the production module pinout (so the OLED can sit "right way up" without the 180° physical flip).
- Revert `OLED_ROTATION` to `1` in `oled_ui.h` when rev 2 firmware ships.
- Faceplate to be designed (separate work).
- (Any other tweaks the user is collecting for rev 2 — to be added.)

---

## 2026-05-23 — Toolchain regression chase + Wire pin remap; production arp firmware lives

**TL;DR: a brutal day.** Took most of a session and at least one destroyed PCB to isolate two interlocking *silent-failure* issues in the build environment that had nothing to do with the gio hardware design itself:

1. **arduino-pico framework 4.4.0 began producing UF2s that don't boot on this XIAO RP2350.** Builds made earlier in the project's history (and already flashed on boards) still ran fine, but *new* builds — same source code, same pinned framework tag — produced UF2s that crashed before any USB CDC output. We never identified which transitive dependency changed (PlatformIO, picotool, an arduino-pico submodule, …); the practical fix was upgrading to **arduino-pico 5.6.0**.
2. **arduino-pico 5.6.0 changed the default Wire (Wire0) pin mapping on the seeed_xiao_rp2350 variant.** Where 4.4.0 had `PIN_WIRE0_SDA = GP6 / GP7 (= D4/D5)` — matching the gio board's OLED wiring — 5.6.0 moved Wire0 to `GP16/GP17` and put GP6/GP7 on **Wire1**. The OLED stopped responding even though `ui.begin()` returned true (Adafruit_SSD1306 happily writes to the wrong I²C peripheral and never notices nothing's on the bus).

Both failures presented as "USB CDC works, OLED dark, zero serial output, can't tell what's hung where." Combined, they consumed hours.

### What we paid for these lessons

- **1 XIAO desoldered** from board #1 (used as a "is it the XIAO or the PCB?" diagnostic when we still thought we had a hardware fault).
- **Board #1's MCP3208 had been killed earlier** by overvoltage during the bench fail (see the 2026-05-21 follow-up notes); replacement reflow then introduced what felt like cascading PCB damage, but in hindsight may have been the build regression all along — we'll never know for sure because we were testing with broken UF2s during the post-rework diagnostic.
- **Hours** of "is it the firmware? the chip? the rails? the OLED? the rework?" — each new hypothesis was indistinguishable from the right one because every test got the same answer: silence.

### Timeline (compressed)

1. Morning: board #2 plugged in, factory smoke test (pre-existing 4.4.0 build) streams cleanly. All subsystems healthy per the 2026-05-21 pattern.
2. Flashed production arp firmware (built today, also 4.4.0) → USB CDC came up, **0 lines** of serial output, OLED dark.
3. Suspected production firmware bug. Re-flashed smoke test (built today, 4.4.0) → same silence.
4. Suspected XIAO damage. Wiped `.pio/` for a fully fresh build, re-flashed → same silence.
5. Rebooted the Mac (clear any host-side USB stack state) → same silence.
6. Pulled the XIAO from board #1, plugged it in standalone, flashed MicroPython for sanity → MicroPython runs fine, REPL prompt + version banner visible. So **the chip is healthy.**
7. Re-flashed our 4.4.0 smoke test onto the standalone XIAO → silent again.
8. Pulled a fresh XIAO out of the parts bin, flashed our smoke test → still silent. So **it's not the chip.**
9. Inspected the failing UF2 with `picotool info`:
    - Family ID `0xE48BFF59` (`RP2350_ARM_S`) — the expected default for stock RP2350 ARM code. ✓
    - `Program Information: none` — suspicious. A healthy arduino-pico UF2 for RP2350 should embed program metadata that picotool can read back.
10. Upgraded `framework-arduinopico` pin from `#4.4.0` → `#5.6.0`, rebuilt minimal sketch (just `Serial.begin` + `Serial.println` in loop) → **booted**, USB CDC streamed "alive t=N" messages. We had a working build path again.
11. Built and flashed smoke test with 5.6.0 → boots and streams data, but **OLED dark.** Even on a board where the OLED is wired correctly and was provably working with a prior-session 4.4.0 build.
12. Production firmware (5.6.0) also boots — `ui.begin()` reports `ready=true` — but OLED still dark. Loop heartbeat prints proved setup() completed and loop() was running; renderMenu() was being called. Yet the OLED never displayed anything.
13. Read the 5.6.0 variant header `~/.platformio/packages/framework-arduinopico/variants/seeed_xiao_rp2350/pins_arduino.h`:
    - `PIN_WIRE0_SDA = (16u)` — Wire0 is now on GP16, not GP6.
    - `PIN_WIRE1_SDA = (6u)` — GP6/GP7 (D4/D5, where our OLED is wired) is now on Wire1.
14. Changed `Adafruit_SSD1306 display_{OLED_WIDTH, OLED_HEIGHT, &Wire, -1}` → `&Wire1` in `oled_ui.h`. Wire1's default pins on the XIAO RP2350 variant are GP6/GP7 (matching our wiring), so no `setSDA`/`setSCL` remap is needed.
15. Smoke test flashed → OLED lights up showing "ENC 0". 🎉
16. Production firmware flashed → OLED shows the menu, encoder rotation updates it cleanly. 🎉🎉

### Lessons captured (high-confidence, hard-earned)

- **Never trust "no output" as a diagnostic.** When USB CDC enumerates but no serial output appears, the firmware is almost certainly hanging in `setup()` *before* any `Serial.println` had a chance to flush. The cure is to write code that makes hangs *visible*: put `Serial.begin()` as the very first line of `setup()`, and stamp a `Serial.println("BOOT N: <step>")` between *every* peripheral `begin()` call. The diagnostic prints we added today (`BOOT 0` … `BOOT 14` plus a `LOOP heartbeat` once per second) are arguably worth keeping permanently — they turn silent failures into "we got to BOOT 7 and stopped" tractable bugs.
- **Pin your dependencies all the way down.** `framework-arduinopico @ ...#4.4.0` looked like a pin, but the surrounding ecosystem (platform-raspberrypi tracking `main`, picotool versions, transitive deps) is unpinned and *will* drift under you. The platform line in `platformio.ini` is `https://github.com/maxgerhardt/platform-raspberrypi.git` (no `#commit`), which means every build can grab a different platform package and a different picotool. Followup: pin `platform = …#<commit>` and `platform_packages` for picotool/openocd to specific known-good versions.
- **arduino-pico variant pin mappings can change between minor versions without warning.** Specifically, on the seeed_xiao_rp2350 variant, default `Wire` (Wire0) moved from GP6/GP7 to GP16/GP17 somewhere between 4.4.0 and 5.6.0. The gio board's OLED is wired to GP6/GP7 (which is correct for the schematic — `I2C_SDA` and `I2C_SCL` net labels), and we relied on `Wire` defaulting there. Fix: explicitly target `Wire1` (or `Wire` with `setSDA(D4); setSCL(D5)` before `Wire.begin()`) so the firmware doesn't drift along with framework defaults.
- **picotool's USB-CDC reset trick depends on the running firmware servicing CDC properly.** When you flash a buggy firmware that hangs in setup(), the next `pio run --target upload` will spin trying to reset via baud-touch and fail. Recovery is always: hold **B** + replug USB to force BOOTSEL, then drag-and-drop the new UF2 (or `cp -X` on macOS — without `-X`, cp fails partway through trying to copy extended attributes to FAT32 and bricks the upload).
- **`pio device monitor` needs a TTY**, so it doesn't work from automated/captured shell environments. pyserial works fine for that.
- **When a flashed firmware "works" on a board but a freshly-built copy with the same source doesn't, suspect the build environment, not the hardware.** This took us hours to consider seriously — the natural first instinct was always "what's wrong with the board?" Capture this for future sessions: if old-build + same-XIAO works AND new-build + same-XIAO doesn't → it's the toolchain. Don't desolder anything until you've ruled this out.

### Status now (end of 2026-05-23 session)

- Production arp firmware boots cleanly on board #2.
- OLED renders the menu correctly (`OLED_ROTATION = 0` for this board — board-specific until the rev 2 footprint fix lands; rev 1 board #1 needed `ROTATION = 2` because of its 180° flip rework).
- Encoder rotation updates menu + emits serial events.
- NeoPixel (onboard RGB LED) updates on parameter change — confirmed visible.
- Eurorack power was disconnected at the time of this entry; full analog-chain validation on board #2 still to do next session.

### Followups (firmware/toolchain)

- Pin `platform = ...` URL to a specific commit hash (not `main`).
- Pin `platform_packages` for picotool to a known-good version.
- Decide whether to keep the `BOOT N` and `LOOP heartbeat` diagnostic prints in `main.cpp` permanently (lean: yes, as a `#ifdef DEBUG_BOOT` block — cheap insurance).
- Consider keeping the Serial-first ordering (`Serial.begin()` before `Wire.begin()`) as the permanent convention — makes any future setup() hang at least diagnosable.
- Update bench-wiring docs to note that the OLED is on `Wire1` (not `Wire`) in firmware, even though the schematic net labels are just `I2C_SDA` / `I2C_SCL`.

### Followups (rev 2 PCB — accumulating)

- OLED 4-pin header footprint fix (carry-over from 2026-05-21).
- ADC input protection: BAT54S clamps between op-amp outputs and MCP3208 input pins, plus bump R3/R4 from 1k to 4.7k (so a fault on a jack can't fry an ADC channel like it did on board #1).
- Faceplate design (separate work).

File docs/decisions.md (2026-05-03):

# Design & Process Decisions

Captured from the project kick-off. These settle scope, tooling, and workflow for the first revision of the module. Source of truth for decisions that aren't obvious from the code.

---

## Context

This repo (`gio`) is a 2 HP Eurorack generative arpeggiator based on the XIAO RP2350, specified in [`generative-arp-module.md`](./generative-arp-module.md). It is a spiritual successor to [`xiao-ra4m1-arp`](https://github.com/funkfinger/xiao-ra4m1-arp), adopting the design pivot (encoder + OLED, 2HP, more CV inputs) as the baseline rather than a retrofit.

---

## Decisions

### 1. Monorepo with three top-level areas

```
gio/
├── firmware/arp/     PlatformIO project for the arpeggiator firmware
├── hardware/         KiCad project (schematic, PCB, panel) — added post-v0.1
└── docs/             Spec, decisions, stories
```

**Why:** hardware and firmware revs are tightly coupled on a single-PCB module. Pin assignments are the contract between them and should version together.

### 2. PlatformIO as the build system

Using the earlephilhower arduino-pico platform:

```ini
platform = https://github.com/earlephilhower/arduino-pico.git
board    = seeed_xiao_rp2350
framework = arduino
```

**Why PlatformIO:** scriptable builds, `pio test -e native` for host-side unit tests, library management, CI-friendly.

**Fallback:** `arduino-cli` if PlatformIO hits a wall with the RP2350 board definition.

### 3. PWM DAC instead of external I2C DAC (MCP4725)

The RP2350 has no onboard DAC. Rather than adding an external MCP4725 I2C DAC, V/Oct output uses the RP2350's 12-bit hardware PWM peripheral on D2 (GP28) with a 2-pole passive RC low-pass filter feeding the MCP6002 op-amp.

**PWM DAC parameters:**
- PWM frequency: 150 MHz / 4096 ≈ 36.6 kHz (12-bit wrap, no clock divider)
- Filter: 2× (10 kΩ + 100 nF), f_c ≈ 160 Hz, −40 dB/decade above cutoff
- Ripple at 36.6 kHz: ≈ 63 µV (< 0.1¢) — well below the 2 mV spec
- Settling time (5τ): ≈ 5 ms — fine at 50 ms/step (300 BPM, 16th notes)
- Firmware write: `analogWrite(PIN_DAC_PWM, count)` — no library needed

**Why not MCP4725:**
- MCP4725 shares I2C bus with the OLED → potential bus contention during OLED refresh (~5.8 ms for a full 64×32 frame)
- Extra IC, extra BOM cost, extra library dependency
- PWM + RC filter uses components already in the passives BOM (same 10 kΩ / 100 nF values as op-amp network)
- `analogWrite()` updates are faster than an I2C transaction (~15–20 µs)

**Risk to validate on bench (Story 003):** 36.6 kHz PWM switching noise on D2 may couple into adjacent ADC pins (A0 tempo pot, A1 CV in) on breadboard. Scope the ADC readings while PWM is active. If coupling is a problem on PCB, route PWM trace away from analog inputs and add ground pour between them.

### 4. I2C bus dedicated to SSD1306 OLED

Hardware I2C0 on D4/D5, used exclusively by the SSD1306 OLED (address 0x3C). No bus sharing — the PWM DAC approach eliminates the MCP4725 from the I2C bus entirely.

**Benefit:** OLED can refresh at will without blocking DAC updates. Full 64×32 frame refresh takes ~5.8 ms at 400 kHz — this no longer affects V/Oct timing at all.

### 5. MVP (v0.1) is deliberately minimal

First working firmware:
- Internal clock only (tempo pot drives it)
- Major scale only
- Up-arp, 4 notes (root, 3rd, 5th, octave)
- PWM on D2 → 2-pole RC filter → MCP6002 op-amp → V/Oct out, calibrated
- Gate out via NPN transistor stage
- OLED shows tempo BPM only
- Encoder click cycles through arp orders
- No chaos, no CV in processing, no calibration mode, no NeoPixel

**Why:** the one genuinely novel subsystem is RP2350 PWM → 2-pole RC filter → MCP6002 → Eurorack V/Oct. Prove that before stacking features.

### 6. Reuse logic libraries from xiao-ra4m1-arp verbatim

`lib/scales/`, `lib/arp/`, `lib/tempo/` are pure C++ with no Arduino dependencies. They port without modification. Their existing GoogleTest suites run on the RP2350 native env unchanged.

**Why:** they were TDD'd and bench-validated on the RA4M1 project. No reason to rewrite them.

### 7. KiCad deferred until breadboard signal chain validates

Same rule as RA4M1 project: don't open KiCad until DAC → MCP6002 → multimeter matches the calibration voltage table within ±2 mV.

**New risk for this project:** 36.6 kHz PWM switching on D2 may couple noise into adjacent ADC pins. Confirm on breadboard (Story 003) before committing to PCB traces.

### 8. Dual-purpose input jacks — same hardware, firmware-selectable mode

J1 (A3/GP29) and J2 (A1/GP27) use identical protection and divider circuits: 100 kΩ series + 68 kΩ to GND + BAT54 dual Schottky. This maps 0–8V V/Oct → 0–3.24V at ADC and provides safe clamping for negative or over-voltage signals.

Both jacks can operate as either a **trigger/clock input** (`digitalRead()`, rising-edge detection above ~1.5V) or a **pitch CV input** (`analogRead()` → inverse divider → semitone → `quantize()`). Mode is selected per jack in the encoder menu (CLOCK / PITCH).

**Why:** the requirement was one trigger in and one V/Oct in. Rather than dedicate each jack in hardware — which would require different circuits and fix the panel semantics forever — both jacks get identical hardware and the split is done in firmware. Patcher can reassign either jack. D7 (GP1, previously the clock-only digital input) is freed.

**Why 100 kΩ + 68 kΩ:** the 100 kΩ series resistor limits clamp diode current to < 70 µA even at 10V. The 68 kΩ lower leg maps 0–8V → 0–3.24V, covering 8 octaves of V/Oct with 42 ADC counts/semitone — sufficient for scale quantisation. A lower series resistor (e.g., 3.3 kΩ as in the RA4M1 design) would give faster rise time but the 100 kΩ + 100 pF cable capacitance RC = 10 µs — fine at 300 BPM (50 ms/step).

### 9. Gate / clock timing: `millis()` state machine (non-blocking)

The main loop uses `millis()` timestamps instead of `delay()` for all gate and step timing. Each iteration checks whether enough time has passed to transition state (gate on → gate off → next step), then reads pots, polls the encoder, updates the OLED if needed, and checks for external clock edges — without blocking.

```cpp
// sketch of the pattern
if (millis() - stepStart >= stepMs) {
    stepStart = millis();
    // advance arp, write DAC, gate on
}
if (millis() - stepStart >= gateOnMs) {
    // gate off (if not already)
}
```

**Why not `delay()`:** the RA4M1 firmware blocked for up to 125 ms per half-step. With an encoder, OLED, two ADC reads, and external clock detection in the loop, a blocked loop drops encoder turns, misses clock edges, and delays pot reads by up to 250 ms.

**Why not hardware timer interrupt or dual-core (yet):** `millis()` is the simplest path. The worst-case loop jitter is dominated by I2C OLED refresh (~5.8 ms for a full 64×32 frame), which only happens on parameter change — not every loop. At 300 BPM (50 ms/step), 5.8 ms jitter is 12% of a step: audible in theory, likely inaudible in practice for a generative arp. **Revisit with a hardware timer (Path B) if jitter is audible on the bench.**
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

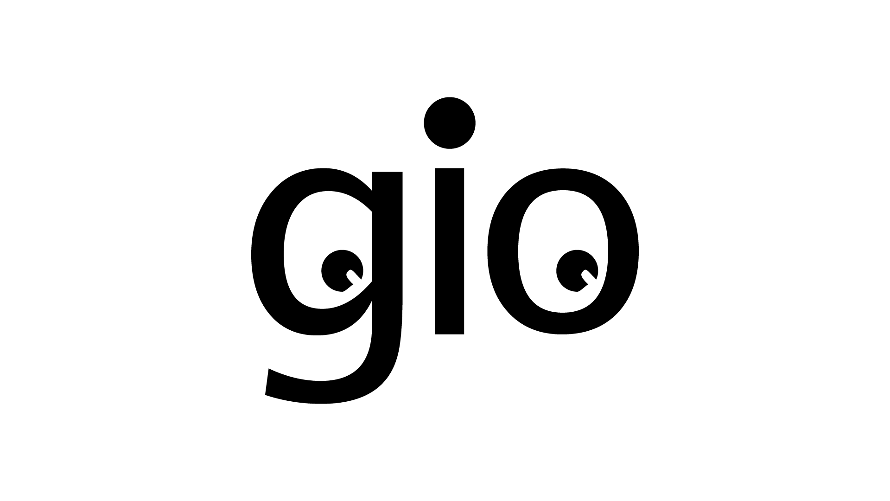
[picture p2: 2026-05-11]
assets/gio.png.gif

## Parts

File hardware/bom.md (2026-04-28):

# gio Rev 0.1 — BOM (JLCPCB)

Single source of truth for the parts that JLCPCB will place during PCB assembly. All choices follow the **Basic-first** rule from `docs/decisions.md` §25.

## SMD parts (placed by JLC)

| Role | Qty | Part # | LCSC | Mfr | Pkg | Class | Unit price |
|---|---|---|---|---|---|---|---|
| +5 V LDO (VDD rail) | 1 | AMS1117-5.0 | C6187 | Advanced Monolithic Systems | SOT-223 | 🟢 Basic | $0.118 |
| 4.096 V precision VREF | 1 | REF3040AIDBZR | C19415 | Texas Instruments | SOT-23 | Extended | $0.194 |
| 16-bit dual SPI DAC | 1 | DAC8552IDGKR | C136020 | Texas Instruments | MSOP-8 | Extended | $3.004 |
| 12-bit 8-ch SPI ADC | 1 | MCP3208T-CI/SL | C626764 | Microchip | SOIC-16 | Extended | $2.170 |
| Dual JFET op-amp | 2 | TL072CDT | C6961 | STMicroelectronics | SO-8 | 🟢 Basic | $0.082 |
| Schottky clamp pair | 4 | BAT54SLT1G | C19726 | onsemi | SOT-23 | Extended | $0.016 |
| Power-rail ferrite | 2 | GZ2012D601TF | C1017 | Sunlord | 0805 | 🟢 Basic | $0.023 |
| Decoupling caps (100 nF) | ~12 | TBD | TBD | TBD | 0805 | 🟢 Basic | trivial |
| Bulk caps (10 µF) | ~6 | TBD | TBD | TBD | 0805 / B-case | 🟢 Basic | trivial |
| Resistors (E24, 0805) | ~30 | TBD | TBD | TBD | 0805 | 🟢 Basic | trivial |

**Per-board chip cost:** ~$5.80
**Per-batch feeder fees (4 unique Extended parts × $3):** ~$12

## Through-hole / panel parts (hand-soldered post-shipment)

Not placed by JLC. Sourced from Thonk / Mouser / inventory.

| Role | Qty | Part | Source |
|---|---|---|---|
| 3.5 mm mono jacks | 4 | Thonkiconn PJ398SM | Thonk |
| 9 mm panel pot | 1 | Alpha 9mm linear taper | Thonk / Mouser |
| Rotary encoder w/ switch | 1 | Bourns PEC11R | Mouser / Digikey |
| Eurorack 2×5 IDC power header | 1 | Standard Doepfer pinout | Thonk / Mouser |
| 1×7 female socket (XIAO) | 2 | 0.1" pitch, through-hole | Mouser / Adafruit / Thonk |
| 0.49" 64×32 SSD1306 OLED | 1 | I²C breakout, hand-soldered | AliExpress / Adafruit |
| XIAO RP2350 daughterboard | 1 | Seeed XIAO RP2350 | Seeed / Mouser |

**Total hand-soldered joints per board:** ~60 (jacks 12, pot 3, encoder 5, power 10, OLED 4, XIAO sockets 14, plus a few jumpers / mounting). Trivial for a hobby run.

## Vetting checklist for future BOM additions

When adding any new SMD line, follow this in order:

1. Search `https://jlcpcb.com/parts/componentSearch?searchTxt=<PART>`
2. **Prefer Basic** when a functional equivalent exists
3. For Extended-only parts, prefer original manufacturer over clones in signal-path roles (references, op-amps, converters)
4. Check stock level — > 500 units is safe; lower means risk of substitution at assembly time
5. Capture LCSC part number + class + unit price in the table above
6. If the choice is non-obvious (e.g. Basic clone vs. Extended original), capture the rationale in `docs/decisions.md`

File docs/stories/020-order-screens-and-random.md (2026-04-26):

# Story 020: Order Screens + Random + UpDownClosed

**As a** patcher
**I want** the OLED to show a graphical bar-chart of each arp order's playback pattern (with random-bars animation when in Random mode)
**So that** I can see at a glance what the arp is doing — including a clear visual cue when randomness is in play

## Engine work

- **Renames** (semantic clarification, no behaviour change for existing code):
  - `ArpOrder::UpDown` → `ArpOrder::UpDownOpen` (palindrome WITHOUT endpoint repeat — `0,1,2,3,2,1`)
  - `ArpOrder::Skip` → `ArpOrder::SkipUp` (forward-looking for a future `SkipDown` and other finger-picking variants)
- **New variants**:
  - `ArpOrder::UpDownClosed` — palindrome WITH endpoint repeat (`0,1,2,3,3,2,1,0`, period `2N`). Both endpoints doubled — top consecutively in the middle of one cycle, bottom across the loop boundary. See `docs/decisions.md` §24 for the open/closed terminology.
  - `ArpOrder::Random` — pure random index per step (with replacement). Uses `std::rand()`; seeded in `setup()` from `millis()` ⊕ noisy `analogRead(PIN_TEMPO)`.
- **Encoder cycle**: `Up → Down → UpDownClosed → UpDownOpen → SkipUp → Random → Up` (matches Aseprite tag order in `assets/screens/order-screen/order.aseprite`).

## UI work

- **Static art** for 5 orders, drawn in Aseprite as bar-chart visualizations of each playback pattern (one bar per note, height = pitch, position = playback order). Tagged `up`, `down`, `up-down-closed`, `up-down-open`, `skip-up` → auto-exported as `order-up.png`, etc., by `tools/aseprite-export.js` → `screens::order_up`, etc.
- **Procedural Random** — when `ArpOrder::Random` is selected, instead of drawing a static bitmap, `drawRandomOrderScreen()` paints 8 vertical bars at random heights across the 32-wide canvas. Called:
  - From `renderMenu()` when ORDER becomes the active param
  - From `fireStep()` on every step advance, ONLY when `active == Param::Order && order == Random` (so the bars pulse with each note when the user is looking at them)
- **Fall-through** to text rendering remains for any order without art.

## Tests

- All existing arp tests renamed (`UpDown` → `UpDownOpen`, `Skip` → `SkipUp`).
- New tests:
  - `UpDownClosedPalindromicWithRepeatEndpoints` — verifies the `0,1,2,3,3,2,1,0` sequence
  - `UpDownClosedTwoNotesSafe` — `count=2` → `0,1,1,0,…` (period 4)
  - `UpDownClosedRepeatsTopAndBottomAcrossLoop` — counts endpoint hits over two cycles
  - `RandomReturnsAllValidIndicesOverManyCalls` — distribution sanity
  - `RandomDistributionIsRoughlyUniform` — ±20% slack across 4000 samples
  - `RandomDeterministicWhenSeeded` — same `srand` seed → same sequence
- Total host tests: 60 → 66, all green.

## Future work (deferred)

- **Highlight the active bar.** Each bar in the diagram represents a note in the chord. When a note plays, brighten/invert that bar (~one-step pulse) so the user sees which position in the order is currently sounding. Direct visual mapping of "we're playing this note now."
- **More finger-picking patterns.** `SkipDown`, `Roll`, etc. — the `SkipUp` rename anticipates this naming family.

## Acceptance criteria

### Firmware
- [x] Engine renames + additions, all tests pass on host
- [x] `orderName()` updated to match new enum (UI strings: `Up`, `Down`, `UpDn-C`, `UpDn-O`, `SkipUp`, `Random`)
- [x] Procedural random-bars renderer implemented and called per-step + on menu activation
- [x] `std::srand()` seeded in `setup()` from `millis()` ⊕ `analogRead(PIN_TEMPO)`
- [x] Forward-decl for `drawRandomOrderScreen()` added so `renderMenu()` (defined earlier) can call it

### Bench
- [ ] Cycle through ORDER param: each of the 5 static orders shows the corresponding bar-chart bitmap
- [ ] Land on Random: bars are visible and re-randomize on every step (audible note + visual jump in lockstep)
- [ ] Random pitch sequence audibly varies (no obvious repetition over many cycles)
- [ ] UpDownClosed audibly doubles the top note (you hear the same pitch twice in a row at the top of each cycle)

## Status

implemented + tests green; bench verification pending flash.

## Depends on

- Story 019 (TRIG menu) for the encoder-cycle pattern
- Aseprite auto-export pipeline (per `assets/screens/README.md`)

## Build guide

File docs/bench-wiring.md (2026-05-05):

# Bench wiring — gio platform rebuild

Single-source wiring reference for the breadboard rebuild covering Stories 012 (SPI bus), 013 (DAC output stage), 015 (input protection + scaling), plus the encoder pin migration. Use alongside `decisions.md` §25 and `hardware/bom.md`.

**Bench substitution removed (2026-05-04):** REF3040AIDBZR (SOT-23-3) now drives the VREF rail directly. The pot+TL072 stand-in is gone. VREF stability went from ±56 mV (pot+TL072 drift) to ±2 mV (essentially MCP3208 LSB noise). See §5 for the swap details.

---

## 1. Bill of materials on the breadboard

Through-hole / DIP versions to keep this hand-wireable:

| Role | Part | Inventory location | Notes |
|---|---|---|---|
| MCU | Seeed XIAO RP2350 | (in hand) | On female socket strips |
| 16-bit DAC | DAC8552 (MSOP-8 on adapter) | (already soldered to breakout) | |
| 12-bit ADC | MCP3208-CI/P (PDIP-16) | (1× already soldered to breakout; spares from Digikey order) | |
| Op-amp | TL072CP (DIP-8) | `tl072cp-dual-jfet-opamp.md` | Need 2× — one for DAC outputs, one for ADC inputs + VREF buffer |
| Schottky | BAT43 (DO-35 axial) | Cab-2 / Bin-10, 50+ | 8 needed (2 per jack × 4 jacks) — bench uses singles, PCB uses BAT54S |
| OLED | 0.49" 64×32 SSD1306 I²C | (on hand) | |
| Encoder | PEC11R | (on hand) | |
| Pot (tempo) | 10 kΩ linear | (on hand) | |
| Pot (VREF trim) | 10 kΩ multi-turn trimpot | (on hand or Bourns 3296) | Bench stand-in for REF3040 |
| Power | Hivemind Protomato | (in hand) | Provides ±12 V, +5 V, GND |

Resistors / caps assumed available in standard E12 values.

---

## 2. Power distribution

Protomato delivers ±12 V, +5 V, GND directly onto breadboard rails. No on-breadboard regulation needed.

| Rail | Source | Goes to |
|---|---|---|
| **+12 V** | Protomato +12 | TL072 V+ (pin 8 of each), BAT43 anode-side clamps |
| **−12 V** | Protomato −12 | TL072 V− (pin 4 of each), BAT43 cathode-side clamps |
| **+5 V** | Protomato +5 | DAC8552 VDD, MCP3208 VDD, XIAO 5V pin, VREF trim pot CW |
| **+3.3 V** | XIAO 3V3 | (none externally — XIAO uses internally) |
| **GND** | Common | All grounds — single star point at the Protomato output |

**Decoupling caps** (place close to each IC's supply pin):
- 100 nF ceramic on each TL072 V+ and V− (4 caps total)
- 100 nF on DAC8552 VDD
- 100 nF on MCP3208 VDD
- 100 nF on REF-buffer output (the VREF rail) — see §5
- 10 µF electrolytic bulk somewhere on the +5 V rail

---

## 3. XIAO RP2350 pinout (with encoder migration)

Pin assignments after the SPI-pivot. **Encoder moves off D8/D9/D10** (now SPI) **to A1/A2/D7**.

| XIAO pin | GPIO | Net | Direction | Notes |
|---|---|---|---|---|
| D0 | GP26 | CLOCK_IN (digital) | input | Reserved for J1 clock/gate edge detection. Freed 2026-05-02 when tempo pot moved to the MCP3208 (CH0 per the 2026-05-03 channel-layout convention). |
| D1 | GP27 | ENCODER_A | input | Encoder A (was D8) |
| D2 | GP28 | ENCODER_B | input | Encoder B (was D9) |
| D3 | GP5 | CS_DAC | output | DAC8552 /SYNC |
| D4 | GP6 | I2C_SDA | bidir | OLED SDA |
| D5 | GP7 | I2C_SCL | output | OLED SCL |
| D6 | GP0 | CS_ADC | output | MCP3208 /CS |
| D7 | GP1 | ENCODER_CLICK | input | Encoder push-switch (was D10) |
| D8 | GP2 | SPI_SCK | output | Shared SPI0 clock |
| D9 | GP4 | SPI_MISO | input | Shared SPI0 MISO (from MCP3208 only) |
| D10 | GP3 | SPI_MOSI | output | Shared SPI0 MOSI |
| 5V | — | +5 V | input | From Protomato |
| 3V3 | — | +3.3 V | output | XIAO regulator output (unused on the bench; routed on PCB for CS pull-ups) |
| GND | — | GND | — | |

**Pull-ups — bench skips them, PCB adds them:**

- **Encoder (A/B/click)** — no externals needed. `encoder_input.cpp` configures `INPUT_PULLUP` so the RP2350's internal pull-ups (~50–80 kΩ) handle idle state. Same on bench and PCB.
- **CS_DAC / CS_ADC** — skip on the bench. Adds 2× 10 kΩ to +3.3 V on the PCB as belt-and-suspenders to keep both SPI ICs deselected during the ~200–500 ms power-on → bootloader → firmware-init window. The risk without them is essentially zero (SPI ICs need clocked frames to do anything), but two 0805 resistors cost nothing on the board.
- **RP2350-E9 errata is irrelevant here** — it only affects pull-*downs*. Every pull on this design is a pull-up.

---

## 4. SPI bus wiring (shared bus, two chip-selects)

```
                ┌────────────────────────────────────────┐
                │                                         │
   XIAO         │   DAC8552 (MSOP-8 on breakout)         │
   ─────────    │   ────────────────────────────         │
   SCK  D8 ────●────── SCLK (pin 6)                      │
   MOSI D10 ───●────── DIN  (pin 7)                      │
   CS_DAC D3 ─────────  /SYNC (pin 5)                    │
                                                          │
                │   MCP3208 (PDIP-16 on breakout)        │
                │   ─────────────────────────────        │
                ●────── CLK  (pin 13)                    │
                ●────── DIN  (pin 11)                    │
   MISO D9 ─────────── DOUT (pin 12)                     │
   CS_ADC D6 ───────── /CS  (pin 10)                     │
                                                          │
                └────────────────────────────────────────┘
```

`●` = shared bus node (jumper to both ICs).

**MCP3208 power + reference pins:**

| MCP3208 pin | Net |
|---|---|
| 9 (DGND) | GND |
| 14 (AGND) | GND |
| 15 (VREF) | VREF rail (4.096 V — see §5) |
| 16 (VDD) | +5 V |

**DAC8552 power + reference pins** (per TI datasheet SLAS430A, MSOP-8 DGK package):

| DAC8552 pin | Net |
|---|---|
| 1 (VDD) | +5 V |
| 2 (VREF) | VREF rail (4.096 V) — **single shared reference** for both channels |
| 3 (VOUTB) | → input of output-stage B op-amp (§6) |
| 4 (VOUTA) | → input of output-stage A op-amp (§6) |
| 8 (GND) | GND |

---

## 5. VREF stand-in (pot + TL072 buffer)

Temporary substitute for the REF3040. Lives until the SOT-23 arrives, at which point this whole sub-circuit gets snipped out and the REF3040 drops in at the `VREF rail` node with the same 100 nF decoupling.

### TL072 (DIP-8) pinout reference

The TL072 is a **dual** op-amp — two independent channels in one 8-pin package, plus shared power. We use channel A here for the VREF buffer; channel B is free for other uses (e.g., one of the input/output stages later).

```
              ┌──┬──┐
   1OUT (A) ──┤1 ⌣ 8├── V+   (+12 V)
   1IN− (A) ──┤2   7├── 2OUT (B)
   1IN+ (A) ──┤3   6├── 2IN− (B)
        V− ──┤4   5├── 2IN+ (B)
   (−12 V)   └─────┘
```

- **Channel A**: pins 1 (OUT), 2 (IN−), 3 (IN+) — used for VREF buffer below
- **Channel B**: pins 5 (IN+), 6 (IN−), 7 (OUT) — unused in §5; available
- **Power**: pin 8 (V+) → +12 V, pin 4 (V−) → −12 V — shared by both channels

### Pot terminal convention

A standard 3-terminal pot has terminals numbered **1, 2, 3** stamped on the body. Looking at the shaft from the front:

- **Terminal 1 (CCW end)** — leftmost when shaft is fully counter-clockwise
- **Terminal 2 (wiper)** — middle pin, voltage scales with shaft position
- **Terminal 3 (CW end)** — rightmost

For a **multi-turn trimpot** (Bourns 3296 etc.) the terminals are labeled the same. CW direction increases voltage at the wiper when terminal 3 is tied to +5 V.

### Wire list

Build this as a simple checklist on the breadboard. Every wire goes between exactly two named points.

| # | From | To | Notes |
|---|---|---|---|
| 1 | +5 V rail | Pot terminal 3 (CW) | Top of divider |
| 2 | GND rail | Pot terminal 1 (CCW) | Bottom of divider |
| 3 | Pot terminal 2 (wiper) | TL072 pin 3 (1IN+) | Divided voltage into the buffer's non-inverting input |
| 4 | TL072 pin 1 (1OUT) | TL072 pin 2 (1IN−) | Feedback wire — makes the buffer unity-gain (output follows input) |
| 5 | TL072 pin 8 (V+) | +12 V rail | Op-amp positive supply |
| 6 | TL072 pin 4 (V−) | −12 V rail | Op-amp negative supply |
| 7 | TL072 pin 1 (1OUT) | **VREF rail** node | The clean, buffered VREF — feed this to DAC8552 pin 2 and MCP3208 pin 15 |
| 8 | 100 nF cap | TL072 pin 8 → GND | Power decoupling, V+ side |
| 9 | 100 nF cap | TL072 pin 4 → GND | Power decoupling, V− side |
| 10 | 100 nF cap | VREF rail → GND | Reference decoupling at the buffer output |
| 11 | TL072 pin 5 (2IN+) | GND rail | **Park unused channel B** — input held at 0 V |
| 12 | TL072 pin 6 (2IN−) | TL072 pin 7 (2OUT) | **Park unused channel B** — unity-gain feedback so output settles at 0 V |

> **Why wires 11 + 12:** the TL072 is a dual op-amp; if you wire only channel A, the unused channel B's inputs (pins 5 and 6) are floating. Floating CMOS-style inputs pick up noise that puts the IC into uncontrolled saturation or oscillation, and that disturbance couples into channel A through shared substrate and power pins — degrading the VREF you just worked to clean up. Standard fix: tie the unused channel as a grounded unity-gain follower (input to GND, output to inverting input). Two short wires, no extra parts.

### Schematic view

```
                                       +12V    GND
                                         │      │
                                         │      ┴── 100nF (decoupling, pin 8)
                                         │
+5V ──[pot CW, term 3]                  ┌┴─┐
              │                         │ 8│V+
            [pot]──[wiper, term 2]──────│3 │1IN+ (channel A)
              │                         │  │      ╲
GND ──[pot CCW, term 1]            ┌────│2 │1IN−   ─── pin 1 (1OUT)
                                   │    │  │      ╱       │
                                   │    │  │              │
                                   │    │ 4│V−            │
                                   │    └┬─┘              │
                                   │     │                │
                                   │    -12V              │
                                   │     │                │
                                   │     ┴── 100nF (decoupling, pin 4)
                                   │                      │
                                   └──── feedback ────────┤
                                       (pin 1 → pin 2)    │
                                                          │
                                              VREF rail ──┴── 100nF to GND
                                                          │
                                                          ├── DAC8552 pin 2 (VREF)
                                                          └── MCP3208 pin 15 (VREF)

   Channel B (unused) — parked as grounded unity-gain follower:

      GND ──── pin 5 (2IN+)
              ┌─ pin 7 (2OUT) ─── (no external connection — sits at 0 V)
              │
              └── pin 6 (2IN−)
```

### Bench procedure

1. **Build with VREF rail disconnected from the DAC/ADC.** Wires 1–6 + 8–9 only at first.
2. **Power up** the Protomato. Confirm ±12 V and +5 V rails on the multimeter.
3. **Meter on TL072 pin 1** (the buffer output). Turn the pot's screw until the reading is **4.096 V ± 5 mV**.
   - If the voltage moves opposite to expectations as you turn, swap pot terminals 1 and 3 — you've got CW and CCW reversed for your particular pot.
   - Multi-turn trimpots take ~25 turns end-to-end; expect to spin a lot.
4. **Add wire 7 + cap 10** — connect the buffered VREF to the rail going to DAC8552 pin 2 and MCP3208 pin 15.
5. **Re-meter the TL072 output.** Should not move from 4.096 V — that's the whole point of the buffer (the IC inputs are high-Z and the buffer absorbs any transient currents).
6. **Mark the trimpot screw position** with a Sharpie or lock the screw if it has one. Vibration can drift it.

### Why a buffer (not a bare divider into the converter VREF pins)

The DAC8552's R-2R ladder draws transient current on its VREF pin every time the output code changes. With a bare resistor divider, the divider's output impedance (a few kΩ) would let those transients pull VREF around — by tens of millivolts during fast updates. The TL072 follower presents a low-Z source (≈10 Ω at audio rates), absorbs the transient, and keeps the reference rock-stable.

Same logic applies to the MCP3208: each conversion samples a 20 pF capacitor onto VREF for ~1.5 µs. A buffered reference settles cleanly between conversions; a bare divider doesn't.

### Drop-in done — REF3040 on the bench (2026-05-04)

All of §5 above is **historical** — the pot+TL072 stand-in has been replaced. Current VREF source:

| Wire / part | From | To | Notes |
|---|---|---|---|
| 1 | REF3040 **pin 1 (VIN)** | +5 V rail | TI REF30xx series in DBZ (SOT-23-3) package |
| 2 | REF3040 **pin 2 (GND)** | GND rail | |
| 3 | REF3040 **pin 3 (VOUT)** | **VREF rail node** | Same node that feeds DAC8552 pin 2, MCP3208 pin 15, all four bias dividers, pot CW |
| 4 | 100 nF cap | REF3040 pin 1 → GND | Input decoupling, close to chip |
| 5 | **1 µF cap** | REF3040 pin 3 → GND | **Required for stability** per datasheet |

**Verified at the bench (2026-05-04):** VREF rail reads 4.094–4.096 V across a 4 s window (±2 mV total — essentially MCP3208 LSB noise). Pot+TL072 stand-in fully removed; TL072 #1 also pulled (REF3040's 25 mA output drives the ~1 mA total load directly without buffering). This matches the production PCB topology exactly.

**Note on pin numbers:** the SOT-23-3 pin assignment varies by manufacturer; the table above is per TI's REF3040 datasheet (DBZ package). Always verify against the part's datasheet before powering on.

---

## 6. DAC output stage (per channel — 2× identical)

Inverting amplifier (with offset on the non-inverting input) turns the DAC's 0..4.096 V swing into a ±9 V Eurorack-friendly bipolar output, then protects the jack with a 1 kΩ series resistor and a BAT43 clamp pair to ±12 V.

**One TL072 IC handles both channels** — channel A drives DAC OUTA → jack J3; channel B drives DAC OUTB → jack J4. No parking needed because both channels are active.

(See §5 for the TL072 DIP-8 pinout reference. We're using a *second* TL072 IC here — call it TL072 #2.)

### Topology — why offset is on pin 3, not pin 2

A naive inverting summing amp with both VDAC and VREF on the inverting input (pin 2) **doesn't work** with a single positive reference: both contributions invert, and `Vout = −(R_fb/R_in)·VDAC − (R_fb/R_off)·VREF` rails to negative for any DAC value (validated empirically 2026-04-29 — see `bench-log.md`).

The fix is to put the offset reference on the **non-inverting input (pin 3)** via a divider. That makes the offset contribution *non-inverting* (positive at the output) while VDAC stays *inverting* (negative-going at the output), giving a real bipolar swing from a single positive reference.

### Resistor values

| Symbol | Where | Value (E96 / E12) | Purpose |
|---|---|---|---|
| R_in | DAC pin 4 → pin 2 | **10 kΩ** | Sets gain magnitude with R_fb |
| R_fb | pin 1 → pin 2 | **48.7 kΩ** (or 47 kΩ E12; or 2× 22 kΩ in series = 44 kΩ) | Feedback resistor — sets gain = R_fb / R_in |
| R_div_top | VREF rail → pin 3 | **22 kΩ** | Top leg of offset divider |
| R_div_bot | pin 3 → GND | **15 kΩ** (or 14.7 kΩ E96) | Bottom leg of offset divider |
| R_jack_series | pin 1 → jack tip | **1 kΩ** | Output isolation / short-circuit current limit |

Divider sets V_pin3 = VREF · R_div_bot/(R_div_top + R_div_bot) ≈ **1.66 V** with the values above.

### Math

Inverting amp with non-inverting offset:

```
Vout = (1 + R_fb/R_in)·V_pin3 − (R_fb/R_in)·VDAC
```

With R_fb = 44 kΩ (2× 22 kΩ E12), R_in = 10 kΩ, V_pin3 = 1.66 V, VREF = 4.096 V:

```
Vout = 5.4·1.66 − 4.4·VDAC ≈ 8.96 − 4.4·VDAC
```

Target mapping:

| DAC voltage | Op-amp output (= jack) |
|---|---|
| 0 V | **≈ +8.96 V**  (max positive) |
| 2.048 V | **≈ 0 V** (midpoint) |
| 4.096 V | **≈ −9.06 V**  (max negative) |

Firmware compensates the inversion in `outputs::write()` calibration (gain ≈ −1/4.4 scaled to volts; offset ≈ +V_pin3·gain; bench-fit per channel).

If you want closer to the spec'd ±10 V (instead of ±9 V), use R_fb = 48.7 kΩ E96 — gain rises to 4.87, output swing widens proportionally.

### Wire list — channel A (DAC OUTA → jack J3)

Channel A pins on TL072 #2: pin 1 (1OUT), pin 2 (1IN−), pin 3 (1IN+).

| # | From | To | Notes |
|---|---|---|---|
| A1 | TL072 #2 pin 8 (V+) | +12 V rail | Op-amp positive supply (shared by both channels) |
| A2 | TL072 #2 pin 4 (V−) | −12 V rail | Op-amp negative supply (shared) |
| A3 | TL072 #2 pin 8 → GND | 100 nF cap | V+ decoupling |
| A4 | TL072 #2 pin 4 → GND | 100 nF cap | V− decoupling |
| A5 | VREF rail | One end of R_div_top (22 kΩ) | Top leg of the pin-3 offset divider |
| A6 | Other end of R_div_top | TL072 #2 pin 3 (1IN+) | Pin 3 is the divider's mid-point |
| A7 | TL072 #2 pin 3 (1IN+) | One end of R_div_bot (15 kΩ) | Bottom leg of the divider |
| A8 | Other end of R_div_bot | GND rail | Closes the divider — V_pin3 ≈ 1.66 V |
| A9 | DAC8552 pin 4 (VOUTA) | One end of R_in (10 kΩ) | DAC signal into the summing node |
| A10 | Other end of R_in | TL072 #2 pin 2 (1IN−) | Summing node — also receives R_fb |
| A11 | TL072 #2 pin 1 (1OUT) | One end of R_fb (44 kΩ via 2× 22 kΩ) | Feedback resistor |
| A12 | Other end of R_fb | TL072 #2 pin 2 (1IN−) | Closes the feedback loop |
| A13 | TL072 #2 pin 1 (1OUT) | One end of R_jack_series (1 kΩ) | Output isolation resistor |
| A14 | Other end of R_jack_series | Jack J3 tip | The actual ±9 V output |
| A15 | BAT43 #1 anode | Jack J3 tip | Clamp diode for positive overshoot |
| A16 | BAT43 #1 cathode | +12 V rail | When jack > +12 V + Vf, this diode conducts → pulls jack down to +12 V |
| A17 | BAT43 #2 cathode | Jack J3 tip | Clamp diode for negative overshoot |
| A18 | BAT43 #2 anode | −12 V rail | When jack < −12 V − Vf, this diode conducts → pulls jack up to −12 V |
| A19 | Jack J3 sleeve | GND rail | Standard mono-jack ground |

### Wire list — channel B (DAC OUTB → jack J4)

Channel B pins on TL072 #2: pin 5 (2IN+), pin 6 (2IN−), pin 7 (2OUT). Power and decoupling are **shared** with channel A — no need to repeat A1–A4. The pin-3 offset divider can also be **shared** with channel A's pin 5: tie pin 5 to pin 3, and skip a separate divider.

| # | From | To | Notes |
|---|---|---|---|
| B1 | TL072 #2 pin 5 (2IN+) | TL072 #2 pin 3 (1IN+) | Share channel A's offset divider |
| B2 | DAC8552 pin 3 (VOUTB) | One end of R_in (10 kΩ) | New 10 kΩ resistor |
| B3 | Other end of R_in | TL072 #2 pin 6 (2IN−) | Summing node |
| B4 | TL072 #2 pin 7 (2OUT) | One end of R_fb (44 kΩ) | New 44 kΩ (or 47 kΩ E12, or 48.7 kΩ E96) |
| B5 | Other end of R_fb | TL072 #2 pin 6 (2IN−) | Closes the loop |
| B6 | TL072 #2 pin 7 (2OUT) | One end of R_jack_series (1 kΩ) | New 1 kΩ |
| B7 | Other end of R_jack_series | Jack J4 tip | |
| B8 | BAT43 #3 anode | Jack J4 tip | Positive clamp |
| B9 | BAT43 #3 cathode | +12 V rail | |
| B10 | BAT43 #4 cathode | Jack J4 tip | Negative clamp |
| B11 | BAT43 #4 anode | −12 V rail | |
| B12 | Jack J4 sleeve | GND rail | |

> **Diode polarity sanity check:** for the positive clamp, the diode has its **anode at the jack** (the side that might overshoot up) and **cathode at the +12 V rail** (the safe ceiling). When the jack tries to go above +12 V + Vf (~+12.3 V), the diode forward-biases and dumps the excess into the rail. The negative clamp is the mirror image. If you wire a clamp backward, it'll either do nothing (just float reverse-biased forever) or short the rail to GND through the op-amp output — measure carefully before powering up.

### Schematic view (channel A; channel B is identical)

```
  DAC8552 pin 4 (VOUTA, 0..4.096V)            +12V    GND
            │                                    │      │
        ┌───┴───┐                                │      ┴── 100nF
        │ R_in  │                                │
        │ 10kΩ  │                              ┌─┴──┐
        └───┬───┘                              │ 8  │V+
            │            ┌──── R_fb 44kΩ ────┐ │    │
            │            │                   │ │    │
            │            │                   └─│ 2  │1IN−   ╲
            └──────── pin 2 (1IN−) ────────────│    │       ─── pin 1 (1OUT)
                                               │    │       ╱        │
                                               │    │                │
   VREF rail ─[R_div_top 22kΩ]─┐               │    │                │
                                ├── pin 3 ─────│ 3  │1IN+            │
                  GND ─[R_div_bot 15kΩ]─┘      │    │                │
                                               │ 4  │V−              │
                                               └─┬──┘                │
                                                 │                   │
                                                -12V                 │
                                                 │                   │
                                                 ┴── 100nF           │
                                                                     │
                                        ┌── R_jack_series (1kΩ) ─────┘
                                        │
                                        ├──[BAT43 anode→J3, cathode→+12V]── (clamp +)
                                        ├──[BAT43 cathode→J3, anode→−12V]── (clamp −)
                                        │
                                        └─── J3 tip (Eurorack OUT 1)
                                             J3 sleeve → GND

  Channel B reuses the same offset divider — pin 5 (2IN+) tied directly to pin 3.
```

### Bench procedure

1. **Build channel A only** (wires A1–A19). Leave channel B + jack J4 for after channel A passes.
2. **Power up.** First sanity check: meter pin 3 → should read **≈ +1.66 V** (the divider). Then meter pin 2 → should read the same as pin 3 within a few mV (op-amp's "virtual short" via feedback).
3. **Don't connect DAC8552 pin 4 yet.** Instead, jumper the R_in input end (where DAC pin 4 will land) to **GND** — this simulates VDAC = 0.
4. **Meter on jack J3 tip** — should read **≈ +9 V** (precise value depends on your divider and R_fb).
5. Move the jumper from GND to **VREF rail (+4.096 V)** — simulates VDAC = 4.096 V.
6. **Re-meter J3** — should read **≈ −9 V**.
7. *(Optional)* Move the jumper to a midpoint voltage near +2 V (any divider tap or matched-resistor pair) — J3 should read **≈ 0 V**.
8. **Now connect DAC8552 pin 4** to the R_in input end (wire A9). Flash the smoke-test firmware:
   ```
   pio run -d firmware/arp -e seeed-xiao-rp2350-smoketest --target upload
   ```
   The 1 Hz triangle on the DAC will produce a 1 Hz triangle at J3, swinging ≈ ±9 V.
9. Once channel A is solid, **remove the channel-B parking wires** (pin 5 to GND, pin 6 to pin 7) and add the channel-B wiring (B1–B12 above).

### Calibration

Once both channels track linearly, fill in the firmware calibration in `outputs::setCalibration(channel, gain, offset)`. The transfer function is `Vjack = (1 + R_fb/R_in)·V_pin3 − (R_fb/R_in)·VDAC`, so:

- Pick two known DAC voltages (e.g., 1.0 V and 3.0 V), measure the resulting jack voltage with a multimeter
- Solve for the linear `Vjack = gain·VDAC + offset` per channel
- The firmware applies the inverse mapping when you call `outputs::write(channel, target_jack_volts)` — it computes the DAC voltage that produces the target jack output

---

## 7. Input protection + scaling (per channel — 2× identical)

Mirror of the output stage in reverse: a protected, attenuated, biased ±10 V jack input → 0..4.096 V at the ADC.

**Topology, in order from jack to ADC:**

1. 100 kΩ series resistor at the jack (limits clamp current under abuse)
2. BAT43 dual clamp to ±12 V rails right after the series resistor (at "node A")
3. Inverting summing amplifier (R_in2 in, R_off offset from VREF, R_fb feedback)
4. Op-amp output → MCP3208 channel pin

**IC allocation:** one TL072 channel per ADC input. We'll use a **third TL072 IC (TL072 #3)** — channel A for input 1, channel B for input 2. (TL072 #1's channel A is the VREF buffer; channel B is parked. TL072 #2 is fully consumed by the DAC outputs.)

**For first bench session: wire input 1 only.** Channel B on TL072 #3 stays parked until you've confirmed input 1 tracks correctly via known voltages.

(See §5 for TL072 DIP-8 pinout.)

### Topology — same offset-on-pin-3 trick as §6, with attenuation

Mirror of §6's output stage in reverse: a single op-amp inverting stage with the bias offset applied through a divider on the **non-inverting input (pin 3)**, not on the inverting input. The §6 lesson applies — combining VDAC and VREF on a single inverting node with a single positive supply doesn't produce the bipolar mapping we want.

There's also a **second math trap specific to this stage**: R_series and R_in2 are *in series* between the jack and the op-amp's virtual-ground inverting input. They look like a single combined input resistor of value `R_series + R_in2`. The gain is therefore `R_fb / (R_series + R_in2)`, **not** `R_fb / R_in2` — easy to miss when the topology has two distinct-looking resistors. (Caught at the bench 2026-04-30 — see `bench-log.md`.)

### Resistor values

| Symbol | Where | Value (E96 / E12) | Purpose |
|---|---|---|---|
| R_series | jack tip → node A | **100 kΩ** | Jack input impedance + clamp current limit (±15 V abuse → 30 µA, BAT43 sees < 0.02 % of its rating) |
| R_in2 | node A → pin 2 | **22 kΩ** | Second input resistor; sets gain in series with R_series |
| R_fb | pin 1 → pin 2 | **22 kΩ** | Feedback — sets gain = R_fb / (R_series + R_in2) ≈ 0.180 |
| R_div_top | VREF → pin 3 | **22 kΩ** | Top leg of offset divider |
| R_div_bot | pin 3 → GND | **15 kΩ** (or 14.7 kΩ E96) | Bottom leg of offset divider |

Divider sets V_pin3 = VREF · R_div_bot / (R_div_top + R_div_bot) ≈ **1.66 V**.

### Math

```
Vout = (1 + R_fb/(R_series + R_in2)) · V_pin3 − (R_fb/(R_series + R_in2)) · V_jack
     = 1.180 · 1.66 − 0.180 · V_jack
     ≈ 1.96 − 0.180 · V_jack
```

Target mapping at the ADC (with VREF = 4.096 V):

| Jack input | Op-amp output → ADC | ADC count (12-bit) |
|---|---|---|
| +10 V  | ≈ +0.16 V | ≈ 160 |
| +5 V | ≈ +1.06 V | ≈ 1060 |
| 0 V | ≈ +1.96 V | ≈ 1960 |
| −5 V | ≈ +2.86 V | ≈ 2860 |
| −10 V  | ≈ +3.76 V | ≈ 3760 |

Uses ~88 % of the ADC range with margin at both ends — preferred over a tighter ±10 V → 0..4.096 V mapping that would risk clipping at the rails. Firmware reverses the inversion + offset in `inputs::readVolts()` calibration; bench-fit per channel.

### Wire list — channel A (jack J1 → MCP3208 CH1)

Channel A pins on TL072 #3: pin 1 (1OUT), pin 2 (1IN−), pin 3 (1IN+).

| # | From | To | Notes |
|---|---|---|---|
| 1 | TL072 #3 pin 8 (V+) | +12 V rail | Op-amp positive supply |
| 2 | TL072 #3 pin 4 (V−) | −12 V rail | Op-amp negative supply |
| 3 | TL072 #3 pin 8 → GND | 100 nF cap | V+ decoupling |
| 4 | TL072 #3 pin 4 → GND | 100 nF cap | V− decoupling |
| 5 | VREF rail | One end of R_div_top (22 kΩ) | Top leg of pin-3 offset divider |
| 6 | Other end of R_div_top | TL072 #3 pin 3 (1IN+) | Pin 3 is the divider's mid-point |
| 7 | TL072 #3 pin 3 (1IN+) | One end of R_div_bot (15 kΩ) | Bottom leg of divider |
| 8 | Other end of R_div_bot | GND rail | Closes the divider — V_pin3 ≈ 1.66 V |
| 9 | Jack J1 tip | One end of R_series (100 kΩ) | Jack feeds the protection / scaling chain |
| 10 | Other end of R_series | "node A" (a free row on the breadboard) | Node A is the input-protection junction point |
| 11 | BAT43 #5 cathode | Node A | Clamp diode for **negative** undershoot |
| 12 | BAT43 #5 anode | −12 V rail | When node A < −12 V − Vf, this diode forward-biases and pulls node A back up |
| 13 | BAT43 #6 anode | Node A | Clamp diode for **positive** overshoot |
| 14 | BAT43 #6 cathode | +12 V rail | When node A > +12 V + Vf, this diode forward-biases and pulls node A back down |
| 15 | Node A | One end of R_in2 (22 kΩ) | Signal into the summing node via R_in2 |
| 16 | Other end of R_in2 | TL072 #3 pin 2 (1IN−) | Summing node — also receives R_fb |
| 17 | TL072 #3 pin 1 (1OUT) | One end of R_fb (22 kΩ) | Feedback resistor |
| 18 | Other end of R_fb | TL072 #3 pin 2 (1IN−) | Closes the feedback loop |
| 19 | TL072 #3 pin 1 (1OUT) | **MCP3208 pin 2 (CH1)** | J1 lives at CH1 per the 2026-05-03 channel-layout convention (CH0 = pot, CH1/CH2 = jacks). |
| 20 | Jack J1 sleeve | GND rail | Standard mono-jack ground |
| **Park unused channel B** | | | |
| 21 | TL072 #3 pin 5 (2IN+) | GND rail | Channel B input grounded |
| 22 | TL072 #3 pin 6 (2IN−) | TL072 #3 pin 7 (2OUT) | Channel B unity-gain feedback so output sits at 0 V |

When you're ready to add **channel B** (jack J2 → **MCP3208 CH2**, pin 3), remove wires 21–22 and add a parallel set of wires repeating the input/feedback portion (wires 9–19 above) using channel B's pin numbers (5/6/7) and routing the output to **MCP3208 pin 3 (CH2)**. Channel B can share channel A's offset divider via pin 5 → pin 3 — no second divider needed (mirror of the §6 channel-B trick).

> **Diode polarity sanity check (mirrored from §6):** the input clamps go on **node A**, *after* the 100 kΩ series resistor — not directly at the jack. This is intentional: the series resistor limits clamp current to safe levels (30 µA worst case), and node A is a low-current point where the clamp can hold the voltage without burning the diode out. Polarity at node A is the same logic as §6: anode-to-jack-side / cathode-to-rail for positive overshoot; cathode-to-jack-side / anode-to-rail for negative.

### Schematic view (channel A)

```
  Jack J1 tip                                  +12V        GND
        │                                        │          │
   ┌────┴─────┐                                  │          ┴── 100nF
   │ R_series │                                  │
   │  100 kΩ  │                                ┌─┴──┐
   └────┬─────┘                                │ 8  │V+
        │ (node A)                             │    │
        ├──[BAT43 anode → +12V; cathode → A]── │    │
        ├──[BAT43 cathode → −12V; anode → A]── │    │
        │                                      │    │
   ┌────┴─────┐                                │    │      ╲
   │ R_in2    │                                │ 2  │1IN−   ─── pin 1 (1OUT)
   │  22 kΩ   │                                │    │      ╱       │
   └────┬─────┘                                │    │              │
        │                  ┌── R_fb 22kΩ ──┐   │    │              │
        └──── pin 2 (1IN−) ┤                │   │ 4  │V−            │
                            │                │   └─┬──┘              │
                            └── pin 1 (1OUT)─┘     │                 │
                                                  -12V               │
                                                   │                 │
                                                   ┴── 100nF         │
                                                                     │
   VREF rail ─[R_div_top 22kΩ]─┐                                     │
                                ├── pin 3 (1IN+)                     │
                  GND ─[R_div_bot 15kΩ]─┘                            │
                                                                     │
                                              MCP3208 pin 2 (CH1) ───┘

   Channel B (unused on first session) — parked as in §5:
      TL072 #3 pin 5 (2IN+) ── GND
      TL072 #3 pin 6 (2IN−) ── TL072 #3 pin 7 (2OUT)
```

### Bench procedure

1. **Wire channel A only** (wires 1–20). Park channel B with wires 21–22.
2. **Power up.** Confirm ±12 V and the +5 V / VREF rails are still clean. Sanity-check pin 3 — should read **≈ +1.66 V** (the divider). Pin 2 should track pin 3 within a few mV (op-amp's "virtual short" via feedback).
3. **First test — jack J1 tip jumpered to GND.** Meter at TL072 #3 pin 1 (1OUT). Should read **≈ +1.96 V** — this is the bias-only output: `(1 + R_fb/(R_series+R_in2)) · V_pin3 = 1.180 · 1.66 = 1.96`. **Note:** with the jack truly floating, no current can flow through R_series + R_in2, so no offset gain develops and pin 1 sits at V_pin3 ≈ +1.66 V instead. The +1.96 V reading only appears when the jack is **actively grounded** — that's the test condition. (Caught 2026-05-02 — see `bench-log.md`.)
4. **Second test — apply +5 V to jack J1 tip** from a bench supply (or through R_series from any +5 V source).
   - Expected output at TL072 #3 pin 1: **≈ +1.06 V** (`Vout = 1.96 − 0.180·5 = 1.06`).
5. **Third test — apply −5 V to jack J1 tip.**
   - Expected output: **≈ +2.86 V** (`Vout = 1.96 − 0.180·(−5) = 2.86`).
6. **If the slope between the +5 and −5 readings is ≈ −0.18 V per V of input**, the stage is working — even if absolute offsets are off by 5–10 % due to E12 substitutions and pot dial-in.
7. **Run the smoke-test firmware.** The reported `adc_v` should sit near 1.96 V with no input. Patch a Eurorack cable from J3 → J1 to close the loop, and `adc_v` will sweep predictably with the DAC's triangle (ranging roughly 0.4 V to 3.6 V over each 1-second cycle).
8. **Calibrate** by applying two known voltages (e.g., +5 V and −5 V), reading the resulting `adc_count`, and computing the per-channel `gain` and `offset` for `inputs::setCalibration()`.
9. **Once channel A passes**, remove wires 21–22 and add the channel-B input/feedback wires per the note above.

---

## 8. OLED + encoder + tempo pot

| Device | Pin | Net |
|---|---|---|
| OLED | VCC | +3.3 V |
| OLED | GND | GND |
| OLED | SDA | XIAO D4 |
| OLED | SCL | XIAO D5 |
| Encoder | A | XIAO **D1** (no external pull-up — firmware uses `INPUT_PULLUP`) |
| Encoder | B | XIAO **D2** (same — internal pull-up) |
| Encoder | Common | **GND** — required; without it, A and B float and the decoder sees no transitions |
| Encoder switch | One side | XIAO D7 (no external — internal pull-up) |
| Encoder switch | Other side | GND |

> **Encoder A/B history:** the bench encoder originally read CW as a *negative* delta with the schematic-natural A→D1, B→D2 wiring (caught 2026-05-02). The firmware was first patched to swap the constants (`PIN_ENC_A = D2`), but on 2026-05-04 the breadboard wires were physically swapped instead so the firmware and schematic agree on **A→D1, B→D2** (CW = positive). If a future encoder reads inverted, swap the constants in `src/main.cpp` and `src/main_smoketest.cpp` rather than re-routing the breadboard or PCB.
| Tempo pot | CW | **VREF rail** (4.096 V) — *not* +3.3 V; routes through MCP3208 |
| Tempo pot | Wiper | **MCP3208 pin 1 (CH0)** — *not* XIAO D0 (changed 2026-05-02; landed at CH0 per the 2026-05-03 channel-layout convention) |
| Tempo pot | CCW | GND |

**Why tempo on the MCP3208 instead of XIAO D0:** unifies all analog inputs through the precision REF3040 reference (one calibration story, no mixing of XIAO native ADC + external ADC), and frees D0 for J1 clock/gate edge detection. Cost: one extra SPI read per loop (microseconds — negligible). Pot CW must tie to **VREF**, not +5 V or +3.3 V, so the wiper's full sweep maps cleanly to the ADC's 0..VREF range without clipping.

See §3 for the policy on pull-ups (skipped on the bench, added on the PCB only for CS lines).

---

## 9. Jack assignments (per `decisions.md` §23: generic IN/OUT labels)

| Jack | Direction | Bench connection | App use (arp) |
|---|---|---|---|
| J1 | IN 1 | Input stage ch A → MCP3208 **CH1** | CV in / clock-trigger |
| J2 | IN 2 | Input stage ch B → MCP3208 **CH2** | CV in (transpose) / clock-trigger |

**MCP3208 channel layout** (per `decisions.md` §26): CH0 = pot, CH1 = J1, CH2 = J2, CH3–CH7 = expansion.
| J3 | OUT 1 | Output stage ch A ← DAC OUTA | V/Oct |
| J4 | OUT 2 | Output stage ch B ← DAC OUTB | Gate |

Loopback test convenience: jumper **J3 → J1** during smoke-test to verify DAC writes track ADC reads through the full signal chain.

---

## 10. Build order suggestion

Wire in this sequence — test at each step before moving on:

1. **Power distribution** — verify rails on multimeter (±12, +5, GND continuity)
2. **XIAO socketed + powered** — flash the `Blink` example via USB to confirm board is alive
3. **VREF stand-in (§5)** — wire pot + TL072 buffer, dial to 4.096 V on meter
4. **SPI bus + DAC8552 (§4 + §6)** — load `lib/outputs/`, run smoke test, scope OUTA for triangle wave
5. **MCP3208 (§4)** — load `lib/inputs/`, jumper DAC OUTA directly to any free MCP3208 channel (skip the input scaling stage), confirm count tracks DAC value
6. **Output stage (§6)** — insert TL072 + resistors between DAC and J3, confirm ±10 V swing at jack
7. **Input scaling (§7)** — wire jack J1 through input stage to MCP3208 **CH1**; bench-supply known voltages, confirm `inputs.readVolts()` is within tolerance
8. **OLED + encoder + tempo pot (§8)** — re-attach UI; verify menu navigation works on the new pin assignments
9. **Loopback** — jumper J3 → J1, run a sweep, confirm closed-loop accuracy

Each step has an entry in `bench-log.md` waiting for measurements + observations.

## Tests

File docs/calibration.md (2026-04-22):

# Calibration

Bench-measured constants and procedures for the gio module signal chain. Update on every recalibration; cross-reference each entry from `bench-log.md`.

---

## V/Oct output (Story 004) — 2026-04-22

### Circuit

PWM (D2) → 2-pole RC filter (2× 10 kΩ + 100 nF) → MCP6002 op-amp non-inverting amp → 100 Ω series → V/Oct out.

```
                              ┌──[Rf]──┐
                              │        │
filter ── pin 3 (+IN_A)       │        │
                              │        │
                pin 2 (−IN_A)─┤        │
                              │        │
                           [Rg = 10k]  │
                              │        │
                             GND       │
                                       │
                pin 1 (OUT_A) ─────────┴──[100 Ω, R4]── V/Oct out
```

| Component | Spec value | Built with | Notes |
|---|---|---|---|
| R_g (gain set, −IN to GND) | 10 kΩ | 1× 10 kΩ | 5 % carbon |
| R_f (feedback, OUT to −IN) | 2.7 kΩ | 2.2 kΩ + 470 Ω in series ≈ 2.67 kΩ | substitution; 2.7 kΩ unavailable |
| R4 (output) | 100 Ω | 1× 100 Ω | confirmed from RA4M1 lessons — 1 kΩ here causes 10–20¢/oct flat error against 100 kΩ Eurorack inputs |
| Decoupling | 100 nF | 1× 100 nF, leads short, across pins 8/4 | |
| Op-amp B (unused) | tied off | pin 5 → GND, pin 6 → pin 7 (grounded buffer) | prevents oscillation |

Nominal gain = 1 + R_f/R_g = 1 + 2.67/10 = **1.267**.

### Procedure

1. Flash firmware that steps through MIDI C3–C7 (notes 48, 60, 72, 84, 96), 2 s each, on D2 PWM.
2. Multimeter (DC volts) between V/Oct output (after R4) and GND. Record voltage at each step.
3. Linear-fit the (target, measured) pairs. Slope = (G_actual / G_firmware). Update firmware `GAIN` to `G_firmware × slope`.
4. Re-flash, re-measure, confirm errors within ±2 mV per step.
5. Plug into a known-good 1 V/oct VCO. Use a tuner app at each octave; record frequencies; compute per-octave cents error.

### Measured data

**Multimeter pass 1, GAIN = 1.27 (nominal):**

| MIDI | Note | Target V | Measured V | Residual |
|---|---|---|---|---|
| 48 | C3 | 0.000 | 0.001 | +1 mV |
| 60 | C4 | 1.000 | 0.989 | −11 mV |
| 72 | C5 | 2.000 | 1.981 | −19 mV |
| 84 | C6 | 3.000 | 2.974 | −26 mV |
| 96 | C7 | 4.000 | 3.967 | −33 mV |

Linear fit: slope 0.9917 V/oct, intercept −1 mV, residuals ±2 mV from line. Real gain = 1.27 × 0.9917 = **1.260**.

**Multimeter pass 2, GAIN = 1.26 (calibrated):**

| MIDI | Note | Target V | Measured V | Error |
|---|---|---|---|---|
| 48 | C3 | 0.000 | 0.001 | +1 mV |
| 60 | C4 | 1.000 | 0.998 | −2 mV |
| 72 | C5 | 2.000 | 1.998 | −2 mV |
| 84 | C6 | 3.000 | 2.998 | −2 mV |
| 96 | C7 | 4.000 | 3.999 | −1 mV |

Slope 0.9995 V/oct. **All steps within ±2 mV of target. ±2.4¢ max equivalent error — well within ±5¢ AC.**

**VCO + tuner end-to-end:**

| Note | Frequency (Hz) |
|---|---|
| C3 | 67.4 |
| C4 | 134.2 |
| C5 | 267.8 |
| C6 | 536.5 |
| C7 | 1072.0 |

Per-octave interval errors: −7.7¢, −3.9¢, +2.9¢, −1.7¢. Best-fit line residuals all within ±4¢. The C3→C4 outlier is consistent with tuner-app imprecision at 67 Hz (1 Hz of measurement noise = 13¢ at this pitch). The DAC/op-amp side is independently verified to ±2.4¢ via the multimeter pass above; the slight excess slope error (~1.2¢/oct beyond DAC) is attributed to the VCO's own tracking.

### Firmware constants

```cpp
// firmware/arp/src/main.cpp
static const float    GAIN  = 1.26f;   // measured 2026-04-22; update after recal
static const float    VREF  = 3.3f;
static const uint16_t PWM_MAX = 4095;
// MIDI root: C3 (note 48) = 0.000 V; +1 V per octave thereafter.
```

Re-run the multimeter procedure if any of: MCP6002 swapped, R_f/R_g changed, supply rail moved off 5.0 V, ambient temperature shifts >10 °C from bench day.

---

## CV input divider (deferred)

Decisions.md §8 specifies 100 kΩ series + 68 kΩ to GND + BAT54 dual Schottky for both J1 (A3/GP29) and J2 (A1/GP27). Maps 0–8 V V/Oct → 0–3.24 V at ADC (~42 counts/semitone). Bench-verification deferred to the first story that consumes CV input — no story currently in the backlog uses CV in.

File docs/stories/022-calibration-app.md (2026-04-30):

# Story 022: Calibration app

**As a** module owner with a freshly assembled Rev 0.1 PCB
**I want** a dedicated calibration app that fits per-channel gain/offset constants and writes them to EEPROM
**So that** the production firmware produces musically accurate jack-side voltages without me ever opening a terminal

## Sequencing

This story is sequenced **after Rev 0.1 PCB manufacture and bring-up**. Calibrating against the breadboard buys nothing — we want to characterise the real silicon, real PCB-trace impedances, real assembled op-amp + resistor tolerances, real REF3040 (not the pot+TL072 stand-in). Until this story ships, the production firmware uses hardcoded calibration constants from bench measurements (musically usable, not lab-grade).

Architectural decisions are captured in `docs/decisions.md` §27 — read that first.

**Hard dependencies:**
- Story 018 (platform skeleton + app switcher) must be done — this story plugs into the App interface
- Story 018 must already reserve the §27 EEPROM layout including the calibration block (so this story doesn't have to migrate existing storage)
- Rev 0.1 PCB must be assembled and bench-verified — no point calibrating against the breadboard

## Acceptance Criteria

### App registration

- [ ] New `firmware/arp/lib/apps/calibrate/` matching the `App` interface from Story 018
- [ ] `name` field set to `"Calibrate"` (visible in app switcher)
- [ ] Registered in the `APPS[]` array in `main.cpp`

### Auto-trigger on missing data

- [ ] Boot logic in `main.cpp` reads the EEPROM calibration block on startup
- [ ] If magic byte ≠ `'GIO!'`, layout version mismatches, or CRC32 fails:
  - Log to serial (`"calibration missing/invalid; entering calibration app"`)
  - Override the "last loaded app" and load the calibrate app instead
  - After successful calibration, the next boot loads the user's actual chosen app
- [ ] Hardcoded firmware-default calibration is loaded into the HALs as a fallback so the app's own analog stages still work during the calibration ritual itself (chicken-and-egg avoidance)

### Calibration UI flow

- [ ] **Welcome screen** — OLED shows "Calibrate? CLICK = yes / LONG = cancel". User can back out.
- [ ] **Step 1: Patch prompt** — OLED shows "Patch J3 → J1, then click". Wait for click.
  - On click, run channel-A loopback sweep (next step). 
  - On long-press, abort (return to app switcher; calibration not written).
- [ ] **Step 2: Channel-A sweep** — DAC8552 ch A writes 5 evenly-spaced voltages within the safe range (e.g., 0.4 V, 1.2 V, 2.0 V, 2.8 V, 3.6 V — avoiding the rails). At each point, hold for 100 ms (settling), read MCP3208 ch 0 (averaging 16 samples for noise reduction), capture the (DAC volts, ADC volts) pair.
- [ ] **Step 3: Fit channel A** — least-squares linear regression on the 5 data points. Compute output gain/offset and input gain/offset per the §27 math (REF3040 trusted; DAC ideal; cascaded error attributed to the input stage).
- [ ] **Step 4: Patch prompt for channel B** — "Patch J4 → J2, then click". Same loopback sequence on channel B.
- [ ] **Step 5: Sanity check** — verify all 4 fitted constants are within reasonable bounds (e.g., gain in [0.5, 2.0] of nominal; offset in [-VREF/2, +VREF/2]). If any are out of range, show "Calibration failed — check patch cable" and don't write to EEPROM.
- [ ] **Step 6: Confirm + write** — show summary on OLED ("4 channels calibrated. Save?"). Click writes to EEPROM with magic + version + CRC; long-press cancels.
- [ ] **Step 7: Return to app switcher** — automatic after successful write.

### EEPROM I/O

- [ ] Read on boot: validate magic + version + CRC, load calibration into HALs
- [ ] Write on completion: pack 4× (gain + offset) floats per the §27 layout, compute CRC, write magic + version, commit
- [ ] Use arduino-pico's `EEPROM.h` (last 4 KB sector of flash; survives normal `picotool` re-flash)

### Bench verification

- [ ] Fresh module (no calibration in EEPROM) → boot → calibrate app auto-launches
- [ ] Walk through full sequence with patch cables; verify fitted constants are stable across two consecutive runs (within ±1 % of each other)
- [ ] After successful calibration, power-cycle → calibrate app does NOT re-launch; user's chosen app loads
- [ ] In the user's chosen app (e.g. arp), confirm V/Oct accuracy at jack J3 against an external multimeter — should be within ±5 cents per octave across C0–C7
- [ ] Re-trigger calibration via app switcher, complete it again, verify boot behavior still correct

### Host tests

- [ ] Linear-fit math has unit tests with synthetic data (perfect line + line + noise)
- [ ] CRC32 round-trip test
- [ ] Storage-format pack/unpack round-trip test

## Notes

- **Why 5 sweep points, not more or fewer:** 2 points minimum for a linear fit; 5 gives noise rejection without noticeably extending the calibration time. Each point needs ~100 ms settling + 16 ADC averages × ~50 µs = ~10 ms — total per channel ~600 ms. Both channels = ~1.2 s of sweep time. Add UI prompts and the whole calibration ritual is < 30 seconds.
- **Why avoid the rails in the sweep:** the output stage's swing isn't perfectly symmetric near ±10 V (op-amp output saturates a few hundred mV before the rails). Sweep points at 0.4 V and 3.6 V correspond to about ±7 V at the jack, comfortably linear.
- **What if the user doesn't have a patch cable handy:** they can long-press to abort. The hardcoded firmware-default calibration stays in effect (musically usable). Re-run via app switcher when they have a cable.
- **Why no held-button-at-boot recovery:** if the app switcher itself is broken, USB re-flash recovers everything. Adding a held-button recovery path costs code complexity for a vanishingly rare scenario. (See §27.)
- **Future extensions** (NOT v1):
  - REF3040 verification via test-point pad on the back of the PCB
  - Multimeter-anchored output calibration (for users who need lab-grade external V/Oct)
  - Periodic re-calibration prompts (currently rejected — hardware doesn't drift)
  - Per-app calibration profiles (e.g., "calibrate for PWM-style square outputs vs. clean V/Oct") — overengineered for v1

## Depends on

- Story 018 (platform skeleton, app switcher, EEPROM layout reservation)
- Rev 0.1 PCB manufactured + assembled + bench-verified

## Status

deferred — design captured (decisions.md §27), implementation gated on PCB build

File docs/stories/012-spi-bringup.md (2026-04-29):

# Story 012: SPI Bring-up — DAC8552 + MCP3208 on Shared Bus

**As a** bench engineer
**I want** the XIAO RP2350 to talk to both the DAC8552 (16-bit dual SPI DAC) and the MCP3208 (8-channel SPI ADC) on a shared SPI bus
**So that** every subsequent story has a working write-output / read-input primitive to build on

## Pin map (confirmed pre-bench)

Verified from the arduino-pico variant header for `seeed_xiao_rp2350`:

| Function | XIAO pin | RP2350 GPIO | Notes |
|---|---|---|---|
| SPI SCK | D8 | GP2 | `PIN_SPI0_SCK` |
| SPI MISO | D9 | GP4 | `PIN_SPI0_MISO` |
| SPI MOSI | D10 | GP3 | `PIN_SPI0_MOSI` |
| CS — DAC8552 | D3 | GP5 | `PIN_SPI0_SS` (default Arduino SS pin) |
| CS — MCP3208 | D6 | GP0 | Any GPIO works for CS |

All four SPI signal pins are on SPI0's hardware default set, so `SPI.begin()` works without `SPI.setSCK/setTX/setRX`.

**Encoder pin migration (consequence of taking D8/D9/D10 for SPI):**

| Function | v0.3.0 pin | Rev 0.1 pin |
|---|---|---|
| Encoder A | D8 (GP2) | A1 (GP27) |
| Encoder B | D9 (GP3) | A2 (GP28) |
| Encoder click | D10 (GP4) | D7 (GP1) |

mathertel/RotaryEncoder is polling-based, so this is a pure wiring change — only pin `#define`s in `main.cpp` change.

## Library decision (pre-bench)

Use existing well-tested Arduino libraries instead of rolling our own SPI frame packers:

- **`robtillaart/DAC8552`** (MIT, v0.5.2) — bench-validated by user in `~/Git/Electronics/eurorack/dac8852-test/`. API: `DAC8552 dac(CS_PIN); dac.begin(); dac.setValue(channel, uint16_value);`
- **`robtillaart/MCP_ADC`** (MIT) — covers MCP3001/3002/3004/3008/3201/3202/3204/**3208**. API: `MCP3208 adc; adc.begin(CS_PIN); int v = adc.analogRead(channel);`

This means our `lib/spi_bus/` doesn't exist; instead `lib/outputs/` and `lib/inputs/` wrap these libraries with the calibration math and HAL interface.

## Acceptance Criteria

### Hardware

- [ ] DAC8552 on hand-soldered protoboard (already done — confirmed 2026-04-23).
- [ ] MCP3208 in DIP-16 directly on the breadboard.
- [ ] Shared SPI0 bus wired per pin map above:
  - SCK (D8) → both ICs' clock pins
  - MOSI (D10) → MCP3208 DIN, DAC8552 DIN
  - MISO (D9) → MCP3208 DOUT (DAC8552 has no MISO)
  - CS_DAC (D3) → DAC8552 /SYNC
  - CS_ADC (D6) → MCP3208 /CS
- [ ] CS lines pulled high by 10 kΩ to +3.3V at boot (so ICs idle deselected).
- [ ] **VREF: 4.096 V from REF3040** (LCSC C19415, TI, SOT-23) — fed from +5V supply, output tied to both DAC8552 VREF and MCP3208 VREF. **Not** tied to VDD. Per `decisions.md` §25.
  - Resolution: DAC = 4.096 V / 65536 = **62.5 µV/step**; ADC = 4.096 V / 4096 = **exactly 1.00 mV/step**
  - Both VREF pins share the REF3040 output node with a 100 nF + 1 µF decoupling pair right at the REF3040 output
- [ ] Decoupling: 100 nF on each IC's VDD; 100 nF + 1 µF on the REF3040 output (shared VREF node).

### Firmware

- [ ] Add libraries to `firmware/arp/platformio.ini`:
  ```
  lib_deps =
      robtillaart/DAC8552
      robtillaart/MCP_ADC
  ```
- [ ] New `firmware/arp/lib/outputs/` HAL wrapper:
  - `outputs::write(channel, volts)` — apply per-channel gain/offset, call `dac.setValue()`
  - `outputs::gate(channel, on)` — convenience wrapper around `write(channel, on ? 5.0f : 0.0f)`
- [ ] New `firmware/arp/lib/inputs/` HAL wrapper:
  - `inputs::readVolts(channel)` — call `adc.analogRead()`, apply per-channel gain/offset, return jack-side volts
  - `inputs::readRaw(channel)` — passthrough for diagnostics
- [ ] Smoke test in a temporary `main.cpp`: write a triangle on DAC ch A (0 → 65535 → 0 over 1 s); read MCP3208 ch 0 (jumpered directly to DAC OUTA); print both to serial; confirm ADC tracks DAC roughly linearly.

### Bench

- [ ] Loopback test: jumper DAC OUTA → MCP3208 ch 0; OUTB → ch 1. Sweep each DAC channel; verify each ADC channel tracks.
- [ ] Verify all 8 MCP3208 channels read independently — short each in turn to GND, confirm only that channel reads ~0.
- [ ] Scope SCK during a transaction; verify clock rate. Start at 1 MHz, push to 2 MHz max for the MCP3208 (datasheet limit at VDD=5 V — DS21298E p.3). DAC8552 tolerates up to 30 MHz, so the ADC is the bus-speed bottleneck.
- [ ] Confirm both CS lines toggle independently (scope both during back-to-back transactions).

## Notes

- **DAC8552 datasheet quirk:** 24-bit serial frame = 8 control + 16 data. Rob Tillaart's library handles all of this — `setValue(channel, value)` is the whole API surface needed.
- **MCP3208 quirk:** start bit + single/diff + 3 channel bits + null + 12 data. Rob Tillaart's `MCP_ADC` library handles it.
- **Why both libraries from the same author:** consistency in API style, both MIT-licensed, both actively maintained, both already platform-resolved.
- **VREF = 4.096 V (not 5 V):** decided in `decisions.md` §25. The 16-bit DAC is wasted resolution if the reference is a 1–2 % LDO output. REF3040 (±0.2%, 75 ppm/°C) gives clean LSB math (62.5 µV / 1.00 mV) and the standard precision-reference value. The DAC's max output is now 4.096 V instead of 5 V; the output stage's gain is bumped to ≈ 4.88 (from 4) to still hit ±10 V at the jack — see Story 013.
- **Why pre-pull `outputs` / `inputs` HAL into Story 012:** keeps the smoke test from needing to know about the underlying libraries; later stories (013, 015) just deepen the calibration math behind the same interface.

## Depends on

- Story 011 (Protomato rails verified)

## Status

prep complete (pin map confirmed, library choice locked, encoder migration documented). Bench session pending parts arrival (MCP3208 ordered, OLED en route).

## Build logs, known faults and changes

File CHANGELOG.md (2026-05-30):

# Changelog

All notable changes to this project are documented in this file.

The format is based on [Keep a Changelog](https://keepachangelog.com/en/1.1.0/), and firmware in this repo follows [Semantic Versioning](https://semver.org/spec/v2.0.0.html). Hardware uses `Rev N.M` notation, silkscreened on the PCB. See `docs/decisions.md` §13 for the full scheme.

**Convention:** this file is updated on every commit. Changes in-flight go under `## [Unreleased]`; on a firmware tag (`arp/vX.Y.Z`), those entries move under a new `## [arp/vX.Y.Z] — YYYY-MM-DD` heading.

Section keys: `Added`, `Changed`, `Deprecated`, `Removed`, `Fixed`, `Security`, `Docs`.

---

## [Unreleased]

### Fixed

- **OLED on `Wire1`, not `Wire` (arduino-pico 5.6.0 default pin remap on XIAO RP2350).** `firmware/arp/lib/oled_ui/oled_ui.h` now instantiates `Adafruit_SSD1306 display_{… &Wire1, -1}` instead of `&Wire`. **Why:** arduino-pico 5.6.0 changed the seeed_xiao_rp2350 variant's default Wire (Wire0) pin mapping from `GP6/GP7` (= `D4/D5`, where the gio board's OLED is wired) to `GP16/GP17` (unused on the gio board). GP6/GP7 are now `PIN_WIRE1_SDA/SCL`, so the OLED lives on `Wire1` and `Wire1`'s defaults match the gio wiring (no `setSDA`/`setSCL` remap needed). Symptom before the fix: `ui.begin()` reported `ready=true` (Adafruit_SSD1306 doesn't actually round-trip an I²C ACK during begin), but the OLED never displayed anything — the library was writing to a peripheral with nothing on its bus. Full chase in `bench-log.md` 2026-05-23 entry.
- **arduino-pico framework upgraded `4.4.0` → `5.6.0` in `firmware/arp/platformio.ini`.** Mid-session, builds against the pinned 4.4.0 began producing UF2s that don't boot on stock XIAO RP2350 boards (USB CDC never enumerates, no serial output, OLED dark — completely silent fail). Old 4.4.0 builds already on boards still worked; *new* builds from the same source did not. Root cause never pinned down — likely a transitive dependency drift somewhere in the PlatformIO/platform-raspberrypi/picotool chain since `platform = …main` is unpinned. Upgrading the framework pin to 5.6.0 restored bootable UF2 output. **Followup pending:** pin `platform = …#<commit>` and `platform_packages` for picotool to specific known-good versions so this can't happen silently again.

### Changed

- **Canonical jack roles locked in: J1=Clock in, J2=CV in (V/oct transpose), J3=CV out (V/oct), J4=Trigger out.** Removes the dual-purpose ambiguity on J1 (was CV-transpose OR clock depending on mode — silently broken in EXT because the CV reader was sampling clock pulses as voltage). `readCvVolts()` in `firmware/arp/src/main.cpp` now reads `ADC_CH_CV_IN` (CH2 / J2) instead of CH1; CH2 calibration is set with the same constants as CH1 as a first pass (input op-amp stages are symmetric per bench-log 2026-05-21 — refine if V/oct tracking drifts). Constants renamed for clarity: `ADC_CH_CV_IN_1` → `ADC_CH_CLOCK_IN`, `ADC_CH_CV_IN_2` → `ADC_CH_CV_IN`. CV transpose is now active in BOTH INT and EXT clock modes (previously only worked in INT because of the channel conflict). File-header prose and setup() Serial banner updated to lock in the role table.

### Added

- **`hardware/gio-stacked/` — scaffolding for a 3-board stacked redesign.** New project directory captures the architecture for a 4 HP module split into three depth-stacked PCBs (power / signal / faceplate) connected by 2.54 mm pin headers. Driven by the expanded feature set (6 jacks, tap-tempo button, same OLED + pot + encoder) that doesn't fit on a single 4 HP PCB. Inter-board pinouts, faceplate component placement, mechanical stackup (M2.5 standoffs, ~40 mm total depth — at the Eurorack limit), and design decisions are all documented under `docs/` before any KiCad work begins. Reuses the validated MCU + DAC + ADC + op-amp stack from `hardware/gio/`; CV ins expand to 4 via MCP3208 CH3 + CH4 (same scaling stage replicated), tap button goes on XIAO D0 (freed when the pot moved to MCP3208 CH0).

### Fixed

- **Top-octave clamp collapsed multiple notes onto C7 at high OCT + high keyPC.** `MIDI_NOTE_MAX` in `firmware/arp/src/main.cpp` was 96 (C7); at OCT=4 the chord buffer's top interval is +48 semitones and `keyMidi + interval` reaches 107 with keyPC=B — everything 96..107 was clamping to 96, so the top 3–11 played values all came out as C7. Raised the ceiling to 120 (C9), giving 2 octaves of headroom. Hardware stays well inside spec: midi 120 → +6 V at J3 vs the +8.79 V output-stage limit. CV transpose can still push past in extreme combos (`keyPC=B + OCT=4 + ~+1 V CV`) — accepted; the failure mode there is the original "top notes squash" behavior, just pushed an octave higher.

### Added

- **`OCT` encoder param (1..4) extends the arp pattern across N octaves.** New `Param::Octave` in `firmware/arp/src/main.cpp` rebuilds the arp's interval list by stacking `CHORD_INTERVALS` across `octRange` octaves; consecutive duplicates are skipped so the C-to-C boundary doesn't double-strike when stacking the default `{0,4,7,12}` triad shape (OCT=2 yields `{0,4,7,12,16,19,24}`, not `{0,4,7,12,12,16,19,24}`). Defaults to 1 — same audible behavior as before for existing users. NeoPixel orange when active. Static `chordBuf[CHORD_LEN * OCT_MAX]` (16 bytes) holds the expanded list so we don't allocate. `rebuildChord()` is called on encoder change and once at boot — same path for all values, no special-case for OCT=1.

- **Arp pattern auto-resets after `EXT_CLOCK_RESET_MS` (default 2 s) of clock silence in EXT mode.** When an external-clock edge arrives after a gap longer than this from the previous edge, `arp.reset()` runs (next note = note 1 of the chord/order) and the returning pulse is treated as a fresh first pulse (`extPrevEdgeMs`/`extStepsRemaining`/`extInterpolatedInterval` cleared so the stale period doesn't trigger an interpolation burst). The 2 s value is arbitrary — exposed as a named constant in `firmware/arp/src/main.cpp` so it can be promoted to an encoder param or `CLOCK` sub-setting later. Serial logs `clock idle >2000ms — arp reset` when triggered. **Why:** stopping a clock source and resuming should feel like "start the phrase over," not "resume mid-pattern from wherever I left off."

### Changed

- **Clock source is now an explicit `CLOCK` encoder param (`EXT`/`INT`), no auto-fallback.** Replaces the 2 s edge-timeout auto-detect in `firmware/arp/src/main.cpp` — `externalClockActive()`, `EXT_CLOCK_TIMEOUT_MS`, and the `wasExtModeLast` transition handler are removed. **`EXT` is the boot default**, so the arp now sits silent until a clock cable arrives on J1; flipping to `INT` runs strictly from the tempo pot and `pollExternalClockEdge()` is no longer called at all (J1 signals are fully ignored). The encoder handler resets all `ext*` latches on the `INT → EXT` transition so a stale `extClockHigh = true` from before can't swallow the first incoming edge. Top-right OLED badge now mirrors the user's selection rather than the auto-detected state; NeoPixel shows cyan when `CLOCK` is the active param (distinct from the existing four). **Why:** the auto-switch was nondeterministic at edge cases (drop-outs near the 2 s threshold flapped INT/EXT) and made the module's state harder to reason about; explicit selection is predictable.

- **Toolchain fully pinned to stop the silent-boot drift.** `firmware/arp/platformio.ini` now pins the platform to an exact commit (`…#79ce473…` = platform-raspberrypi 1.19.0+sha.79ce473) and the framework to `#5.6.0` (which transitively pins the matching `picotool`/`openocd`/`pioasm` tools). Both verified to build **and boot** before committing. Background: the 2026-05-23 non-bootable-UF2 failure (USB never enumerates, OLED dark, ~hours + a desoldered XIAO to diagnose) was toolchain drift — the `platform` line tracked a bare branch head and the framework pin (then 4.4.0) had gone stale. (A first fix attempt pinned a *tag* that didn't exist and broke the build; it was reverted, then the real working commit was captured from the build's own version string + `git ls-remote` and pinned by SHA. Lesson, now written into the platformio.ini comment: verify any pin BUILDS AND BOOTS before committing.)
- **`OLED_ROTATION` reverted to `0` (native landscape)** for board #2's OLED orientation. The rev 1 PCB OLED footprint bug is per-board: board #1 needed a 180° physical flip and `OLED_ROTATION = 2`; board #2 happens to land at `ROTATION = 0` for the way its OLED was installed. **Rev 2 to-do**: fix the OLED footprint in KiCad so all boards work with a single canonical rotation (probably `1` = 90° CW portrait, the original design intent). Affects both production and smoke-test builds (shared header).
- **`firmware/arp/src/main.cpp` setup() reordered** — `Serial.begin()` now runs *before* `Wire.begin()` / `SPI.begin()` / any peripheral init. Previous ordering hid early-setup hangs behind silent USB CDC (no print output ever flushed), which made the 2026-05-23 toolchain regression several hours harder to isolate than it needed to be. Side effect: `Serial.println("BOOT N: <step>")` diagnostics added between every begin() call, plus a 1 Hz `LOOP heartbeat t=<ms>  ui.ready=<0|1>` print in loop(), so any future setup() hang is immediately diagnosable from a serial capture alone. **TEMP**: marked as diagnostic in the comments; consider keeping permanently under a `#ifdef DEBUG_BOOT` once we trust the rebuild path.

### Added

- **External clock-in on Input A (J1 / MCP3208 CH1).** `pollExternalClockEdge()` in `src/main.cpp` was a stub returning `false` (external clock was never implemented). It now reads Input A through a Schmitt trigger (assert < 1.50 V / re-arm > 1.75 V — the input stage is inverting, so a +5 V clock pulse reads ~1.06 V) and stamps `extLastEdgeMs` on each rising edge. That timestamp is what `externalClockActive()` keys off, so feeding a clock auto-switches the arp INT→EXT (OLED badge flips) and advances one step per pulse; the tempo pot becomes a ×1/×2/×4 clock multiplier in EXT mode. Falls back to internal tempo 2 s after the clock stops. Bench-verified clean 1:1 detection, zero jitter. (Two stacked bugs: the stub never detected edges, and the first detection pass detected edges but never stamped `extLastEdgeMs`, so the mode never flipped.) Also: screen bitmaps resized 32×64 → 64×32 to fit the `ROTATION=0` landscape canvas (stretched; `sharp` overlay kept 8×8), and the temporary 2026-05-23 boot-trace + 1 Hz heartbeat diagnostics were removed (Serial-first ordering kept).
- **`firmware/arp/src/main_minimal.cpp` + `env:seeed-xiao-rp2350-minimal`** — a deliberate "absolute minimum sketch" build with no libraries, no peripherals, no SPI/Wire, just `Serial.begin()` + a `Serial.println("alive t=N")` loop. Built during the 2026-05-23 toolchain regression chase to isolate "is it our code or the build environment?" Kept around as a permanent recovery / sanity-check tool: if this env's UF2 doesn't boot, the rest of the firmware certainly won't and the problem isn't our code. Build: `pio run -d firmware/arp -e seeed-xiao-rp2350-minimal --target upload`.

### Docs

- **`docs/bench-log.md` 2026-05-21 entry — full electrical bring-up of the manufactured rev 1 board.** Captures: per-subsystem validation (XIAO + USB + Eurorack +5 V, SPI bus, DAC8552, MCP3208, REF3040, both input op-amp stages, both output op-amp stages, tempo pot, encoder rotation + click + long-press, OLED post-rework); the OLED footprint bug + 180° rework + `OLED_ROTATION=2` firmware bodge; the 2×2 patch matrix (Input A/B × Output A/B loopback); a productive false-alarm chase through the input op-amp transfer function (the apparent "−1.8 V output DC offset" was a missing 1.18× bias multiplier — `V_adc = (1 + R_fb/R_in_eq)·V_bias − (R_fb/R_in_eq)·V_jack`, not the simpler form I was treating it as); multimeter measurements confirming all four bias dividers are at design 1.66 V; and the rev 2 PCB to-do list. **Conclusion: the board is electrically fully validated, no PCB rework needed beyond the OLED flip.** Lesson added to the troubleshooting playbook: cross-check apparent DC offsets at an ADC channel against the floating reading before chasing a divider hypothesis.

### Added

- **Output op-amp stage (U5) generated into `hardware/gio-opamp/gio-opamp.kicad_sch`** via Python script (`tools/gen-output-stage.py`). The script translates the input op-amp section by +100 in Y and remaps references / values / net labels to the output topology. Adds: U5 (TL072 with 3 unit instances), R13–R22 (R_fb 47k ×2, R_jack_series 1k ×2, R_off_top 22k ×2, R_off_bot 14.7k ×2, R_in 10k ×2), C6–C10 (5× 100 nF for decoupling + bias filtering), D3/D4 (BAT54S output clamps), J3/J4 (PJ3001F output jacks), and 12 new power flags (#PWR022–#PWR033). Net labels: `dac_a`/`dac_b` (DAC inputs to R_in) and `out_a`/`out_b` (jack outputs after R_jack_series). **Generated by Claude — needs visual verification in KiCad.** Pin geometries empirically derived from the existing input stage's wire endpoints; UUIDs all freshly generated; paren balance verified; no duplicate UUIDs or designator collisions.
- **`hardware/gio-opamp/` — first KiCad project for Rev 0.1 PCB**, focused on the input scaling stage. Schematic implements the full §7 design that was bench-validated across the 2026-04-29 → 2026-05-03 sessions: per-channel offset divider (R5/R8 + R6/R7 = 22 k / 14.7 k → ~1.66 V bias), 22 k feedback (R1/R2), 22 k input resistor (R10/R11), 100 k series-protection resistor before the clamp node (R9/R12), BAT54S series-pair Schottky clamps to ±12 V, and 1 k output isolation (R3/R4) feeding adc_ch1 / adc_ch2. Power decoupling: bulk 100 nF on each rail at the chip (C1/C2), local 100 nF directly across U1 V+/V− (C5), and 100 nF filter caps on each bias-divider node (C3/C4). Schematic only — PCB layout deferred until all subsystems are captured.
- **Input-stage schematic refinements** (2026-05-03 review-driven updates): `input tip a/b` net renamed to `clamp_a/clamp_b` (more accurate — it's the protection node *after* R_series); local 100 nF decoupling across U1 V+/V−; per-channel 100 nF filter caps on each bias-divider node; Schottky clamps switched to BAT54S 3-pin series-pair symbol (one part replaces two BAT43s per channel for the production PCB).
- **`tools/bench-read.py` — reusable Python bench script** for reading the smoke-test firmware's tab-separated serial stream and summarizing channel min/max/range/last per labeled column. Auto-discovers `/dev/cu.usbmodem*`, parses the `# t_ms ...` header line, and falls back to the known smoke-test column names if the header was printed before the script connected. Replaces the inline `python3 -c "..."` blocks scattered through the bench transcripts. Usage: `python3 tools/bench-read.py [--seconds N] [--port PATH] [--rows N]`.

### Changed

- **REF3040 voltage reference replaces the pot+TL072 VREF stand-in on the bench** (`bench-log.md` 2026-05-04 continued entry). VREF stability improved from **±56 mV** (pot+TL072 drift across a 4 s window) to **±2 mV** — a 28× improvement, essentially down to MCP3208 LSB quantization. Wiring per `bench-wiring.md` §5: REF3040 pin 1 (VIN) → +5 V, pin 2 (GND) → GND, pin 3 (VOUT) → VREF rail; 100 nF on VIN, 1 µF on VOUT (required for stability). TL072 #1 also pulled — REF3040's 25 mA output drives the ~1 mA total load directly. Bench now matches the production PCB topology for VREF. Existing calibration constants in `main.cpp` may shift slightly (well under 0.1 %, ratiometric system) and will be re-fit next calibration pass.
- **Bench platform fully revalidated end-to-end on the schematic-aligned layout** (`bench-log.md` 2026-05-04 entry). After rebuilding the breadboard's input scaling stage to match the KiCad schematic 1:1, both input channels (J1 and J2) and both output channels (J5 and J6) were validated via direct tip-to-tip jumper loopbacks: `j1_v` and `j2_v` each track the DAC triangle from 0.35 → 3.58 V at 1 Hz with errors under 30 mV across the full ±9 V swing. The pot on MCP3208 CH0, the encoder (now with A→D1/B→D2 natural wiring matching the schematic), and the OLED are all live. **The schematic is now a high-confidence PCB target** — every connection has been physically verified. Caught and documented one wiring failure mode along the way: the input chain was originally landed on op-amp pin 1 (output) instead of pin 2 (inverting input), producing a 4× gain error that mimicked the same symptom as a wrong R_fb value — now in the troubleshooting playbook.
- **Jack naming convention adopted from the KiCad schematic going forward**: J1 = Input A, J2 = Input B, J5 = Output A, J6 = Output B. (J3/J4 were used during early schematic iterations and KiCad's auto-annotation didn't reuse them.) All future docs and bench transcripts use these names.
- **Encoder A/B firmware swap reverted** (`PIN_ENC_A = D1`, `PIN_ENC_B = D2`) in both `src/main.cpp` and `src/main_smoketest.cpp` to align with the KiCad schematic's natural assignment. The 2026-05-02 firmware-side swap was a workaround for the bench encoder reading CW as a negative delta with the original wiring. On 2026-05-04 the breadboard wires were physically swapped to match the schematic, so firmware can now use the schematic-natural pin assignment. CW still reads positive — same observable behavior, just the responsibility for the swap moved from firmware to the breadboard. Convention now: encoder pin A → XIAO D1, encoder pin B → XIAO D2, common → GND. `bench-wiring.md` §3 + §8 + the encoder note all updated to agree. Build still 2.2 % RAM / 4.6 % flash; 66 host tests pass.
- **`.gitignore` extended for KiCad cruft** — `~*.lck` (KiCad project/schematic lock files when the editor is open) and `.history/` (KiCad's local-history snapshot directory) added so they don't pollute commits.
- **MCP3208 channel layout settled** (decisions.md §26 updated). Convention: **CH0 = primary pot** (tempo today), **CH1 = J1**, **CH2 = J2**, **CH3–CH7 = expansion / I/O daughterboard**. Internal controls at low channels; jacks contiguous after; expansion at high channels — clean rule for any future pot/jack/button. Wiring updates: pot wiper to MCP3208 pin 1 (was pin 2); J1 op-amp output to pin 2 (was pin 1); J2 op-amp output (when wired) to pin 3. Firmware constants renamed `ADC_CH_TEMPO` → `ADC_CH_POT`, `ADC_CH_CV_IN` → `ADC_CH_CV_IN_1`, added `ADC_CH_CV_IN_2`. Calibration now applies to CH1 (J1) instead of CH0 (which is now the pot — no calibration needed; raw 0..VREF). Smoke test serial header is now `t_ms  dac_a_v  dac_b_v  pot_v  pot_count  j1_v  j1_count  j2_v  j2_count  enc_count  click  long`. `bench-wiring.md` §3, §7, §8, §9 updated. Production firmware builds at 2.2 % RAM / 4.6 % flash; smoke test builds; all 66 host tests pass.
- **`EncoderInput` switched from polled-only to interrupt-driven decoding.** Both quadrature pins (A and B) now have CHANGE ISRs attached that call `RotaryEncoder::tick()` the moment a transition occurs, so the state machine never misses a detent regardless of how busy the main loop is (OLED I²C bursts, SPI transactions, serial prints can all stall the loop for tens of ms with no impact on encoder accuracy). `poll()` still calls `tick()` as belt-and-suspenders. Caught at the bench when fast rotations dropped detents in the smoke test (the loop's ~50 Hz polling rate plus ~5 ms of OLED I²C transmission per refresh was eating transitions). After the change, an 8-second fast-rotation test caught all 21 detents (22 unique counts seen). No firmware-side calling-code changes — `g_encoder.poll()` still works identically.
- **Smoke-test firmware initializes and drives the OLED.** Boot probes for an SSD1306 at I²C `0x3C` and prints "OLED: detected" or "NOT detected" to serial; if detected, splash "gio" briefly then refresh "ENC = N" at 10 Hz reflecting the live encoder count. Lets the bench rig validate the OLED end-to-end without flashing the production firmware.
- **Encoder A/B swapped in firmware** (`PIN_ENC_A = D2`, `PIN_ENC_B = D1`) in both `src/main.cpp` and `src/main_smoketest.cpp`. The bench encoder reads CW as a negative delta when wired with the original A→D1, B→D2 assignment; flipping the firmware constants is cleaner than fighting the breadboard. Convention is now: encoder pin A → XIAO D2, encoder pin B → XIAO D1, common → GND. Bench-validated: CW = positive count, CCW = negative count.
- **Smoke-test firmware streams encoder columns** (`enc_count  click  long`) alongside the existing DAC/ADC/tempo columns. Output line is now `t_ms  dac_a_v  dac_b_v  adc_v  adc_count  tempo_v  tempo_count  enc_count  click  long`. Lets the bench rig validate the encoder + click + long-press paths without re-flashing a one-shot test. Internal pull-ups (`INPUT_PULLUP`) handle idle state — no external resistors needed.
- **Tempo pot relocated from XIAO D0 onto MCP3208 CH1.** All analog inputs now share the precision REF3040 reference (uniform calibration story, no mixing of XIAO native ADC with external ADC). Frees D0 for J1 clock/gate digital edge detection. Hardware change: pot CW now ties to the **VREF rail** instead of +3.3 V; wiper goes to MCP3208 pin 2; pot CCW unchanged at GND. Firmware change: `PIN_TEMPO` constant removed from `src/main.cpp`; 3× `analogRead(PIN_TEMPO)` calls replaced with `inputs::readRaw(ADC_CH_TEMPO)` where `ADC_CH_TEMPO = 1`. J2 CV input (when wired) moves from MCP3208 CH1 → CH2. Updated `bench-wiring.md` §3, §8, §9 and `decisions.md` §26 pin-budget table. Build still 2.2 % RAM / 4.6 % flash; all 66 host tests pass.
- **Production firmware migrated to the SPI HAL.** `src/main.cpp` no longer drives the PWM-DAC + analog-CV + digital-gate paths; instead it uses `outputs::write()` (V/Oct on jack J3 via DAC ch A), `outputs::gate()` (gate on jack J4 via DAC ch B), and `inputs::readVolts()` (CV transpose in on jack J1). Pin migration: encoder moved D8/D9/D10 → D1/D2/D7 to free SPI pins; CS_DAC=D3, CS_ADC=D6, SPI bus on D8/D9/D10 (per `bench-wiring.md` §3). Production firmware builds at 2.2 % RAM / 4.6 % flash; smoke-test env still builds; all 66 host tests pass.
- **Hardcoded calibration constants from the 2026-04-30 bench session** baked into `setup()` via `outputs::setCalibration()` and `inputs::setCalibration()` calls — musical-grade approximations for the breadboard prototype, slated for replacement by Story 022 (calibration app) once Rev 0.1 PCB is in hand.
- **External clock detection (Story 010) is dormant** — `pollExternalClockEdge()` always returns false until input ch B (jack J2) scaling stage is wired and a Schmitt trigger is integrated. Arp runs from internal tempo only in the meantime. The clock-mode-handling code paths are preserved so the Schmitt integration is a localized change.

### Added

- **Smoke-test firmware streams a `tempo_v` / `tempo_count` column** for MCP3208 CH1 alongside the existing CH0 columns. Lets the user verify any pot/CV wired to CH1 (currently the tempo pot) without re-flashing a one-shot test firmware. Output line is now `t_ms  dac_a_v  dac_b_v  adc_v  adc_count  tempo_v  tempo_count`.
- **Tempo pot bench-validated end-to-end on the new MCP3208 CH1 wiring.** Endpoints clean (CCW: count=0 / 0.000 V, CW: count=4090 / 4.09 V — within 5 LSB of full-scale), smooth monotonic sweep across the full rotation, no jitter or dropouts. `bench-log.md` 2026-05-02 entry covers the move; this commit confirms the result.

- **`docs/decisions.md` §27 — Calibration architecture, designed now, built later.** Captures the full design of the calibration story after a focused grilling session: form factor (app within Story 018's app switcher), trigger (auto-on-missing-data + manual via app switcher), loopback method (Eurorack patch cable J3 → J1 / J4 → J2), reference (REF3040 trusted as ±0.2 % absolute, ~5 cents at V/Oct), math (fused output + input pair per channel, 5-point linear fit, REF3040-anchored), one-time-only assumption (hardware doesn't drift), and the EEPROM-emulated-in-flash storage format with magic / version / last-app / calibration block / CRC32. Calibration data survives normal `picotool` re-flash (lives in last 4 KB sector). Sequenced after Rev 0.1 PCB manufacture so we calibrate against the real board, not the breadboard.
- **`docs/stories/022-calibration-app.md`** — deferred story implementing §27. Acceptance criteria cover app registration, auto-trigger on missing data, full UI flow (welcome → patch prompt → DAC sweep → linear fit → sanity check → confirm + write), EEPROM I/O, bench verification (V/Oct accuracy ±5 cents per octave against multimeter), and host tests (linear fit + CRC + storage round-trip). Hard dependencies: Story 018 + Rev 0.1 PCB. Until Story 022 ships, production firmware uses hardcoded calibration constants from breadboard measurements (musically usable, not lab-grade).
- **Story 018 updated to reserve the §27 EEPROM layout** — Story 018 only writes the magic / version / last-app fields, but the calibration block + CRC32 region is laid out from the start so Story 022 doesn't need to migrate existing storage when it lands.

### Changed

- **`docs/decisions.md` "Still open" list pruned:** "Calibration storage", "Calibration-utility app", and "App-private settings persistence" all now point at §27 / Story 022 / the §27 grilling outcome (app-private state is RAM-only, no story needed).

- **Third bench session — input scaling stage + full-chain loopback validated.** `bench-log.md` 2026-04-30 (continued) entry. Built TL072 #3 channel A as the input scaling stage for jack J1 → MCP3208 ch 0 (R_series + BAT43 clamps + summing amp + offset divider on pin 3 mirrored from §6). Static jumper test gave op-amp output within 10 mV of prediction across ±5 V input range; slope −0.181 V/V vs predicted −0.180 (1 % error). Round-trip loopback (J3 → cable → J1) tracks within 20–30 mV across full DAC sweep, slope 0.796 vs predicted 0.792 (0.5 % error). **Story 015 acceptance criteria met. The entire post-pivot platform is now bench-validated end-to-end** (Stories 012 + 013 + 015).

### Fixed

- **`bench-wiring.md` §7 step 3 — "input floating ≈ +1.96 V" was wrong.** With the jack truly floating, no current can flow through R_series + R_in2, so no offset gain develops and pin 1 sits at V_pin3 ≈ +1.66 V instead of the bias-only output. The +1.96 V reading only appears when the jack is **actively grounded** — that's the actual test condition. Caught when the freshly-replaced TL072 #3 read 1.65 V on pin 1 with jack floating; doc said 1.96 V was expected, but the chip was behaving correctly. Doc updated to spell out both cases.

- **Bench rebuild after voltage misconfiguration killed the original MCP3208 + at least one TL072** (cause: rails misrouted on the breadboard pre-power-on). New `bench-log.md` 2026-05-02 entry. Replaced XIAO RP2350, MCP3208, and TL072 #3; brought up the analog chain piece by piece via the smoke-test firmware. DAC8552 + VREF buffer + output op-amps all survived (firmware still reads correct ±9 V at jacks J3/J4). Input stage rebuilt and characterized: 3-point linear fit gives slope −0.180 V/V (matches design within 1 %), and the inverted firmware constants (`gain ≈ −5.57`, `offset ≈ +10.88`) come within 0.2 % of the existing constants in `main.cpp` — **no firmware calibration change required.** Full-loop validation (J3 → patch cable → J1 → MCP3208 ch 0) tracks within 30 mV across the ±9 V swing. **The bench rig is fully restored.** Also captured: pot-as-source impedance lesson (100 kΩ pot driving 100 kΩ R_series sags badly — use a stiff supply or buffered source), and the SPI-MISO-pull-up disambiguation trick for "is the chip alive or not" debugging.

- **Input scaling stage topology + math (`bench-wiring.md` §7).** Same shape of bug as the §6 fix earlier in the week:
  - Original spec had VREF feeding the inverting input via R_off — same single-positive-supply problem as §6 had. Corrected to put the offset on **pin 3 (non-inverting) via a divider** (VREF → 22 kΩ → pin 3 → 15 kΩ → GND ≈ 1.66 V).
  - Original spec also missed that R_series (100 kΩ) and R_in2 (22 kΩ) are **in series** between the jack and the op-amp's virtual-ground inverting input — they look like a single 122 kΩ input resistor, not separate stages. Predicted-values table assumed `gain = R_fb/R_in2 = 0.214`, but actual gain is `R_fb/(R_series + R_in2) = 0.039` with R_fb = 4.7 kΩ — about 17 % of expected. Caught at the bench when the first measurement gave the right shape but the wrong magnitude.
  - Fix: bump R_fb from 4.7 kΩ to **22 kΩ** to compensate for the 100 kΩ R_series. New gain = 22/122 = 0.180. Bench-validated with predictions within 1 % across the full sweep.
  - Wire list, math, schematic, predicted-values table, and bench procedure all updated. Channel-B note updated to share the new offset divider via pin 5 → pin 3, mirroring the §6 trick.

- **Second bench session — channel B + ADC loopback validated.** `bench-log.md` 2026-04-30 entry. Channel B built (47 kΩ R_fb, sharing channel A's offset divider via pin 5 → pin 3); static jumper test gives +9.28 V / −9.91 V, dynamic two-channel scope shows clean independent triangle (J3) + square (J4). MCP3208 wired and brought up; loopback (DAC OUTA → MCP3208 ch 0) tracks within ±15 mV across the full 0..4.096 V sweep — dominated by analog noise + op-amp offset, not converter accuracy. **Story 012 acceptance criteria met on the bench.**
- **Smoke-test firmware extended to drive both DAC channels.** `src/main_smoketest.cpp` now writes channel A as a 1 Hz triangle (full DAC range) and channel B as a 0.5 Hz square between 1/4·VREF and 3/4·VREF. Different waveforms make channel-independence visually obvious on a 2-channel scope. Serial output gains a `dac_b_v` column.

- **First post-pivot bench session — channel A end-to-end working.** Captured in `bench-log.md` 2026-04-29 entry with scope screenshot. Validates: SPI bus arbitration, DAC8552 24-bit frame protocol via Rob Tillaart lib + `outputs::write()` HAL, pot+TL072 VREF stand-in stable to 4.096 V, inverting amp + non-inverting offset divider produces clean ±9 V bipolar swing at jack J3, end-to-end signal chain (XIAO firmware → SPI → DAC → analog stage → Eurorack-spec jack output) all the way through. Static measurements within 0.4 V of predicted; dynamic 1 Hz triangle on scope shows period 1.004 s and frequency 0.996 Hz vs spec'd 1.000 / 1.000.
- **`docs/images/bench-channel-a-triangle-jack.png`** — Rigol DS1Z scope capture of the bipolar triangle at jack J3 during the first end-to-end test, linked from `bench-log.md`.

### Fixed

- **DAC output-stage topology (`bench-wiring.md` §6 + Story 013).** Original spec had VREF feeding pin 2 alongside VDAC via R_off — this gives `Vout = −(R_fb/R_in)·VDAC − (R_fb/R_off)·VREF`, which can never produce a bipolar swing from a single positive reference (both contributions invert; output rails to negative). Caught at the bench when the first measurement read −8.90 V instead of the predicted +9 V. Corrected topology puts the offset on **pin 3 (non-inverting input) via a divider** — VREF → 22 kΩ → pin 3 → 15 kΩ → GND. With pin 3 at 1.66 V, the transfer function becomes `Vout = (1 + R_fb/R_in)·V_pin3 − (R_fb/R_in)·VDAC`, giving a clean symmetric ±9 V swing. Channel B's wire list updated to share the divider with channel A (pin 5 ties directly to pin 3 — no second divider needed). Story 013 acceptance criteria + Notes updated to match.

### Added

- **`docs/decisions.md` §26 — Pin budget at the limit.** Captures that all 11 castellated XIAO pins (D0–D10) are used after the SPI pivot; back-side pads aren't realistic for a 2 HP form factor. The MCP3208's 6 spare ADC channels (ch 2..ch 7) are the architectural safety valve — any future analog input (extra pots, more CV jacks) routes there at zero XIAO-pin cost. The tempo pot can also move from D0 to MCP3208 if a future app needs a dedicated digital pin. On-board LED + NeoPixel cover status indication without spending edge pins.
- **Deferred decision — I/O daughterboard / breakout module.** Long-term answer to the pin-budget ceiling: a second small PCB mating to the main board via header, exposing additional jacks/pots/buttons/LEDs. Sketch covers analog expansion (spare MCP3208 channels → extra jacks; possible 2nd DAC8552 on the SPI bus), digital expansion (MCP23017 IO expander on the OLED I²C bus → button matrix / LED grid), and form-factor options (side-mate, daughter-stack, wing). Deferred until a concrete app demands it.

- **Story 012 firmware scaffolding — SPI HAL + smoke test.**
  - `lib/outputs/` wraps DAC8552 with `outputs::write(ch, volts)` / `gate(ch, on)` / `setVRef(v)` / per-channel `setCalibration(gain, offset)`. Defaults are `gain=1.0, offset=0.0` (passthrough) until bench-fitted.
  - `lib/inputs/` wraps MCP3208 with `inputs::readVolts(ch)` / `readRaw(ch)` / `setVRef(v)` / `setCalibration(gain, offset)`. Same calibration shape.
  - `src/main_smoketest.cpp` — dedicated smoke-test entrypoint: triangle wave on DAC ch A (1 s period, 50 samples/cycle), reads MCP3208 ch 0 via 500 µs settle delay, prints `t_ms / dac_v / adc_v / adc_count` to serial. Loopback procedure: jumper DAC OUTA → MCP3208 ch 0; expect linear tracking within a few LSBs.
  - New `[env:seeed-xiao-rp2350-smoketest]` PlatformIO env uses `build_src_filter` to swap `main.cpp` for `main_smoketest.cpp` — production arp firmware stays untouched until SPI HAL integration in a follow-up. Run: `pio run -e seeed-xiao-rp2350-smoketest --target upload`.
  - `lib_deps` enabled: `robtillaart/DAC8552`, `robtillaart/MCP_ADC` (both MIT, both auto-resolve to MCP3208 with hardware SPI default).
  - Smoke-test env: 2.0% RAM, 3.0% flash. Production env still builds. All 66 host tests pass.
  - Bench expects VREF = 4.096 V; sourced from the pot+TL072 stand-in per `docs/bench-wiring.md` §5 until REF3040 arrives, then drop-in replace.
- **`docs/bench-wiring.md`** — single-source pin/net/component reference for the breadboard rebuild covering Stories 012 + 013 + 015 in one session. Sections: BOM, power distribution, XIAO pinout w/ encoder migration (D8/D9/D10 → D1/D2/D7), shared SPI bus, pot+TL072 VREF stand-in, output stage with E96/E12 picks, input protection + scaling, OLED + UI hookup, jack assignments, 9-step incremental build/test order.

- **`docs/decisions.md` §25 — JLCPCB-first BOM strategy + VDD/VREF separation.** Captures the policy now driving Rev 0.1 part selection: prefer JLC Basic parts when an equivalent exists; accept Extended for specialty ICs. Architectural change recorded: VDD (AMS1117 +5 V LDO) is decoupled from VREF (REF3040 4.096 V precision reference) so the 16-bit DAC isn't bottlenecked by the LDO's 1–2 % accuracy. Both DAC8552 and MCP3208 share the REF3040 output. Resolution gains: DAC = 62.5 µV/step exactly; ADC = 1.00 mV/step exactly.
- **`hardware/bom.md`** — single source of truth for the JLC PCBA BOM. Lists every SMD part with LCSC number, package, Basic/Extended class, and unit price. Through-hole / panel parts (Thonkiconn jacks, encoder, pots, OLED, XIAO sockets) tracked separately as hand-soldered. Includes a vetting checklist for adding future parts.
- **Vetted JLC parts (vs decisions.md §25):** AMS1117-5.0 (C6187, Basic) for +5 V LDO; REF3040AIDBZR (C19415) for 4.096 V VREF; DAC8552IDGKR (C136020) for the dual 16-bit DAC; MCP3208T-CI/SL (C626764) C-grade for the 8-ch ADC; TL072CDT (C6961, Basic) ×2 for op-amps; BAT54SLT1G (C19726) ×4 for jack clamps (Schottky series-pair, replaces individual BAT43s — same 30 V breakdown, fewer footprints); GZ2012D601TF (C1017, Basic) ×2 for ±12 V rail ferrites.

### Changed

- **Stories 011 / 012 / 013 / 015 updated** to reflect the new architecture: ferrites + AMS1117 LDO + REF3040 precision VREF; output-stage gain bumped from 4 to ≈ 4.88 (R_fb = 48.7 k, R_in = 10 k, R_off = 20 k) so DAC's 4.096 V max swing still produces ±10 V at the jack; input-stage scaling recomputed for ADC's 4.096 V span; clamp diodes specified as BAT54S throughout (was BAT43).
- **Decisions.md "Deferred" list:** "DAC8552 VREF source" entry resolved — REF3040 is in from Rev 0.1 per §25, not deferred.

- **Story 020 — Order screens + Random + UpDownClosed.** Major arp engine + UI work:
  - **Engine renames** (clarification, no behaviour change): `ArpOrder::UpDown` → `ArpOrder::UpDownOpen`, `ArpOrder::Skip` → `ArpOrder::SkipUp`. The `SkipUp` rename anticipates a `SkipDown` and other finger-picking patterns.
  - **`ArpOrder::UpDownClosed`** — palindrome WITH endpoint repeat (`0,1,2,3,3,2,1,0`, period `2N`). Top doubled in middle; bottom doubled across loop boundary.
  - **`ArpOrder::Random`** — pure random index per step (with replacement). Uses `std::rand()` seeded in `setup()` from `millis()` ⊕ noisy ADC read.
  - **5 static order screens** auto-exported from `order.aseprite` tags. Bar-chart art: one bar per chord note, height = pitch, position = playback order.
  - **Procedural random-bars animation** for Random — 8 vertical bars at random heights, redrawn on every step advance when ORDER is the active param. Communicates unpredictability viscerally.
  - **`docs/decisions.md` §24** documents open vs closed palindrome terminology + Random seeding convention.
  - 6 new host tests (UpDownClosed × 3, Random × 3) + existing UpDown/Skip tests renamed. **Total: 60 → 66, all green.**
  - **Future deferred:** highlight active bar in the order-screen diagram per step.

- **Aseprite CLI auto-export pipeline.** New `tools/aseprite-export.js` walks `assets/screens/**/*.aseprite` and exports each tagged frame using Aseprite's built-in `{tag}` placeholder substitution (`aseprite -b file --save-as 'dir/<base>-{tag}.png'`). Single-frame tags produce `<base>-<tag>.png` directly; multi-frame tags (e.g. `Loop` covering all frames) produce `<base>-<tag>1.png`...`<base>-<tag>N.png` which are auto-detected and deleted with a friendly warning telling the user to remove the multi-frame tag in Aseprite. Untagged .aseprite files produce `<base>-.png` (empty-tag artifact) which is also auto-deleted with a warning. Tag-based naming (`key-A.png`) makes the C++ lookup self-documenting (`screens::key_A`). Wired into `npm run build:screens` ahead of `bitmap2header.js`. Aseprite path defaults to the macOS standard install; override via `ASEPRITE_PATH`.
- `tools/aseprite-list-tags.lua` kept around but **deprecated** — the simpler `{tag}`-substitution approach replaced it. Preserved in case a future task needs richer Aseprite introspection that the standard CLI flags don't expose (1.3.17.1's `--list-tags` and `--data` JSON tag-export return empty even when tags exist).
- **All 12 keys now graphical.** Auto-exported A through G PNGs from `key.aseprite`'s tags. The `keyNaturalScreen()` lookup maps each pitch class to its natural-note bitmap (sharps to the natural just below — C# uses C, F# uses F, etc.). When the active key is a sharp, an 8×8 `screens::sharp` glyph is composited over the natural at `(24, 18)`–`(31, 25)` (top-right corner flush with the right edge of the 32-wide portrait panel). Bench-tuned position 2026-04-26.
- New `screens::sharp` (8×8) and `screens::key_A`–`screens::key_G` (32×64 each) in the generated screens library.

- **Trigger ratcheting (Story 019).** New menu param `TRIG` (1, 2, 3, 4 — selectable via encoder). Each arp note still produces one pitch, but the gate fires N evenly-spaced times within the note. Each sub-gate is `(stepMs / N) * 0.5` long with a 5 ms floor. Composes with the external-clock multiplier — multiplier controls notes-per-pulse, ratchet controls gates-per-note (so external + ×2 + TRIG 3 = 6 gates per incoming pulse). Encoder cycle: SCALE → ORDER → ROOT → TRIG → SCALE. NeoPixel adds yellow/amber for TRIG. Bench-confirmed audibly at all four values. Future: random ratchet (Story 020 deferred).

- **Graphics pipeline for the OLED** — `assets/screens/*.png` are converted to a packed C++ bitmap library by `tools/bitmap2header.js` (Node, one dep: `pngjs`). The generated `firmware/arp/lib/screens/{screens.h,screens.cpp}` exposes each PNG as `screens::<name>` with a tiny `Screen` struct (`data`, `width`, `height`). **Animation support:** any subdirectory of PNGs under `assets/screens/` also emits a `screens::Animation` (ordered frame-pointer array + count). Frame order within a directory is natural-sort (`frame2` before `frame10`). Packed in Adafruit GFX `drawBitmap` byte order. Workflow: drop PNG → `npm run build:screens` → `pio run`. Details in `assets/screens/README.md`.
- **Boot splash animation.** 9-frame splash in `assets/screens/splash-screen-animation/` plays on every boot: frame 1 holds 3 s, frames 2–9 tick at 100 ms each (total ~3.8 s). Blocking call in `setup()`; runs before the normal menu renders.
- `OledUI::drawScreen(const screens::Screen&, x, y)` — thin passthrough to `Adafruit_SSD1306::drawBitmap()`.
- `OledUI::playAnimation(const screens::Animation&, first_frame_hold_ms, frame_delay_ms, x, y)` — blocking animation player with distinct first-frame hold (splash-friendly).
- `tools/generate-sample-png.js` — one-shot helper that creates a 32×64 test PNG for round-trip verification on fresh clones. Delete `assets/screens/sample.png` once real art exists.
- `package.json` at repo root — `npm install` pulls `pngjs`; `npm run build:screens` regenerates the library. Pivot from Python to Node for tooling since the project's primary human is more fluent in JS.

### Changed

- **Bitmap threshold flipped to OLED-native convention.** Previously: dark pixel in PNG → lit pixel on OLED. Now: **white pixel in PNG → lit pixel on OLED, black → off.** Matches how the panel physically looks — draw with light strokes on a black canvas and your image on screen matches the display. `tools/bitmap2header.js` updated; README and the sample-PNG generator follow suit.

- `firmware/arp/lib/trigger_in/` — pure-C++ firmware Schmitt trigger (`trigger_in::Schmitt`) for rising-edge detection on a polled voltage signal. Defaults to Eurorack-standard thresholds (high = +1.5 V, low = +0.5 V, 1 V hysteresis). Constructor accepts custom thresholds; initial state is "not armed" so an idle-high jack at startup doesn't fire spuriously. Story 016 prep — wires straight into the buffered ADC reads from Story 015 when bench-built.
- 15 new GoogleTest cases in `test_trigger_in/` covering: initial-state safety, rising-edge fire-once, square-wave repeat, exact-threshold behaviour, hysteresis (ripple rejection + must-drop-below-low to re-arm), slow-ramp single-fire, reset, custom thresholds. **Total host tests: 45 → 60, all green.**

### Changed

- **Renamed the chord-anchor menu param from ROOT to KEY.** "Key" better describes what the user is dialing in — the tonal centre that anchors both the chord intervals and the scale quantisation. The selected pitch class IS the chord's root AND the scale's tonic, and musicians ask "what key is this in?", not "what root is this in?". Touchpoints: `Param::Root` → `Param::Key`, `rootPC` → `keyPC`, `ROOT_OCTAVE_BASE_MIDI` → `KEY_OCTAVE_BASE_MIDI`, `"ROOT"` → `"KEY"` in OLED + serial. Asset directory `assets/screens/root-screen/` → `key-screen/`, PNGs `root-A.png`..`root-F.png` → `key-A.png`..`key-F.png`, `screens::root_*` → `screens::key_*`. Underlying pitch-class-to-string helper `rootName()` kept as-is (it's a generic pitch-class formatter, not specifically about "root"). Bench-flashed 2026-04-26.

- **SPI pin map confirmed against the actual arduino-pico variant header** for `seeed_xiao_rp2350`. Corrects mistakes in the earlier spec-doc draft. Final mapping: SCK=D8/GP2, MISO=D9/GP4, MOSI=D10/GP3, default SS=D3/GP5. CS_DAC=D3 (default SS), CS_ADC=D6/GP0. Encoder migrates from D8/D9/D10 to A1/A2/D7 to free SPI0 default pins.
- **Library decision for SPI peripherals locked: Rob Tillaart's `DAC8552` and `MCP_ADC`** — both Arduino-framework, MIT-licensed, well-maintained. User has bench-validated the DAC8552 library previously in `~/Git/Electronics/eurorack/dac8852-test/`. This means we don't roll our own SPI frame packers; instead `lib/outputs/` and `lib/inputs/` HAL wrappers add calibration math on top of the proven libraries. Lib_deps staged in `platformio.ini` (commented; uncomment when bench-ready).
- Story 012 updated with confirmed pin map, encoder migration table, library choice, and bench acceptance criteria. Status: prep complete, awaiting parts.

- **`docs/generative-arp-module.md` rewritten end-to-end** to reflect the platform-module pivot and the SPI signal-chain architecture. Net changes from prior revision:
  - Reframed as platform module hosting multiple apps; arp is now one app of several
  - PWM-DAC + MCP6002 + native ADC chain replaced by **DAC8552 + MCP3208 + TL072s on ±12V**
  - All 4 jacks documented as symmetric / dual-purpose (CV ↔ trigger/gate)
  - **Mutable Instruments–style protection** topology spec'd on every input and output (100k series + BAT43 clamps + op-amp buffer)
  - Pin-assignment table updated for SPI bus; encoder reassigned from D8/D9/D10 to A1/A2/D3 to free SPI0 default pin set
  - Generic panel labels (`IN 1`/`IN 2`/`OUT 1`/`OUT 2`/`KNOB`)
  - NeoPixel light-pipe through panel PCB documented as a Rev 0.1 feature
  - Firmware section grew an "Apps + Platform + HAL + Drivers" four-layer architecture diagram and `App` interface definition
  - BOM rebuilt against actual inventory locations
  - Removed all stale MCP4725 references and the GP29-on-XIAO-RP2350 myth
- `docs/decisions.md` — added §19 (platform-module reframing), §20 (SPI bus replaces PWM-DAC + native ADC), §21 (TL072 + ±12V replaces MCP6002 + 5V), §22 (Mutable-style protection on every jack), §23 (generic jack labels). Reorganised "Deferred decisions" to separate **resolved** items (CV divider, ext-clock divider feel, gio-as-clock-source) from **still-open** items (calibration storage, app-private settings, second pot for Rev 0.2, NeoPixel light-pipe style, DAC VREF source, trigger output edge speed). Added a note to §18 (RP2350-E9) clarifying that the platform pivot moves CV/trigger jacks behind op-amp buffers, so the rule's practical impact on Rev 0.1 is small.
- `docs/stories/011-power-rails.md` reduced from "build a power supply" to "verify the Hivemind Protomato breadboarding kit's rails" — the bench platform handles ±12V/+5V/GND with reverse-protection. Original LM7805 + 1N5818 design preserved as reference for the Rev 0.1 PCB.

### Docs

- **Platform-module pivot scoped.** Stories 011–018 added — full bench-rebuild roadmap moving the design from "single-purpose arpeggiator on native ADC + PWM-DAC" to "platform module with shared SPI bus (DAC8552 + MCP3208) + MI-style protection + TL072 buffers + app-loader firmware skeleton."
- **Inventory check complete** (against `~/Git/binkey-data/parts/`). On hand and sufficient for bench: TL072CP (×25), DAC8552 (×4 — *upgrade* from spec'd MCP4822), PEC11L encoders (×5), PJ-3001F Thonkiconn jacks (30+), 100 kΩ linear pots (20+), BAT43 Schottky (50+), LM7805 + LM7912, all standard SMT R/C values. **Ordered:** MCP3208 SPI ADC (×2), Eurorack 2×5 shrouded headers (×5), 0.49" 64×32 SSD1306 OLED (delivery tomorrow). DAC8552 already mounted on a hand-soldered protoboard, ready for Story 012 SPI bring-up.

---

## [arp/v0.3.0] — 2026-04-23

**External clock-in lands; bench tooling matures.** Story 010 complete. gio can now be patched into an external Eurorack clock and follow it; the tempo pot becomes a clock multiplier (×1 / ×2 / ×4) when external is active. A standalone bench clock source (`firmware/clock-mod2/`) was built on a HAGIWO MOD2 board to drive testing. Two notable hardware bugs encountered and documented: RP2350-E9 silicon errata (broken internal pulldowns) and a MOD2 PCB defect (JP2 doesn't route to C18). 45 host tests still green.

### Added

- **Story 010:** External clock input on J1 (D3 / GP5). `digitalRead`-based edge detection with 10 ms software debounce (rejects bounce on slow edges). Auto-switches to external mode within 2 s of a detected rising edge; falls back to internal tempo pot on timeout. OLED top-right tag shows `INT` / `EXT`.
- **Story 010:** Tempo pot acts as a **clock multiplier** when external is active — bottom 1/3 = ×1 (one step per pulse), middle = ×2 (insert one interpolated step at half-period), top = ×4 (three interpolated steps at quarter-period spacing). Default ×2 chosen as the most musically useful at typical Eurorack clock rates. Interpolation uses the previously-measured period — one-pulse-late approximation; see `decisions.md` deferred section for the runaway-on-slowdown caveat.
- `firmware/clock-mod2/` — bench clock source for a HAGIWO MOD2 board (XIAO RP2350 socketed). POT1 sets pulse rate exponentially in **2..20 Hz** (renamed from BPM since "BPM" is the wrong unit for a raw clock). GP1 → MOD2 op-amp gain stage → 0–10 V gates at J6. GP5 drives the panel LED in sync.
- `docs/stories/010-clock-input.md`, detailed `docs/bench-log.md` entry covering the full Story 010 + side-quest bench journey.

### Changed

- `firmware/arp/src/main.cpp`: `PIN_J1 = D3 / GP5` (digital, not analog). Spec called for `A3 / GP29` but **GP29 is not exposed on the XIAO RP2350** (variant only breaks out GP0–7 + GP9–12, GP16–17, GP20–21). All ADC-capable pins (GP26/27/28) are already used, so J1 is digital-only on this build; pitch mode on J1 is deferred until an ADC channel is freed.
- `firmware/arp/src/main.cpp`: `pinMode(PIN_J1, INPUT_PULLDOWN)` — kept as belt-and-braces, but the internal pulldown is silently broken on RP2350 (see RP2350-E9 below). The external 10 kΩ pulldown is what actually pulls the pin low.
- Bench input divider on J1: spec was 100 kΩ + 68 kΩ; **bench-built as 10 kΩ + 10 kΩ** to overpower the RP2350-E9 latched-pad voltage. Same 1:2 ratio so firmware needs no change.
- `firmware/clock-mod2/`: switched from `tempo::potToBpm` (20..300 BPM, quarter notes) to direct exponential `potToHz` (2..20 Hz). "BPM" is the wrong unit for a raw clock source; raised the floor and ceiling to better match Eurorack clock rates.

### Docs

- **`docs/decisions.md` §18 — RP2350-E9 silicon errata.** Internal `INPUT_PULLDOWN` latches the pad at ~2.2 V instead of pulling to GND. Pi Foundation workaround: external pulldown ≤ 8.2 kΩ. Cost ~90 min of bench debugging during Story 010 before user spotted the errata. **Rule for Rev 0.1 PCB:** every GPIO that needs a pulldown gets an external resistor ≤ 8.2 kΩ.
- `docs/decisions.md` "Deferred decisions" — added: (a) the MOD2 JP2 lesson (verify every solder-jumper net survives schematic→PCB transfer); (b) "gio as a clock source" feature placeholder; (c) external-clock multiplier feel notes (×1/×2/×4 is fine; replace with ÷N would be a regression at Eurorack rates; multiplication is the genuinely useful direction).
- **BOOTSEL workflow update** — discovered today that `picotool` can soft-reset the running firmware into BOOTSEL via USB CDC, so `pio run --target upload` works without any button-press for normal re-flashes. Manual hold-BOOT-while-plug only needed for fresh chips or unresponsive firmware. Updated `CLAUDE.md`, `firmware/arp/README.md`, and `firmware/clock-mod2/README.md`.
- `firmware/clock-mod2/README.md`: documents the **JP2/C18 board defect on MOD2 Rev A** — soldered solder-bridge has no electrical effect because the JP2 traces don't reach C18. Workaround: solder a wire across C18 directly.
- New `docs/stories/010-clock-input.md`.

---

## [arp/v0.2.0] — 2026-04-22

**Module is fully hands-on playable.** Stories 006–009 complete. Live tempo pot, OLED + encoder hardware alive, full encoder menu (scale + order + root with long-press reset), audible scale quantisation per step, and V/oct CV input on J2 that transposes the arp. 45 host tests passing.

### Added

- **Story 009:** `firmware/arp/lib/cv/` — pure-C++ `cvVoltsToTranspose(volts, scale)` (semitone round → scale-snap within octave, input clamped to [0, 8 V]). 10 new host tests.
- **Story 009:** CV input on J2 transposes the arp (V/oct, α-summed with encoder ROOT). ½-semitone hysteresis wrapper kills ADC-noise flutter at snap boundaries. Final played notes clamped to MIDI [24, 96].
- **Story 009:** MCP6002 op-amp B repurposed as unity-gain buffer on the CV input path. Divider: 100 kΩ series + (47 kΩ + 22 kΩ) to GND = 69 kΩ (≈ spec 68 kΩ). Maps 0..8 V at J2 to 0..3.24 V at A1/GP27.
- **Story 009:** New menu param `ROOT` (12 pitch classes, pinned to MIDI octave 3, default C). Encoder menu cycle: SCALE → ORDER → ROOT → SCALE. NeoPixel **magenta** for ROOT active. OLED `ROOT` line shows the *effective* root (encoder + CV, mod 12) with trailing `*` when CV is contributing.
- **Story 009:** Chord stored as intervals `{0, 4, 7, 12}` instead of absolute MIDI notes. Runtime `root_midi` computed per step.
- **Story 008:** Encoder menu for Scale and Order. Click cycles parameter (Scale → Order → Scale), rotate changes the active value, **long-press (≥500 ms)** resets the arp at step 0 and flashes "RESET" on the OLED. Long-press fires mid-hold; release is silent (no spurious short-click on the same gesture).
- **Story 008:** Scale changes are now *audible* — each arp note passes through `quantize()` with the active scale before reaching the DAC.
- **Story 008:** Onboard RGB LED as active-param indicator — green for Scale, blue for Order. Pin discovery: data on **GPIO22**, power-enable on **GPIO23** (per Seeed wiki; not exposed by the arduino-pico variant header). LED is **RGBW** (4 bytes/pixel) → `NEO_GRBW + NEO_KHZ800`. 20 ms settle delay between power-enable and first `show()`.
- **Story 007:** `firmware/arp/lib/oled_ui/` — HAL wrapper around `Adafruit_SSD1306`. Three-constant config block (`OLED_WIDTH`, `OLED_HEIGHT`, `OLED_ROTATION`) for one-line swap between bench (0.91" 128×32 landscape) and final (0.49" 64×32 portrait).
- **Story 007:** `firmware/arp/lib/encoder_input/` — HAL wrapper around `mathertel/RotaryEncoder` + 50 ms-debounced click + `pressedLong()` (≥500 ms threshold). `LatchMode = FOUR3` chosen after bench iteration.
- **Story 006:** Tempo pot on A0 (D0/GP26, B10K) drives live BPM control. `src/main.cpp` reads `analogRead(PIN_TEMPO)` at every step boundary and recomputes step/gate periods from `tempo::potToBpm()` + `tempo::bpmToStepMs(bpm, 4)`. Subdivision switched from quarter notes to 16th notes (125 ms/step at 120 BPM).
- Host test coverage grew from 34 → 45: new `test_tempo::PotToBpm.ConstantRatioPerEqualPotSlice`, 11 `test_arp` cases kept current after `Order1324 → Skip` rename, 10 new `test_cv` cases.
- `docs/decisions.md` §17: encoder library choice documented (`mathertel/RotaryEncoder`, polling, RP2350-compatible). Deferred-decisions bullet removed.
- `firmware/arp/README.md`: documented the BOOTSEL quirk (double-tap BOOT unreliable on our XIAO RP2350; use hold-BOOT-while-plugging).
- `docs/stories/009-cv-input-transpose.md` added. `docs/bench-log.md` entries for Stories 006, 007, 008, 009 (including the 100 Ω vs 100 kΩ colour-band bug and its diagnosis from serial output).

### Changed

- `lib/arp/ArpOrder::Order1324` → `ArpOrder::Skip` (matches menu UI labeling). Test cases renamed. No behaviour change.
- `lib/tempo/potToBpm()` mapping: linear → exponential (`BPM_MIN × (BPM_MAX/BPM_MIN)^pot`). Endpoints exact; ratio per equal pot slice is constant → uniform musical feel across rotation.
- `lib/tempo/BPM_MIN`: 30 → 40 (Story 006 spec) → **20** (bench-feel adjustment — 40 BPM 16ths still felt too fast at the slow end). Per-third ratio ≈ 2.47×.
- `firmware/arp/src/main.cpp` rewritten three times across Stories 006–009: tempo-pot integration → standalone OLED/encoder bring-up → full arp+menu integration → CV-transpose integration. Now a non-blocking `millis()` loop with all subsystems live.
- `lib/encoder_input/` `RotaryEncoder::LatchMode` bench-tuned to `FOUR3` (TWO03 → FOUR0 → FOUR3 during Story 008 bring-up; header documents troubleshooting hints).
- `docs/stories/006-tempo-pot.md`: AC text updated to reflect the 20..300 BPM range and constant-ratio framing (replaces "every 1/3 doubles BPM" language).
- `firmware/arp/README.md`: library notes corrected (was: Stoffregen Encoder, default OLED size; now: mathertel/RotaryEncoder, `oled_ui` config block, NeoPixel pinout).
- `firmware/arp/platformio.ini`: added `mathertel/RotaryEncoder` to `lib_deps`; removed `paulstoffregen/Encoder` (AVR-only).

---

## [arp/v0.1.0] — 2026-04-22

**Milestone: the module makes music.** Stories 001–005 complete. End-to-end signal chain bench-validated: scales/arp/tempo logic + 12-bit PWM DAC on D2 + 2-pole RC filter + MCP6002 op-amp scaling + BC548 NPN gate driver + LED beat indicator. Audible 4-note up-arpeggio at 120 BPM through a VCO confirmed on bench. 34 host tests passing.

### Added

- **Story 005:** `firmware/arp/lib/arp/` — pure-C++ arpeggiator engine. `Arp::nextNote()` advances state and returns the MIDI note for the current step. Orders implemented: `Up`, `Down`, `UpDown` (palindrome, no endpoint repeat), `Order1324` (skip pattern, falls back to `Up` for arps with <4 notes). Adding a new order = adding one case in `indexForStep()`.
- **Story 005:** `firmware/arp/lib/tempo/` — pure-C++ tempo helper. `bpmToStepMs(bpm, sub=1)` clamped to [30, 300] BPM with subdivision support; `potToBpm(pot)` linear in [0, 1] → [BPM_MIN, BPM_MAX].
- **Story 005:** 21 new GoogleTest cases (`test_arp` ×11, `test_tempo` ×10). Combined with `test_scales` (×13): 34 host tests, all green via `pio test -e native`.
- **Story 005:** `src/main.cpp` arp integration — non-blocking `millis()` loop, fixed 120 BPM, 4-note up-arpeggio over MIDI 48/52/55/60 (C3 E3 G3 C4), 50 % gate duty, `PIN_LED` as beat indicator. `GATE_INVERTED` constant abstracts NPN driver polarity.
- **Story 005:** BC548 NPN common-emitter gate driver wired on breadboard — D6 → 1 kΩ → base; collector → 10 kΩ pullup → 5V (= J4 gate node); emitter → GND.
- **Story 004:** MCP6002 op-amp non-inverting amp breadboarded (gain network 2.2 kΩ + 470 Ω in series for R_f, 10 kΩ for R_g), bench-calibrated 2026-04-22. Final firmware `GAIN = 1.26`. V/Oct output within ±2 mV / ±2.4¢ across C3–C7 by multimeter; ≤±4¢ best-fit residual end-to-end through VCO + tuner.
- **Story 003:** `firmware/arp/lib/scales/` — pure-C++ scale quantiser library: `quantize(midiNote, Scale)` and `scaleFromPot(pot, current)` with ±2 % hysteresis. No Arduino deps. 13 GoogleTest cases (in-scale pass-through, out-of-scale snapping with tie-break-downward, chromatic identity, octave invariance, scaleFromPot zone centres + hysteresis).
- **Story 003:** PWM DAC ramp bench-verified — raw 36.6 kHz square, 1-pole sawtooth, 2-pole clean ramp.
- **Story 002:** XIAO RP2350 blinky flashed via UF2 (picotool). Toolchain end-to-end verified.
- **Story 001:** Repo scaffolded — `firmware/arp/`, `hardware/`, `docs/`, `docs/stories/` directory tree; `LICENSE-firmware` (MIT), `LICENSE-hardware` (Apache 2.0), `LICENSE-docs` (CC-BY 4.0); root `README.md`; `CLAUDE.md`; `.gitignore`; `.github/workflows/ci.yml`; `firmware/arp/platformio.ini` and `firmware/arp/README.md`.
- New file `docs/calibration.md` — circuit, procedure, and raw data for the V/Oct stage.
- `docs/bench-log.md` started — entries for Stories 003, 004, 005.

### Changed

- **DAC architecture:** replaced MCP4725 I2C DAC with RP2350 12-bit hardware PWM on D2 + 2-pole RC filter (2× 10 kΩ + 100 nF, f_c ≈ 160 Hz). Eliminates I2C bus contention, removes MCP4725 from BOM, simplifies firmware (no library needed). Ripple < 63 µV; settling time ~5 ms. D2 pin reassigned from CV In #2 to PWM V/Oct out.
- **Input jacks:** J1 moved from D7 (digital-only, GP1) to A3 (GP29, ADC-capable). Both jacks dual-purpose: CLOCK mode (rising-edge) or PITCH mode (V/Oct → quantise), selectable per jack in encoder menu. Identical protection circuits (100 kΩ series + 68 kΩ to GND + BAT54 dual Schottky), 0–8V V/Oct → 0–3.24V ADC. D7 (GP1) freed as spare digital GPIO.
- **Timing architecture:** `millis()` state machine (non-blocking) chosen over `delay()` for gate/step timing. Allows encoder, OLED, pot, and external clock to be serviced every loop iteration. Hardware timer (Path B) deferred unless bench reveals audible jitter.
- `firmware/arp/platformio.ini`: `platform =` set to `maxgerhardt/platform-raspberrypi` with `platform_packages = framework-arduinopico @ …#4.4.0`. The bare `earlephilhower/arduino-pico` git URL cannot be used as `platform =` directly because PlatformIO requires a `platform.json` manifest at the package root.
- `firmware/arp/platformio.ini`: removed `paulstoffregen/Encoder` from `lib_deps` — uses AVR-specific register macros (`DIRECT_PIN_READ`, `pin1_register`) that do not compile on RP2350. Will be replaced with an RP2350-compatible alternative in Story 007.
- `firmware/arp/src/main.cpp`: `LED_BUILTIN` → `PIN_LED` — the `seeed_xiao_rp2350` variant defines `PIN_LED (25u)` but does not alias `LED_BUILTIN`.
- `docs/decisions.md` §11 corrected: arduino-pico has no per-pin `analogWriteFreq(pin, freq)` overload in any released version (only global form exists). Decision updated: use global `analogWriteFreq(freq)` once in `setup()`; for future multi-slice PWM use pico-sdk directly.
- `docs/decisions.md`: renumbered the duplicate §9/§10 entries (OLED and Git workflow); §11 is now "Platform version pinned to a tagged release"; subsequent sections shift to §12–§16.
- Stale `MCP4725` references removed from `docs/decisions.md` and `docs/stories/004` and `005`.

### Docs

- `docs/generative-arp-module.md` — Rev 0.1 spec: 2HP, XIAO RP2350, PWM DAC, 64×32 OLED, 1 pot, 1 encoder, 4 jacks.
- `docs/decisions.md` — tooling, scope, workflow decisions; rationale for PWM DAC, I2C sharing, port from RA4M1, library reuse, platform pinning, NPN gate driver.
- `docs/stories/README.md` — story format and workflow.
- `docs/stories/001` through `008` — backlog from repo scaffolding through encoder menu integration.

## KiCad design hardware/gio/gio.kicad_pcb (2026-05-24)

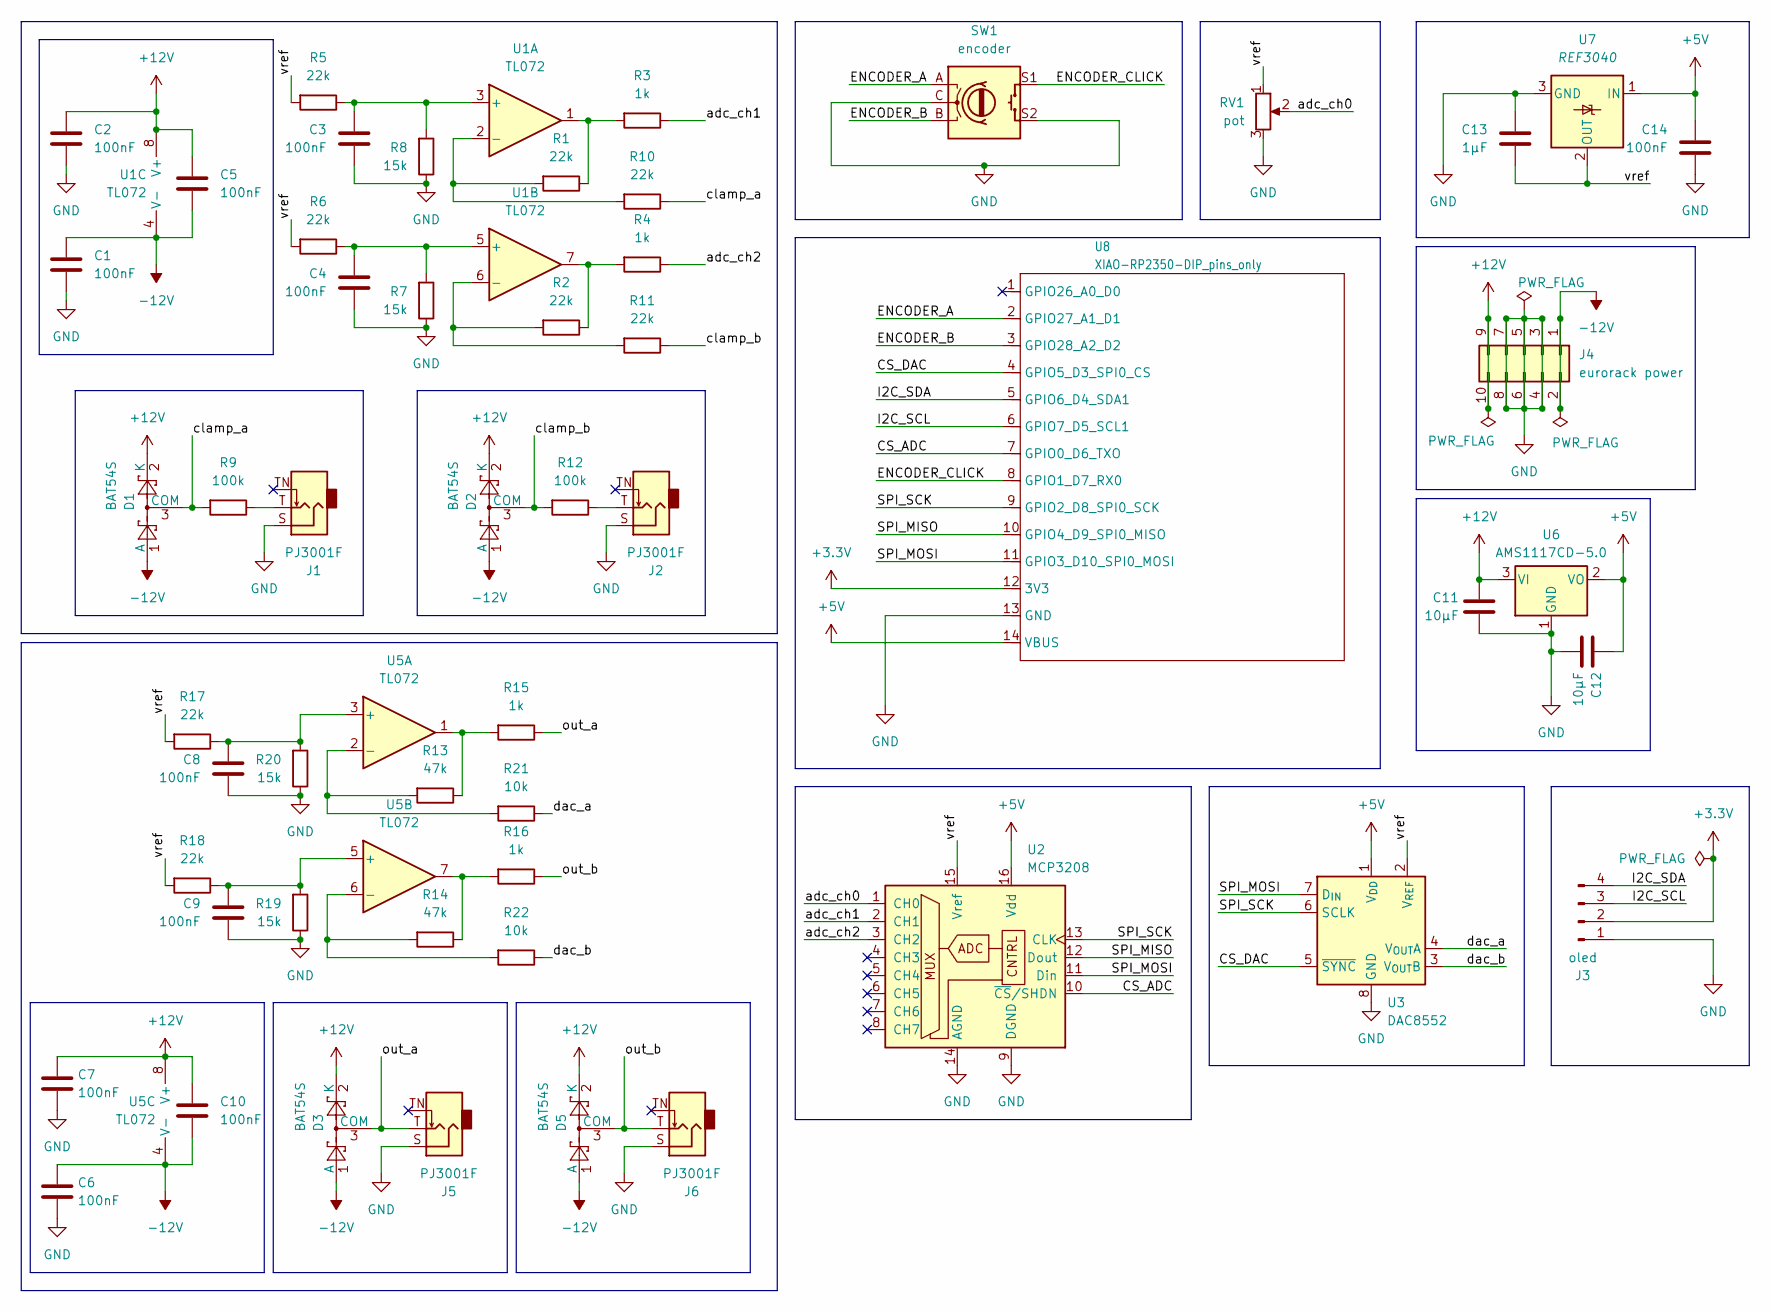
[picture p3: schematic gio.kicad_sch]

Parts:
C1, C2, C3, C4, C5, C6, C7, C8, C9, C10, C14: 100nF; C_0603_1608Metric
C11, C12: 10µF; C_0603_1608Metric
C13: 1µF; C_0603_1608Metric
D1, D2, D3, D5: BAT54S; SOT-23
J1, J2, J5, J6: PJ3001F; Jack_3.5mm_QingPu_WQP-PJ398SM_Vertical_CircularHoles
J3: oled; PinSocket_1x04_P2.54mm_Vertical
J4: eurorack power; IDC-Header_2x05_P2.54mm_Vertical
R1, R2, R5, R6, R10, R11, R17, R18: 22k; R_0603_1608Metric
R3, R4, R15, R16: 1k; R_0603_1608Metric
R7, R8, R19, R20: 15k; R_0603_1608Metric
R9, R12: 100k; R_0603_1608Metric
R13, R14: 47k; R_0603_1608Metric
R21, R22: 10k; R_0603_1608Metric
RV1: pot; Potentiometer_RV09
SW1: encoder; RotaryEncoder_Bourns_Vertical_PEC12R-3x17F-Sxxxx
U1, U5: TL072; SO-8_3.9x4.9mm_P1.27mm
U2: MCP3208; SOIC-16_3.9x9.9mm_P1.27mm
U3: DAC8552; Texas_S-PDSO-G8_3x3mm_P0.65mm
U6: AMS1117CD-5.0; SOT-223
U7: REF3040; SOT-23
U8: XIAO-RP2350-DIP_pins_only

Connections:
+3.3V: J3.2, U8.12 (3V3)
+5V: C12.1, C14.1, U2.16 (Vdd), U3.1 (V_{DD}), U6.2 (VO), U7.1 (IN), U8.14 (VBUS)
+12V: C2.1, C5.1, C7.1, C10.1, C11.1, D1.2 (K), D2.2 (K), D3.2 (K), D5.2 (K), J4.9, J4.10, U1.8 (V+), U5.8 (V+), U6.3 (VI)
-12V: C1.1, C5.2, C6.1, C10.2, D1.1 (A), D2.1 (A), D3.1 (A), D5.1 (A), J4.1, J4.2, U1.4 (V-), U5.4 (V-)
/CS_ADC: U2.10 (~CS/SHDN), U8.7 (GPIO0_D6_TXO)
/CS_DAC: U3.5 (~SYNC), U8.4 (GPIO5_D3_SPI0_CS)
/ENCODER_A: SW1.A, U8.2 (GPIO27_A1_D1)
/ENCODER_B: SW1.B, U8.3 (GPIO28_A2_D2)
/ENCODER_CLICK: SW1.S1, U8.8 (GPIO1_D7_RX0)
/I2C_SCL: J3.3, U8.6 (GPIO7_D5_SCL1)
/I2C_SDA: J3.4, U8.5 (GPIO6_D4_SDA1)
/SPI_MISO: U2.12 (Dout), U8.10 (GPIO4_D9_SPI0_MISO)
/SPI_MOSI: U2.11 (Din), U3.7 (D_{IN}), U8.11 (GPIO3_D10_SPI0_MOSI)
/SPI_SCK: U2.13 (CLK), U3.6 (SCLK), U8.9 (GPIO2_D8_SPI0_SCK)
/adc_ch0: RV1.2, U2.1 (CH0)
/adc_ch1: R3.1, U2.2 (CH1)
/adc_ch2: R4.1, U2.3 (CH2)
/clamp_a: D1.3 (COM), R9.2, R10.1
/clamp_b: D2.3 (COM), R11.1, R12.2
/dac_a: R21.1, U3.4 (V_{OUT}A)
/dac_b: R22.1, U3.3 (V_{OUT}B)
/out_a: D3.3 (COM), J5.T, R15.1
/out_b: D5.3 (COM), J6.T, R16.1
/vref: C13.2, R5.2, R6.2, R17.2, R18.2, RV1.1, U2.15 (Vref), U3.2 (V_{REF}), U7.2 (OUT)
GND: C1.2, C2.2, C3.2, C4.2, C6.2, C7.2, C8.2, C9.2, C11.2, C12.2, C13.1, C14.2, J1.S, J2.S, J3.1, J4.3, J4.4, J4.5, J4.6, J4.7, J4.8, J5.S, J6.S, R7.1, R8.1, R19.1, R20.1, RV1.3, SW1.C, SW1.S2, U2.9 (DGND), U2.14 (AGND), U3.8 (GND), U6.1 (GND), U7.3 (GND), U8.13 (GND)
unnamed: J1.T, R9.1
unnamed: J2.T, R12.1
unnamed: R1.1, R3.2, U1.1
unnamed: R2.1, R4.2, U1.7
unnamed: R13.1, R15.2, U5.1
unnamed: R14.1, R16.2, U5.7
unnamed: C3.1, R5.1, R8.2, U1.3 (+)
unnamed: R1.2, R10.2, U1.2 (-)
unnamed: C4.1, R6.1, R7.2, U1.5 (+)
unnamed: R2.2, R11.2, U1.6 (-)
unnamed: C8.1, R17.1, R20.2, U5.3 (+)
unnamed: R13.2, R21.2, U5.2 (-)
unnamed: C9.1, R18.1, R19.2, U5.5 (+)
unnamed: R14.2, R22.2, U5.6 (-)

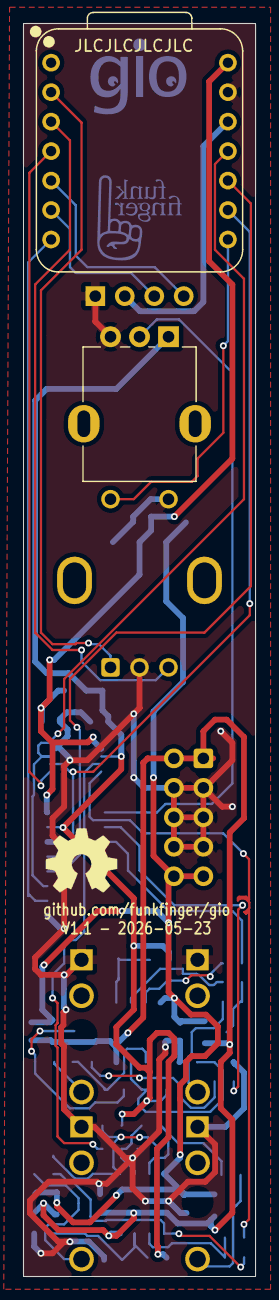
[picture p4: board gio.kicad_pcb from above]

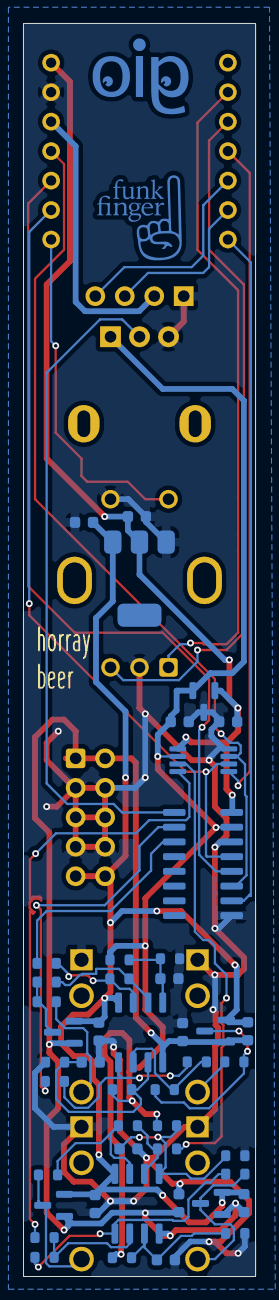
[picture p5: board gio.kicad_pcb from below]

Board: 2 copper layers, 20.0 x 108.0 mm, 57 parts (50 on the bottom side), 39 nets.

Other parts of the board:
funkfinger logo 9mm: funkfinger logo 9mm; funkfinger-logo-9mm-copper-mask
gio logo: gio-logo-front-copper-mask

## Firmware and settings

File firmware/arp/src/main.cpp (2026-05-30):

#include <Arduino.h>
#include <SPI.h>
#include <Wire.h>
#include <cstdlib>
#include <Adafruit_NeoPixel.h>
#include "arp.h"
#include "tempo.h"
#include "scales.h"
#include "cv.h"
#include "oled_ui.h"
#include "encoder_input.h"
#include "outputs.h"
#include "inputs.h"

// Platform-pivot migration (decisions.md §19–§25): firmware now drives the
// hardware via the SPI HAL (lib/outputs/ + lib/inputs/) instead of the old
// PWM-DAC + analog-CV + digital-gate paths. See bench-wiring.md for the
// breadboard topology this code targets.
//
// Canonical jack roles (decisions.md §23 — locked in 2026-05-29):
//   J1 / Input A  (MCP3208 CH1) — Clock in     (consumed when CLOCK=EXT)
//   J2 / Input B  (MCP3208 CH2) — CV in        (V/oct transpose; active in INT and EXT)
//   J3 / Output A (DAC ch A)    — CV out       (V/oct → VCO)
//   J4 / Output B (DAC ch B)    — Trigger out  (envelope/VCA; gate-style, HIGH for GATE_FRAC of each step)
//
// Clock source is an explicit encoder param (CLOCK = EXT / INT). EXT is the
// boot default and the arp sits silent until a clock cable arrives on J1; INT
// runs strictly from the tempo pot and ignores J1 entirely. There is no
// auto-fallback — the previously timeout-based mode switching was removed.

// ------------------------------ pins -------------------------------
// MCP3208 channel layout (decisions.md §26, finalized 2026-05-03):
//   CH0 = primary pot (tempo today; "primary pot" generically)
//   CH1 = J1 input — Clock in (per canonical role lock-in 2026-05-29)
//   CH2 = J2 input — CV in (V/oct transpose)
//   CH3–CH7 = expansion / daughterboard
// Conventionally: pots/internal controls at low channels, jacks contiguous
// after, expansion at high channels.
static const uint8_t  ADC_CH_POT      = 0;    // MCP3208 CH0 — primary pot wiper (tempo in this app)
static const uint8_t  ADC_CH_CLOCK_IN = 1;    // MCP3208 CH1 — J1 (Input A) clock in
static const uint8_t  ADC_CH_CV_IN    = 2;    // MCP3208 CH2 — J2 (Input B) CV in
// SPI bus: SCK=D8/GP2, MISO=D9/GP4, MOSI=D10/GP3 (handled by SPI.begin())
static const uint8_t  PIN_CS_DAC     = D3;   // GP5 — DAC8552 /SYNC
static const uint8_t  PIN_CS_ADC     = D6;   // GP0 — MCP3208 /CS
// Encoder pins migrated from D8/D9/D10 (now SPI bus) to D1/D2/D7. The A/B
// firmware-swap from 2026-05-02 was REVERTED on 2026-05-04: the breadboard
// wires were physically swapped so the schematic's natural assignment (A→D1,
// B→D2) reads CW as positive, instead of the firmware fighting the wiring.
// Wiring convention (matches schematic): encoder pin A → XIAO D1, B → XIAO D2.
static const uint8_t  PIN_ENC_A      = D1;   // GP27 (was D9/GP3 pre-pivot)
static const uint8_t  PIN_ENC_B      = D2;   // GP28 (was D8/GP2 pre-pivot)
static const uint8_t  PIN_ENC_CLICK  = D7;   // GP1  (was D10/GP4 pre-pivot)
// I²C: D4/D5 — handled by Wire.begin().
// PIN_LED — GPIO25, active LOW.

// Onboard RGB NeoPixel:
static const uint8_t PIN_NEOPIXEL_DATA   = 22;
static const uint8_t PIN_NEOPIXEL_POWER  = 23;
static const uint8_t NEOPIXEL_BRIGHTNESS = 64;

// ------------------------------ Analog reference -------------------
// Bench: pot+TL072 stand-in dialled to 4.096 V. Production: REF3040 at 4.096 V
// (decisions.md §25). Both DAC8552 and MCP3208 share this VREF so the system
// is ratiometric — VREF drift cancels across the loop.
static const float    BENCH_VREF_V  = 4.096f;
static const uint16_t ADC_MAX       = 4095;     // MCP3208 12-bit full-scale

// Music range. MAX raised to C9 (was C7) so OCT=4 + high-keyPC combos don't
// squash the top notes onto the ceiling — at OCT=4 the chord buffer's top
// interval is +48 semitones, and `keyMidi + interval` reaches 107 (B8) with
// keyPC=B. CV transpose still pushes past in extreme combos; that's
// acceptable. Hardware: midi 120 → +6 V at J3, well inside the +8.79 V
// output ceiling.
static const uint8_t MIDI_NOTE_MIN = 24;   // C1
static const uint8_t MIDI_NOTE_MAX = 120;  // C9

// ------------------------------ Clock-in ---------------------------
// External-clock edge detection lives on J1 (Input A) — see
// pollExternalClockEdge() below. The clock source itself (EXT vs INT) is
// driven by the encoder's CLOCK param; there is no auto-fallback. In INT
// mode, J1 signals are not even sampled by the edge detector.
//
// EXT_CLOCK_RESET_MS: when an edge arrives after a gap longer than this from
// the previous edge, the arp pattern is reset (next note = note 1) and the
// edge is treated as a fresh first pulse (no interpolation burst from the
// stale period). Default 2 s is arbitrary — exposed as a constant so it can
// later be promoted to an encoder param or sub-setting of CLOCK.
static const uint32_t EXT_CLOCK_RESET_MS = 2000;

// ----------------------------- music -------------------------------
// Chord stored as semitone INTERVALS from the active key. Key tonic is
// added at play-time. Default chord shape: major triad + octave.
static const int8_t CHORD_INTERVALS[] = {0, 4, 7, 12};
static const uint8_t CHORD_LEN        = 4;
static const uint8_t SUBDIV           = 4;       // 16th notes
static const float   GATE_FRAC        = 0.5f;

// Pitch class names for the KEY menu.
static const char* PITCH_CLASS_NAMES[12] = {
    "C", "C#", "D", "D#", "E", "F", "F#", "G", "G#", "A", "A#", "B"
};

// MIDI note number for KEY pitch-class index 0 (= C). The encoder KEY param
// pins the chord/scale tonic inside MIDI octave 3 (C3=48 .. B3=59).
static const uint8_t KEY_OCTAVE_BASE_MIDI = 48;

// ----------------------------- menu --------------------------------
enum class Param : uint8_t { Scale = 0, Order, Key, Trigger, Clock, Octave, COUNT };
static const uint8_t OCT_MIN = 1;
static const uint8_t OCT_MAX = 4;

// User-selected clock source. EXT (boot default) only fires on detected
// external clock edges on J1 — arp sits silent without a cable. INT runs
// strictly from the tempo pot and ignores J1 entirely; no auto-fallback in
// either direction.
enum class ClockSource : uint8_t { Ext = 0, Int, COUNT };

static const char* paramName(Param p) {
    switch (p) {
        case Param::Scale:   return "SCALE";
        case Param::Order:   return "ORDER";
        case Param::Key:     return "KEY";
        case Param::Trigger: return "TRIG";
        case Param::Clock:   return "CLOCK";
        case Param::Octave:  return "OCT";
        default:             return "?";
    }
}
static const char* clockSourceName(ClockSource c) {
    switch (c) {
        case ClockSource::Ext: return "EXT";
        case ClockSource::Int: return "INT";
        default:               return "?";
    }
}
static const char* scaleName(Scale s) {
    switch (s) {
        case Scale::Major:           return "Major";
        case Scale::NaturalMinor:    return "Nat Min";
        case Scale::PentatonicMajor: return "Pent Maj";
        case Scale::PentatonicMinor: return "Pent Min";
        case Scale::Dorian:          return "Dorian";
        case Scale::Chromatic:       return "Chrom";
        default:                     return "?";
    }
}
static const char* orderName(ArpOrder o) {
    switch (o) {
        case ArpOrder::Up:           return "Up";
        case ArpOrder::Down:         return "Down";
        case ArpOrder::UpDownClosed: return "UpDn-C";
        case ArpOrder::UpDownOpen:   return "UpDn-O";
        case ArpOrder::SkipUp:       return "SkipUp";
        case ArpOrder::Random:       return "Random";
        default:                     return "?";
    }
}
static const char* rootName(uint8_t pitchClass) {
    return PITCH_CLASS_NAMES[pitchClass % 12];
}

static inline uint8_t wrap(int v, uint8_t count) {
    int n = (int)count;
    int r = ((v % n) + n) % n;
    return (uint8_t)r;
}
static inline int clampi(int v, int lo, int hi) {
    if (v < lo) return lo;
    if (v > hi) return hi;
    return v;
}

// ----------------------------- state -------------------------------
static Arp           arp;
static Scale         scale       = Scale::Major;
static ArpOrder      order       = ArpOrder::Up;
static uint8_t       keyPC       = 0;             // 0=C, 1=C#, ... 11=B
static ClockSource   clockSource = ClockSource::Ext;
static uint8_t       octRange    = 1;             // OCT_MIN..OCT_MAX
static uint8_t       chordBuf[CHORD_LEN * OCT_MAX];
static uint8_t       chordBufLen = 0;
static Param         active      = Param::Scale;

static OledUI        ui;
static EncoderInput  enc;
static Adafruit_NeoPixel pixel(1, PIN_NEOPIXEL_DATA, NEO_GRBW + NEO_KHZ800);

static uint32_t lastStepMs       = 0;             // start of current note (note advance)
static uint32_t stepMs           = 125;           // total note length
static bool     gateOn           = false;
static uint32_t resetFlashUntilMs = 0;
static int      currentCvTranspose = 0;          // updated each step; used by display

// Trigger ratcheting (Story 019) — N gates per note. ratchet=1 = legacy
// behaviour; 2..4 fire sub-gates evenly within the note (same pitch, same
// step length). Composes with the external-clock multiplier — multiplier
// controls notes-per-pulse, ratchet controls gates-per-note.
static uint8_t  ratchet          = 1;             // 1..4
static uint32_t subStepMs        = 125;           // = stepMs / ratchet
static uint32_t subGateMs        = 62;            // = subStepMs * GATE_FRAC
static uint32_t lastSubGateMs    = 0;             // start of current sub-gate
static uint8_t  subGatesFired    = 0;             // sub-gates fired in current note

// External clock state
static bool     extClockHigh             = false; // current Schmitt-trigger output
static uint32_t extLastEdgeMs            = 0;     // millis() of last rising edge (0 = never)
static uint32_t extPrevEdgeMs            = 0;     // millis() of edge before that
static uint8_t  extMultiplier            = 2;     // 1, 2, or 4 steps per external pulse (from tempo pot)
static uint8_t  extStepsRemaining        = 0;     // interpolated steps still to fire before next pulse
static uint32_t extInterpolatedInterval  = 0;     // ms between interpolated steps (period / multiplier)

// ---------------------- voltage ↔ note -----------------------------
static float midiToVolts(uint8_t midi) {
    return ((float)midi - 48.0f) / 12.0f;
}

// Rebuild the arp's interval list by stacking CHORD_INTERVALS across
// `octRange` octaves. Consecutive duplicates are skipped — for the major
// triad + octave shape {0,4,7,12}, OCT=2 would otherwise produce
// {0,4,7,12, 12,16,19,24} with a doubled 12 across the octave boundary.
// Dedup yields {0,4,7,12,16,19,24} so Up/Down arps don't stutter on the
// repeat. Generic — works for any chord whose last interval equals the
// next octave's first (which is the usual case).
static void rebuildChord() {
    chordBufLen = 0;
    for (uint8_t oct = 0; oct < octRange; oct++) {
        for (uint8_t i = 0; i < CHORD_LEN; i++) {
            uint8_t v = (uint8_t)(CHORD_INTERVALS[i] + 12 * oct);
            if (chordBufLen > 0 && chordBuf[chordBufLen - 1] == v) continue;
            chordBuf[chordBufLen++] = v;
        }
    }
    arp.setNotes(chordBuf, chordBufLen);
}

// --------------------------- HAL helpers ---------------------------
// Gate on jack J4 (DAC ch B). outputs::gate() writes VREF for HIGH and 0 V
// for LOW; with the channel-B output stage's calibration that produces ~+4 V
// at the jack for HIGH and ~0 V for LOW — well within Eurorack gate spec.
static inline void gateWrite(bool on) {
    outputs::gate(1, on);
}
static inline void ledWrite(bool on) {
    digitalWrite(PIN_LED, on ? LOW : HIGH);
}

// --------------------------- CV reader -----------------------------
// inputs::readVolts(ADC_CH_CV_IN) returns calibrated jack-side volts on J2
// (Input B). The cv lib's volts-to-transpose function clamps negatives to 0
// and >8 V to 8 V, so we can pass through the full ±10 V span without extra
// defensive code here. Active in BOTH INT and EXT clock modes — J1 stays
// dedicated to clock.
static float readCvVolts() {
    return inputs::readVolts(ADC_CH_CV_IN);
}

// Hysteresis-wrapped transpose: only accept a new snapped value once voltage
// has moved more than ~half a semitone from the anchor. Kills ADC-noise
// flutter at the boundary between two scale-snapped values.
static int readCvTransposeWithHysteresis() {
    static int   held       = 0;
    static float heldVolts  = -1.0f;             // sentinel for first call
    const  float HYSTERESIS = 1.0f / 24.0f;       // ≈ 42 mV = ½ semitone
    float volts = readCvVolts();
    if (heldVolts < 0.0f) {
        held = cvVoltsToTranspose(volts, scale);
        heldVolts = volts;
        return held;
    }
    if (fabsf(volts - heldVolts) < HYSTERESIS) return held;
    held = cvVoltsToTranspose(volts, scale);
    heldVolts = volts;
    return held;
}

// --------------------------- engine glue ---------------------------
// Recompute sub-gate timing from a note length (called when stepMs or
// ratchet changes). Each sub-gate takes subStepMs from start to start;
// each gate stays HIGH for subGateMs (= subStepMs * GATE_FRAC).
static void recalcSubTiming(uint32_t noteMs) {
    if (ratchet < 1) ratchet = 1;
    subStepMs = noteMs / ratchet;
    if (subStepMs < 5) subStepMs = 5;             // sanity floor
    subGateMs = (uint32_t)((float)subStepMs * GATE_FRAC + 0.5f);
}

static void refreshTempoFromPot() {
    uint16_t raw = inputs::readRaw(ADC_CH_POT);
    if (raw > ADC_MAX) raw = ADC_MAX;
    float pot = (float)raw / (float)ADC_MAX;
    float bpm = tempo::potToBpm(pot);
    stepMs = tempo::bpmToStepMs(bpm, SUBDIV);
    recalcSubTiming(stepMs);
}

// Fire a sub-gate WITHOUT changing the DAC value — same pitch, just another
// trigger. Called between fireStep() invocations when ratchet > 1.
static void fireSubGate() {
    gateWrite(true);
    ledWrite(true);
    gateOn        = true;
    lastSubGateMs = millis();
    subGatesFired++;
}

// Read the tempo pot in external-clock mode and map it to a clock MULTIPLIER —
// how many arp steps to fire per external pulse. Three zones with hysteresis:
// bottom 1/3 → ×1 (one step per pulse), middle → ×2 (insert one step at the
// midpoint), top → ×4 (insert three at quarter-period spacing).
//
// The multiplier uses the previously-measured period to schedule interpolated
// steps — so it's a one-pulse-late approximation. If the source clock slows
// down between pulses, the interpolated steps still fire on the OLD interval
// and might overshoot. Acceptable for typical musical clock changes; would
// need rework if used with very wide tempo modulation.
static uint8_t externalMultiplierFromPot() {
    static uint8_t held = 2;                              // default ×2 — feels best at Eurorack rates
    static const uint16_t LOW_BOUND  = ADC_MAX / 3;       // ~1365
    static const uint16_t HIGH_BOUND = (2 * ADC_MAX) / 3; // ~2730
    static const uint16_t HYST       = 100;
    uint16_t raw = inputs::readRaw(ADC_CH_POT);
    if (raw > ADC_MAX) raw = ADC_MAX;
    if (held == 1 && raw > LOW_BOUND  + HYST) held = 2;
    if (held == 2 && raw < LOW_BOUND  - HYST) held = 1;
    if (held == 2 && raw > HIGH_BOUND + HYST) held = 4;
    if (held == 4 && raw < HIGH_BOUND - HYST) held = 2;
    return held;
}
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
void loop() {
    enc.poll();
    uint32_t now = millis();

    int8_t d = enc.delta();
    if (d != 0) {
        switch (active) {
            case Param::Scale:
                scale = (Scale)wrap((int)scale + (int)d, (uint8_t)Scale::COUNT);
                Serial.printf("scale=%s\n", scaleName(scale));
                break;
            case Param::Order:
                order = (ArpOrder)wrap((int)order + (int)d, (uint8_t)ArpOrder::COUNT);
                arp.setOrder(order);
                Serial.printf("order=%s\n", orderName(order));
                break;
            case Param::Key:
                keyPC = wrap((int)keyPC + (int)d, 12);
                Serial.printf("key=%s\n", rootName(keyPC));
                break;
            case Param::Trigger: {
                // Wrap 1..4 by mapping to 0..3, wrapping, then back.
                int next = wrap((int)ratchet - 1 + (int)d, 4) + 1;
                ratchet = (uint8_t)next;
                recalcSubTiming(stepMs);   // immediate effect
                Serial.printf("ratchet=%u\n", (unsigned)ratchet);
                break;
            }
            case Param::Octave: {
                int next = wrap((int)octRange - OCT_MIN + (int)d, OCT_MAX - OCT_MIN + 1) + OCT_MIN;
                octRange = (uint8_t)next;
                rebuildChord();
                Serial.printf("oct=%u (%u notes)\n",
                              (unsigned)octRange, (unsigned)chordBufLen);
                break;
            }
            case Param::Clock: {
                ClockSource prev = clockSource;
                clockSource = (ClockSource)wrap((int)clockSource + (int)d, (uint8_t)ClockSource::COUNT);
                if (prev != ClockSource::Ext && clockSource == ClockSource::Ext) {
                    // Re-arm edge detector: stale latches from before would
                    // either swallow the first incoming edge (extClockHigh
                    // stuck true) or fire a phantom interpolation burst (old
                    // edge timestamps still inside the multiplier window).
                    extClockHigh            = false;
                    extLastEdgeMs           = 0;
                    extPrevEdgeMs           = 0;
                    extStepsRemaining       = 0;
                    extInterpolatedInterval = 0;
                } else if (prev != ClockSource::Int && clockSource == ClockSource::Int) {
                    // Going INT: re-anchor pot-driven timing immediately so
                    // the next step fires on a fresh interval.
                    refreshTempoFromPot();
                    lastStepMs = millis();
                }
                Serial.printf("clock=%s\n", clockSourceName(clockSource));
                break;
            }
            default: break;
        }
        renderMenu();
    }

    if (enc.pressed()) {
        active = (Param)wrap((int)active + 1, (uint8_t)Param::COUNT);
        Serial.printf("active=%s\n", paramName(active));
        renderMenu();
        updateNeoPixel();
    }

    if (enc.pressedLong()) {
        arp.reset();
        resetFlashUntilMs = now + 600;
        Serial.println("LONG PRESS — arp reset");
        renderMenu();
    }

    // Gate-off check: each sub-gate stays HIGH for subGateMs.
    if (gateOn && (now - lastSubGateMs) >= subGateMs) {
        gateWrite(false);
        ledWrite(false);
        gateOn = false;
    }

    // Sub-gate fire (ratchet > 1): if more sub-gates remain in this note
    // and we're past one subStepMs from the last sub-gate's start, fire.
    if (!gateOn && subGatesFired < ratchet
        && (now - lastSubGateMs) >= subStepMs) {
        fireSubGate();
    }

    // ---- clock source: user selection via CLOCK param, no auto-fallback ----
    if (clockSource == ClockSource::Ext) {
        // External: each pulse fires a step + N-1 interpolated steps before
        // the next pulse. The interpolated interval is computed once per
        // pulse from the previously-measured period (so the very first pulse
        // doesn't interpolate — extPrevEdgeMs is 0). With no cable, no edges
        // arrive and the arp sits silent — that's the contract.
        if (pollExternalClockEdge()) {
            // Long idle gap: rewind the arp and treat this pulse as fresh —
            // skip interpolation that would otherwise use the stale period.
            if (extPrevEdgeMs > 0
                && (extLastEdgeMs - extPrevEdgeMs) > EXT_CLOCK_RESET_MS) {
                arp.reset();
                extPrevEdgeMs           = 0;
                extStepsRemaining       = 0;
                extInterpolatedInterval = 0;
                Serial.printf("clock idle >%lums — arp reset\n",
                              (unsigned long)EXT_CLOCK_RESET_MS);
            }
            extMultiplier = externalMultiplierFromPot();
            if (extPrevEdgeMs > 0 && extMultiplier > 0) {
                uint32_t period = extLastEdgeMs - extPrevEdgeMs;
                extInterpolatedInterval = period / extMultiplier;
            }
            extStepsRemaining = (extMultiplier > 0) ? (uint8_t)(extMultiplier - 1) : 0;
            fireStep();
        }
        // Fire any pending interpolated steps on schedule.
        if (extStepsRemaining > 0 && extInterpolatedInterval > 0
            && (now - lastStepMs) >= extInterpolatedInterval) {
            fireStep();
            extStepsRemaining--;
        }
    } else {
        // Internal: time-based step advance from the tempo pot. Edge detector
        // is intentionally NOT called here — J1 signals are ignored in INT.
        if ((now - lastStepMs) >= stepMs) {
            fireStep();
            if (resetFlashUntilMs && (int32_t)(now - resetFlashUntilMs) >= 0) {
                resetFlashUntilMs = 0;
                renderMenu();
            }
        }
    }
}

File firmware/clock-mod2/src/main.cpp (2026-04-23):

#include <Arduino.h>
#include <math.h>

// clock-mod2 — minimal square-wave clock source for the HAGIWO MOD2 board.
// Drives GP1 (which feeds the MOD2's 0→10 V output op-amp stage) at a rate
// set by POT1 (A0). The on-panel LED on GP5 blinks on each rising edge.
//
// The pot maps EXPONENTIALLY to a pulse rate in Hz (CLOCK_MIN_HZ..CLOCK_MAX_HZ).
// "BPM" isn't the right unit for a raw clock source — at the receiving end the
// arp may treat each pulse as a quarter, an eighth, or a sixteenth note,
// depending on configuration. Here we just pick a pulse rate.
//
// Bench note: MOD2 needs Eurorack ±12 V to actually emit a signal on the
// output jack (the op-amp runs off ±12 V). When powered from USB alone,
// the LED still blinks at the correct rate — useful for verifying before
// reinstalling into a rack.

// ------------------------------ pins -------------------------------
static const uint8_t PIN_POT_RATE  = A0;   // POT1 — rate control
static const uint8_t PIN_CLOCK_OUT = 1;    // GP1 → MOD2 output stage
static const uint8_t PIN_MOD2_LED       = 5;    // GP5 → D9 on the panel (active HIGH)

// ----------------------------- constants ---------------------------
static const float    DUTY          = 0.5f;       // 50 % gate high
static const uint16_t ADC_MAX       = 4095;
static const float    CLOCK_MIN_HZ  = 2.0f;       // ≈ 120 quarter-note BPM, slow end
static const float    CLOCK_MAX_HZ  = 20.0f;      // ≈ 1200 quarter-note BPM (or 300 BPM 16ths), fast end

// ------------------------------ state ------------------------------
static uint32_t periodMs   = 500;
static uint32_t highMs     = 250;
static uint32_t lastTickMs = 0;
static bool     highPhase  = false;

// Map normalised pot reading [0, 1] EXPONENTIALLY to a pulse rate in Hz.
// Endpoints exact; ratio per equal pot slice is constant — uniform musical feel.
static float potToHz(float pot) {
    if (pot < 0.0f) pot = 0.0f;
    if (pot > 1.0f) pot = 1.0f;
    return CLOCK_MIN_HZ * powf(CLOCK_MAX_HZ / CLOCK_MIN_HZ, pot);
}

// Sample POT1 and convert to period / high-phase durations. Called at each
// rising edge so the rate updates between ticks (never mid-pulse — no jitter).
static void refreshRateFromPot() {
    uint16_t raw = analogRead(PIN_POT_RATE);
    if (raw > ADC_MAX) raw = ADC_MAX;
    float pot = (float)raw / (float)ADC_MAX;
    float hz  = potToHz(pot);
    periodMs  = (uint32_t)(1000.0f / hz + 0.5f);
    highMs    = (uint32_t)((float)periodMs * DUTY + 0.5f);
}

// ------------------------------- setup -----------------------------
void setup() {
    analogReadResolution(12);
    pinMode(PIN_CLOCK_OUT, OUTPUT);
    pinMode(PIN_MOD2_LED,       OUTPUT);
    digitalWrite(PIN_CLOCK_OUT, LOW);
    digitalWrite(PIN_MOD2_LED,       LOW);

    Serial.begin(115200);
    uint32_t t0 = millis();
    while (!Serial && (millis() - t0) < 2000) { /* brief wait for USB CDC */ }

    Serial.println();
    Serial.println("=== clock-mod2 (HAGIWO MOD2 clock source) ===");
    Serial.println("POT1: rate (2..20 Hz exp)   OUT: GP1   LED: GP5");

    refreshRateFromPot();
    lastTickMs = millis();
}

// ------------------------------- loop ------------------------------
void loop() {
    uint32_t now     = millis();
    uint32_t elapsed = now - lastTickMs;

    // End-of-high-phase: bring OUT low halfway through the period.
    if (highPhase && elapsed >= highMs) {
        digitalWrite(PIN_CLOCK_OUT, LOW);
        digitalWrite(PIN_MOD2_LED,       LOW);
        highPhase = false;
    }

    // Start-of-period: rising edge. Re-sample pot here so rate changes take
    // effect at the next tick boundary instead of mid-pulse.
    if (elapsed >= periodMs) {
        digitalWrite(PIN_CLOCK_OUT, HIGH);
        digitalWrite(PIN_MOD2_LED,       HIGH);
        highPhase  = true;
        lastTickMs = now;
        refreshRateFromPot();
    }
}

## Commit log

2026-04-21 feat: scaffold gio — XIAO RP2350 generative arpeggiator
    Port of xiao-ra4m1-arp to the XIAO RP2350 with the encoder+OLED UI
    as baseline (not a retrofit). Establishes the full project structure,
    spec, decisions, user story backlog (stories 001–008), firmware
    scaffold, CI, and license files.
    Key differences from the RA4M1 predecessor:
    - MCP4725 I2C DAC replaces the RA4M1's onboard DAC
    - 64×32 SSD1306 OLED (0.49") on shared I2C bus with DAC
    - PEC11 encoder (D8/D9/D10) + 1 tempo pot (A0) from day one
    - Hardware I2C on D4/D5 preserves all 4 ADC pins
    - earlephilhower arduino-pico platform (seeed_xiao_rp2350 board)
    No firmware logic yet — Story 002 blinky in src/main.cpp.
    Logic libraries (s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
    [main.cpp]
2026-04-21 docs: replace MCP4725 I2C DAC with RP2350 PWM + 2-pole RC filter
    Decision made during pin-budget grill-me session. RP2350 12-bit hardware
    PWM on D2 at 36.6 kHz through a 2-pole passive RC filter (2× 10kΩ +
    100nF, f_c ≈ 160 Hz) gives < 63 µV ripple and 5 ms settling — better
    than an I2C DAC and with no bus contention with the OLED.
    Changes:
    - Spec: §2.3 MCP4725 replaced with PWM DAC spec and filter topology;
    §2.4 D2 reassigned from CV In #2 to PWM V/Oct out; I2C now OLED-only;
    §2.6 op-amp section updated with filter circuit and firmware snippet
    - Decisions: §3 updated (PWM DAC rationale); §4 updated (I2C dedicated)
    - Story 003: MCP4725 ramp → PWM ramp + filter bench criteri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
2026-04-21 docs: lock in 2HP / 4-jack constraint; A3 marked spare
    Q2 of pin-budget grill-me resolved: module is firmly 2HP with a 2×2
    jack layout (J1 clock in, J2 CV in, J3 V/Oct out, J4 gate out). A3
    (GP29) is an unpopulated spare internal pad — no panel jack in Rev 0.1.
    Panel layout note updated to make the 4-jack constraint explicit.
    https://claude.ai/code/session_01XVc7vzNY75HY939djUqTbP
2026-04-21 docs: dual-purpose input jacks; J1 moved to A3 for ADC capability
    Pin-budget grill-me Q3 resolved. Requirement: one trigger in, one V/Oct
    in, dual-purpose if the circuit allows it.
    Both J1 and J2 now use identical hardware — 100 kΩ series + 68 kΩ to
    GND + BAT54 dual Schottky — mapping 0–8V V/Oct to 0–3.24V at ADC (42
    counts/semitone, sufficient for scale quantisation) and clamping
    negatives safely. Firmware selects CLOCK or PITCH mode per jack via the
    encoder menu.
    J1 moved from D7 (GP1, digital-only) to D3/A3 (GP29, ADC-capable) so
    both jacks are on ADC pins and truly dual-purpose. D7 freed as spare.
    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
2026-04-21 docs: millis() non-blocking timing architecture (Path A)
    Pin-budget grill-me Q4 resolved. Gate and step timing uses millis()
    timestamp comparisons rather than delay(). Keeps the main loop free
    to service encoder, OLED updates, pot reads, and external clock edges
    every iteration. Worst-case jitter is ~5.8 ms (full OLED I2C refresh
    on parameter change) vs 50 ms/step at 300 BPM — acceptable for a
    generative arp; hardware timer revisit deferred to bench validation.
    Decisions §9 added. Story 005 updated to specify non-blocking timing.
    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
2026-04-21 build: pin arduino-pico to 4.4.0; require per-pin analogWriteFreq
    Platform version was tracking `main`, which is a silent reproducibility
    hazard and — more concretely — a risk to the PWM DAC. The PWM V/Oct path
    relies on `analogWriteFreq(pin, freq)` being the per-pin overload, not
    the older global form that would retune every PWM slice in the chip.
    - platformio.ini: pin `earlephilhower/arduino-pico#4.4.0`
    - decisions.md: add §11 "Platform version pinned to a tagged release"
    with rationale + bump protocol; renumber duplicate §9/§10; fix stale
    MCP4725 references in §10 bench list and bring-up table
    - stories/003: add toolchain sanity check (compile `analogWriteFreq(
    PIN_DAC_PWM,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
2026-04-21 feat: Story 002 done — XIAO RP2350 blinks, toolchain verified
    Three fixes needed to get from zero to flashing:
    - platform: bare earlephilhower git URL has no platform.json; switch to
    maxgerhardt/platform-raspberrypi + platform_packages for the pinned core
    - LED_BUILTIN undefined on seeed_xiao_rp2350 variant; use PIN_LED (GPIO25)
    - paulstoffregen/Encoder uses AVR register macros incompatible with RP2350;
    removed from lib_deps (replacement due in Story 007)
    Bench result: 56 KB / 2 MB flash, LED blinks at 1 Hz via picotool UF2 upload.
    Stories 001 and 002 marked done.
    [main.cpp]
2026-04-21 feat: Story 003 — scales TDD + PWM DAC ramp firmware
    Scale quantiser (host TDD):
    - lib/scales/scales.{h,cpp}: quantize(midiNote, Scale) with tie-break-down,
    scaleFromPot(pot, current) with ±2% hysteresis; all 6 scales defined
    - test/test_scales/test_main.cpp: 13 GoogleTest cases, all pass via pio test -e native
    PWM DAC ramp (bench pending):
    - main.cpp: 12-bit analogWrite sweep 0→4095 at ~10 Hz on D2 (GP28)
    - analogWriteFreq(36621) sets ~36.6 kHz carrier (global form — per-pin overload
    does not exist in any arduino-pico release; decisions.md §11 corrected)
    Bench scope steps (Story 003 AC) remain: raw PWM, 1-pole, 2-pole filter, ADC noise.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
    [main.cpp]
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2026-04-22 feat: Story 004 done — V/Oct op-amp scaling calibrated to ±2 mV
    Bench session 2026-04-22:
    - MCP6002 non-inverting amp breadboarded; R_f built as 2.2k + 470Ω series
    (2.67k effective) since 2.7k wasn't in the kit
    - Two-pass calibration: nominal GAIN=1.27 → measured slope 0.9917 → set GAIN=1.26
    - Pass 2 readings within ±2 mV per octave step (≈±2.4¢) — meets AC
    - VCO + tuner end-to-end: ≤±4¢ best-fit residual across C3-C7
    New docs/calibration.md captures circuit, procedure, and raw data.
    ADC noise check, CV divider verify, scope screenshots formally deferred.
    [main.cpp]
2026-04-22 feat: Story 005 done — v0.1.0 makes music
    The module plays its first arpeggio. C3-E3-G3-C4 up pattern at 120 BPM,
    500 ms/step with 50% gate duty, end-to-end through the calibrated
    V/Oct chain and a BC548 NPN gate driver into a VCO. Onboard LED
    flashes per beat.
    Code:
    - lib/arp/: data-driven arp engine (Up, Down, UpDown, Order1324)
    - lib/tempo/: BPM <-> step-period + pot mapping
    - 21 new host tests; 34 total green
    - main.cpp: non-blocking millis() loop, fixed 120 BPM, gate inversion
    abstracted via GATE_INVERTED
    Hardware:
    - BC548 NPN gate driver wired on D6: 1k base, 10k collector pullup
    to 5V, jack from collector node. Logic inverted at firmware level.
    - All other hardware (RC filter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
    [main.cpp]
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2026-04-22 feat: Story 006 — live tempo pot, exponential 20..300 BPM
    - tempo::potToBpm() switched from linear to exponential
    (BPM_MIN × (BPM_MAX/BPM_MIN)^pot — constant ratio per pot slice)
    - BPM_MIN: 40 → 20 after bench feel (slow crawl needed to feel slower)
    - main.cpp: analogRead(A0) every step, recompute step/gate ms from BPM,
    switch from quarter notes to 16th notes (sub=4)
    - New test: PotToBpm.ConstantRatioPerEqualPotSlice. 35 tests total.
    Bench-confirmed 2026-04-22. Pot turns translate immediately to tempo;
    LED stays in sync; no jitter.
    [main.cpp]
2026-04-22 feat: Story 007 — OLED + encoder bring-up
    Standalone HAL bring-up, no arp integration yet:
    - lib/oled_ui/: Adafruit_SSD1306 wrapper. Three-constant config block
    (OLED_WIDTH/HEIGHT/ROTATION) for one-line swap between bench
    (0.91" 128x32 landscape) and production (0.49" 64x32 portrait).
    - lib/encoder_input/: mathertel/RotaryEncoder + debounced click.
    - main.cpp: HELLO splash → live counter from encoder, LED on click.
    Decisions:
    - Encoder library = mathertel/RotaryEncoder (decisions.md §17),
    resolving the Story 002 fallout from removing paulstoffregen/Encoder.
    - Stale MCP4725 references in story 007 removed (we use PWM DAC).
    Bench-confirmed 2026-04-22 with the 0.91" substitute disp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
    [main.cpp]
2026-04-22 feat: Story 008 — encoder menu, scale-aware arp, NeoPixel param indicator
    Full integration of arp + tempo pot + OLED + encoder + onboard RGB LED.
    Menu (flat model — story spec, option A):
    - Click cycles parameter: Scale → Order → Scale
    - Rotate changes the active param's value (wraps)
    - Long-press (≥500ms) resets arp + flashes "RESET" on OLED
    - Long-press fires mid-hold (not on release) for tactile feedback
    Audio:
    - Each arp note now passes through quantize(note, scale) before the DAC,
    so picking Pent Min audibly snaps E→Eb in the chord. The scales
    library finally meets the arp engine.
    NeoPixel discovery (Seeed XIAO RP2350):
    - Data on GPIO22, power-enable on GPIO23 (must h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
    [main.cpp]
2026-04-22 feat: Story 009 — CV input for V/oct transpose (α-summing)
    Design locked via /grill-me: α-summing (encoder ROOT + CV transpose)
    instead of β-with-detection. Plaits-style — unplugged acts as 0V, knob
    still works. No jack-detection hardware needed.
    - lib/cv/cvVoltsToTranspose(volts, scale): semitone round + scale-snap
    within octave, clamped [0, 8V]. 10 new host tests, 45 total green.
    - main.cpp refactor:
    * CHORD_INTERVALS {0, 4, 7, 12} instead of absolute MIDI
    * Runtime root_midi = encoder ROOT + CV transpose per step
    * New Param::Root (12 pitch classes, pinned to MIDI octave 3)
    * NeoPixel magenta for Root active
    * Live OLED effective-root display with '*' when CV con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
    [main.cpp]
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2026-04-23 feat: Story 010 — external clock input on J1 (with RP2350-E9 lesson)
    Auto-detect external clock on J1; advances arp on each rising edge.
    Falls back to internal tempo pot if no edges in last 2 s. Tempo pot
    becomes a clock divider (÷1, ÷2, ÷4) when external is active. OLED
    shows INT/EXT badge.
    Spec deviations bench-confirmed:
    - J1 moved from spec'd A3/GP29 to D3/GP5. GP29 isn't exposed on the
    XIAO RP2350 (variant only breaks out GP0-7 + GP9-12, GP16-17,
    GP20-21). All ADC pins (GP26-28) are in use; J1 digital-only for
    now, pitch mode deferred.
    - Bench divider built as 10 kΩ + 10 kΩ instead of spec'd 100 k + 68 k.
    See decisions.md §18 — RP2350-E9 silicon errata: internal
    INP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
    [main.cpp]
2026-04-23 fix(arp): debounce J1 clock-in edge detection (10 ms)
    Bench-confirmed: a slow rising edge into D3 occasionally bounced
    across the GPIO threshold, producing two fireStep() calls per
    external trigger (LED flashed twice per pulse). Software debounce
    in pollExternalClockEdge() rejects rising edges within 10 ms of the
    previous accepted one. 6000 BPM ceiling — well above any musical
    clock rate.
    Also captures bench feedback in decisions.md deferred section: the
    ÷1/÷2/÷4 tempo-pot divider feels limiting at Eurorack clock rates;
    revisit as a multiplier or repurpose later if it bothers in actual
    patches.
    [main.cpp]
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2026-04-23 docs: BOOTSEL not required for normal re-flashes (picotool soft-reset works)
    Bench-confirmed today: PlatformIO + picotool can request the running
    firmware to reboot into BOOTSEL via USB CDC. So 'pio run --target upload'
    just works without any button-press. Manual BOOTSEL (hold BOOT while
    plugging USB) is only needed for fresh chips or unresponsive firmware.
    Updated:
    - CLAUDE.md: short comment in the build/upload block
    - firmware/arp/README.md: rewrote the upload section, kept the manual
    BOOTSEL procedure as a fallback
    - firmware/clock-mod2/README.md: same workflow note, points to arp README
    for the manual procedure
    [main.cpp]
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2026-04-24 feat(oled): PNG→bitmap pipeline + boot splash animation
    Node-based tool (tools/bitmap2header.js, one dep pngjs) converts PNGs
    under assets/screens/ into a packed C++ screens library. Every PNG
    becomes a `screens::<name>` with a `Screen` struct; every subdirectory
    of PNGs also becomes a `screens::<dir>` `Animation` (ordered frame
    pointers + count, natural-sorted).
    Boot splash: 9-frame animation in assets/screens/splash-screen-animation/
    plays on every boot. Frame 1 holds 3 s, frames 2-9 tick at 100 ms each.
    OledUI grew drawScreen() and playAnimation() helpers.
    Threshold convention flipped to OLED-native: white pixel in PNG = lit
    on display, black = off. Draw with light strokes on a black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
    [main.cpp]
2026-04-26 feat(arp): trigger ratcheting (Story 019) — TRIG menu, 1..4 gates per note
    Each arp step still produces one pitch. Within the step, the gate now fires
    N evenly-spaced times instead of once. Each sub-gate is
    (stepMs / N) * GATE_FRAC long, with a 5 ms floor for sanity at extreme
    tempos. Default TRIG=1 preserves legacy behaviour exactly.
    Composes cleanly with the external-clock multiplier:
    - Multiplier (×1/×2/×4) controls notes-per-pulse (note advancement scope)
    - TRIG (1..4) controls gates-per-note (within-note scope)
    So ext-clock + multiplier ×2 + TRIG 3 = 6 gates per incoming pulse.
    Refactor: replace gateMs with subGateMs + subStepMs + lastSubGateMs +
    subGatesFired. New helpers r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
    [main.cpp]
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2026-04-26 feat(oled): aseprite auto-export pipeline + graphical KEY menu (all 12 PCs)
    Adds tools/aseprite-export.js: walks assets/screens/**/*.aseprite, reads
    each file's tags via a tiny Lua script (CLI's --list-tags/--data are
    broken in Aseprite 1.3.17.1), and exports each single-frame tag as
    <base>-<tagname>.png. Multi-frame tags (e.g. a "Loop" covering all
    frames) and untagged frames are ignored — keeps manual PNGs (splash)
    untouched while auto-exporting tagged files (key.aseprite).
    Tag-based naming makes the C++ lookup self-documenting: key.aseprite
    with tags A..G produces screens::key_A..key_G directly.
    Quirk: Aseprite's --frame-range is 0-indexed but the Lua API reports
    frameNumber 1-indexed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
    [main.cpp]
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2026-04-26 feat(arp): Story 020 — order screens + Random + UpDownClosed
    Engine renames (no behaviour change for existing code):
    - ArpOrder::UpDown → ArpOrder::UpDownOpen (clarifies it's the open
    palindrome variant: 0,1,2,3,2,1, period 2N-2)
    - ArpOrder::Skip → ArpOrder::SkipUp (anticipates a future SkipDown
    and other finger-picking patterns)
    New variants:
    - ArpOrder::UpDownClosed: palindrome WITH endpoint repeat
    (0,1,2,3,3,2,1,0, period 2N). Top doubled in the middle, bottom
    doubled across the loop boundary. See decisions.md §24.
    - ArpOrder::Random: pure random index per step (with replacement)
    via std::rand(). Seeded in setup() from millis() ⊕ noisy ADC read;
    t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
    [main.cpp]
2026-04-26 feat(arp): random-bars overlay backdrop + tighter geometry
    drawRandomOrderScreen now renders screens::order_random as the static
    backdrop, then overlays 4 vertical bars (was 8) in an inset rectangle:
    - top margin 19 px (leaves room for the backdrop's header art)
    - left margin 3 px
    - right margin 3 px
    - bottom margin 3 px
    Drawing region: 26 wide × 42 tall. Bars 5 px wide with 2 px gaps:
    4·5 + 3·2 = 26 ✓. Heights still quantized to 8 levels for a "musical"
    feel rather than continuous noise.
    Bench-tuned 2026-04-26 per user feedback. Geometry matches the
    order-random.png art's intended composition.
    [main.cpp]
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2026-04-29 feat(firmware): SPI HAL scaffolding + Story 012 smoke test
    Add lib/outputs/ (DAC8552 wrapper) and lib/inputs/ (MCP3208 wrapper)
    with per-channel gain/offset calibration, plus a dedicated smoke-test
    entrypoint (src/main_smoketest.cpp) that drives a triangle wave on
    DAC ch A and reads it back via MCP3208 ch 0 over the shared SPI0 bus.
    A new PlatformIO env (seeed-xiao-rp2350-smoketest) uses build_src_filter
    to swap main.cpp for main_smoketest.cpp at compile time, so the
    production arp firmware stays untouched until the SPI HAL is fully
    integrated in a follow-up commit. Run via:
    pio run -d firmware/arp -e seeed-xiao-rp2350-smoketest --target upload
    Bench setup per docs/bench-wiring.md: jum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
    [main_smoketest.cpp]
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2026-04-30 feat(firmware): migrate production main.cpp to SPI HAL
    Replace the old PWM-DAC + analog-CV + digital-gate signal paths with
    calls into lib/outputs/ and lib/inputs/ (the Rob Tillaart-backed HALs
    introduced in the Story 012 scaffolding commit). Jack roles after
    the migration (per decisions.md §23 generic IN/OUT labels):
    J1 (input ch 0) → CV transpose in (was PIN_CV/A1)
    J2 (input ch 1) → second CV in (deferred — input stage ch B not yet wired)
    J3 (output ch A) → V/Oct out via inverting bipolar output stage
    J4 (output ch B) → gate out via DAC ch B (was digital PIN_GATE/D6)
    Pin migration: encoder moved D8/D9/D10 → D1/D2/D7 to free up the SPI
    bus. CS_DAC=D3, CS_ADC=D6, SPI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
    [main.cpp]
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2026-05-03 Smoke test: stream MCP3208 CH1; tempo pot validated end-to-end
    Extends the smoke-test firmware with a second ADC column (tempo_v /
    tempo_count from CH1) so any pot or CV wired to CH1 can be verified
    without re-flashing a one-shot test. Output is now:
    t_ms dac_a_v dac_b_v adc_v adc_count tempo_v tempo_count
    With the tempo pot now wired to CH1 (per the previous commit), bench
    test confirms full 12-bit range: CCW = 0/0.000 V, CW = 4090/4.095 V
    (5 LSB shy of full-scale, well within tolerance), smooth monotonic
    sweep across the rotation, no jitter or dropouts. Pot is ready for
    the production firmware to drive tempo selection with no further
    bench work.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
    [main_smoketest.cpp]
2026-05-03 Smoke test: stream encoder columns; encoder A/B swap fix
    Extends smoke-test firmware with three new columns (enc_count, click,
    long) so the encoder + click + long-press paths can be validated on the
    bench without re-flashing a one-shot test. Output line is now:
    t_ms dac_a_v dac_b_v adc_v adc_count tempo_v tempo_count \
    enc_count click long
    Bench-validated tonight on the freshly-wired PEC11R: CW = +13 over a
    short rotation, CCW = -7, three quick taps = 3 click pulses (debouncer
    correctly registers each tap as exactly one pulse), one ~1 s hold =
    1 long pulse with 0 short clicks (long-press suppression for the same
    gesture).
    Encoder A/B were swapped in firmware after the be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
    [main.cpp, main_smoketest.cpp]
2026-05-03 Smoke test: OLED probe; encoder switched to interrupt-driven decoding
    Smoke-test firmware now probes the SSD1306 OLED at boot (I2C 0x3C) and
    refreshes "ENC = N" at 10 Hz reflecting the live encoder count. Lets the
    bench rig validate the OLED end-to-end without flashing production.
    While bringing up the OLED, the bench revealed a polling-rate problem:
    fast rotations through ~20 detents only registered ~7 in the count
    display. The mathertel/RotaryEncoder library was being called once per
    main-loop iteration, but the loop's per-iteration work (DAC + ADC +
    serial + ~5 ms OLED I2C blast every 100 ms) had grown enough that fast
    detent transitions were being missed.
    Fix: switched EncoderInput to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
    [main_smoketest.cpp]
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2026-05-04 KiCad input stage: review-driven schematic refinements
    Updates from the 2026-05-03 schematic review:
    - Net `input tip a/b` renamed to `clamp_a/clamp_b` (more accurate --
    it's the protection node *after* R_series, not the jack tip itself).
    - Local 100nF decoupling cap (C5) added directly across U1 V+/V- pins
    for fast op-amp transient response, in addition to the existing
    bulk caps on the +/-12V rails (C1/C2).
    - Per-channel 100nF filter caps (C3/C4) on each bias-divider node to
    knock down any high-frequency noise riding on VREF before it reaches
    the op-amp non-inverting inputs.
    - Schottky clamps switched from generic D_Schottky symbol to the
    BAT54S 3-pin series-pair (A=pin1, K=pin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
    [gio-opamp.kicad_sch]
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2026-05-04 Revert encoder A/B firmware swap; align with schematic
    The 2026-05-02 PIN_ENC_A=D2 / PIN_ENC_B=D1 swap was a firmware
    workaround for the bench encoder reading CW as a negative delta with
    the original A->D1, B->D2 wiring. On 2026-05-04 the breadboard wires
    were physically swapped to match the KiCad schematic's natural
    assignment, so firmware can now use the original (and schematic-
    matching) PIN_ENC_A=D1, PIN_ENC_B=D2. CW still reads positive --
    same observable behavior, just responsibility for the swap moved
    from firmware to the breadboard.
    Convention is now consistent across schematic, bench wiring, and
    firmware:
    encoder pin A -> XIAO D1 (GP27)
    encoder pin B -> XIAO D2 (GP28)
    encoder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
    [main.cpp, main_smoketest.cpp]
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2026-05-23 Fix stale Seeed_Studio_XIAO_Series footprint property in schematic
    The XIAO RP2350's schematic Footprint property pointed at
    Seeed_Studio_XIAO_Series:XIAO-RP2350-DIP, but the PCB itself uses
    my_kicad_library:XIAO-RP2350-DIP_pins_only. The mismatch was harmless
    in practice (the PCB drives layout) but kept the stale lib registered.
    Point the property at the footprint the PCB actually uses, so the
    global sym-lib-table entry for Seeed_Studio_XIAO_Series can be dropped.
    [gio.kicad_sch]
2026-05-24 Hardware Rev 1.1: PCB routing finalized + schematic wire cleanup
    Rev 1.1 captures the PCB layout state the user is ready to manufacture
    the next batch from. Builds on the Rev 1 bring-up findings (board
    electrically validated end-to-end; OLED footprint bug + ADC input
    protection captured as Rev 2 to-do items in docs/bench-log.md).
    [gio.kicad_pcb, gio.kicad_sch]
2026-05-24 Firmware: arduino-pico 5.6.0, Wire1 OLED fix, boot diagnostics
    Three interlocking changes from the 2026-05-23 bench session, where
    the production arp firmware refused to boot or display on board #2.
    1. arduino-pico framework pinned 4.4.0 → 5.6.0. Mid-session, our 4.4.0
    builds started producing UF2s that don't boot on stock XIAO RP2350
    boards (no USB CDC output, no OLED — completely silent). Old 4.4.0
    builds already on boards still ran fine; new ones did not. Root cause
    never pinned down (likely transitive dependency drift in the unpinned
    platform-raspberrypi / picotool chain). 5.6.0 builds boot cleanly.
    2. OLED moved from Wire to Wire1 in lib/oled_ui/. arduino-pico 5.6.0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
    [main.cpp, main_minimal.cpp]
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2026-05-30 Firmware: external clock-in on Input A + diagnostics cleanup
    pollExternalClockEdge() was a stub returning false — external clock was
    never implemented, so feeding a clock into Input A did nothing and the
    OLED stayed on INT. Now it reads Input A (J1 / MCP3208 CH1) through a
    Schmitt trigger and, crucially, stamps extLastEdgeMs on each rising edge
    — that timestamp is what externalClockActive() keys off to auto-switch
    INT->EXT. (The first detection pass detected edges but never stamped the
    timestamp, so the mode never flipped; this fix completes the wiring.)
    Detection details: the input op-amp stage is inverting, so a +5 V clock
    pulls the ADC reading to ~1.06 V (idle ~1.97 V). Assert < 1.50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
    [main.cpp]
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2026-05-30 Firmware: explicit CLOCK param, OCT range, jack-role lockdown
    - CLOCK encoder param (EXT/INT, default EXT) replaces auto-fallback;
    arp sits silent in EXT until clock arrives, INT strictly ignores J1.
    - Arp resets after EXT_CLOCK_RESET_MS (2 s) of clock silence — returning
    pulse starts pattern from note 1, no stale-period interpolation burst.
    - Canonical jack roles locked in for the arp app: J1=clock, J2=CV in
    (V/oct transpose), J3=CV out, J4=trigger out. CV transpose moved off
    the dual-purpose J1 (silently broken in EXT mode) onto J2.
    - OCT param (1..4) stacks CHORD_INTERVALS across N octaves with
    consecutive-duplicate dedup at octave boundaries.
    - MIDI_NOTE_MAX 96 → 120 — to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
    [main.cpp]
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
